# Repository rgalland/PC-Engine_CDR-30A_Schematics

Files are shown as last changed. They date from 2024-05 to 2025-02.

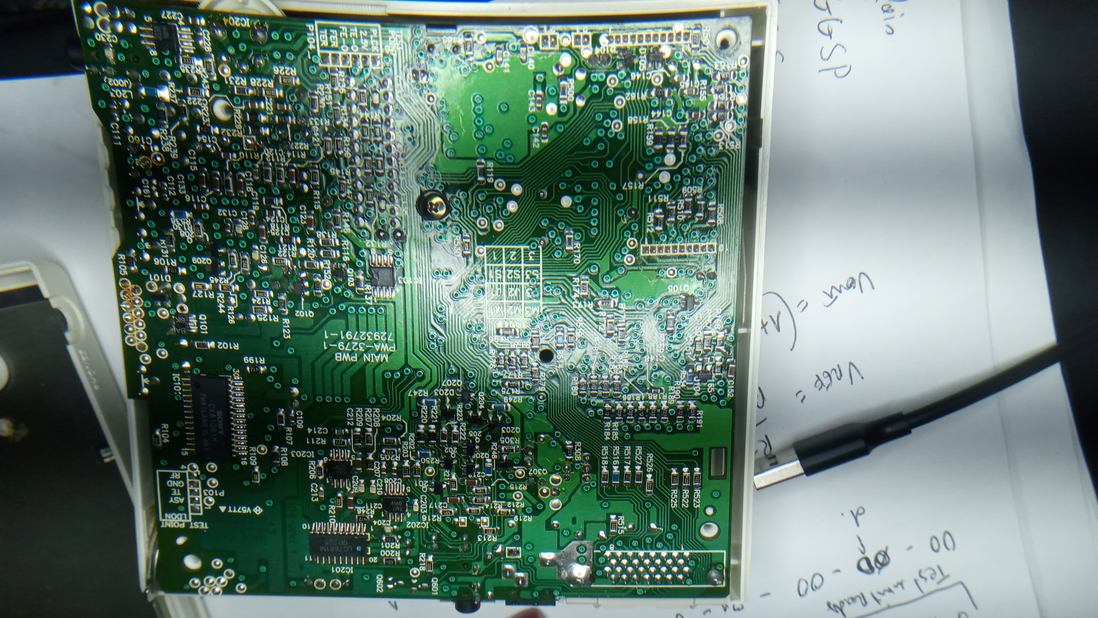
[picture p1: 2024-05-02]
Photos/IMG_20240307_151211.jpg

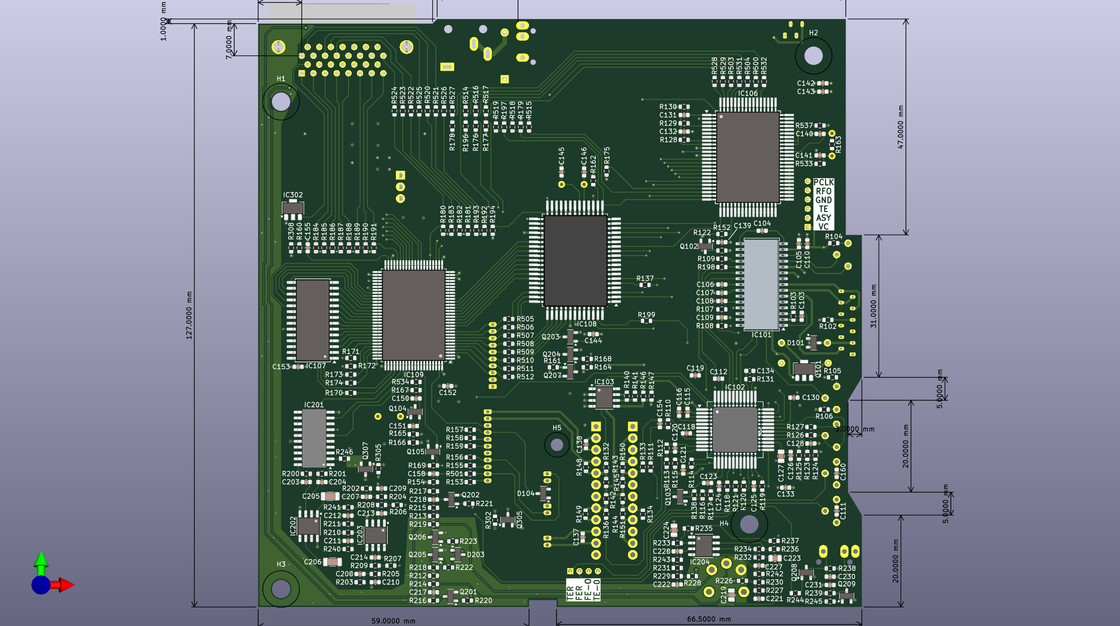
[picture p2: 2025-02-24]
Reproduction_PCBs/Main_PCB/Main_PCB_Bottom.png

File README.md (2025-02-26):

This repository contains reverse engineering information regarding the PC-Engine CD-ROM2.

It started with the schematics of the main and front PCBs but has now evolve to provide reproduction parts. In the schematics, I attempted to highlight the differences between the CDR-30 (older models) and the CDR-30A but I have even found PCB differences within the newer CDR-30A units. Main difference is the use of the Sony DSP CXD1135 + external RAM as opposed to CXD1167 without additional RAM.
Currently available reproduction parts are the 2 flexible PCBs on the KSS-220A laser module. These are not compatible with the KSS-162A found mainly on older units. The main PCB is at the prototype level at the moment.

You will need kicad to work with files but I also provide pdf files to view the schematics in a more convenent way.

Current versions:
Original PCBs:
	- MAIN_PWR schematics: Rev0.3
	- FRONT_PWB schematics: Rev0.1
	
Reproduction PCBs:
	- KSS-220A Focus Tracking Flex PCB schematics and layout: Rev0.1
	- KSS-220A Lens Flex PCB schematics and layout: Rev0.1
	- Main PCB schematics and layout: Rev0.1

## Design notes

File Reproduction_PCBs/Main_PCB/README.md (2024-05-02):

# PC-Engine_CDR-30A_Schematics
Schematics of the PC-Engine CD-ROM2 - Includes comments about differences between CDR-30A and the older CDR-30

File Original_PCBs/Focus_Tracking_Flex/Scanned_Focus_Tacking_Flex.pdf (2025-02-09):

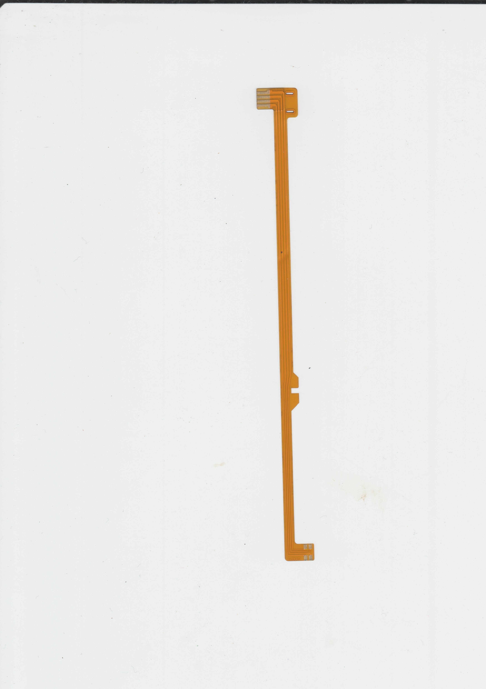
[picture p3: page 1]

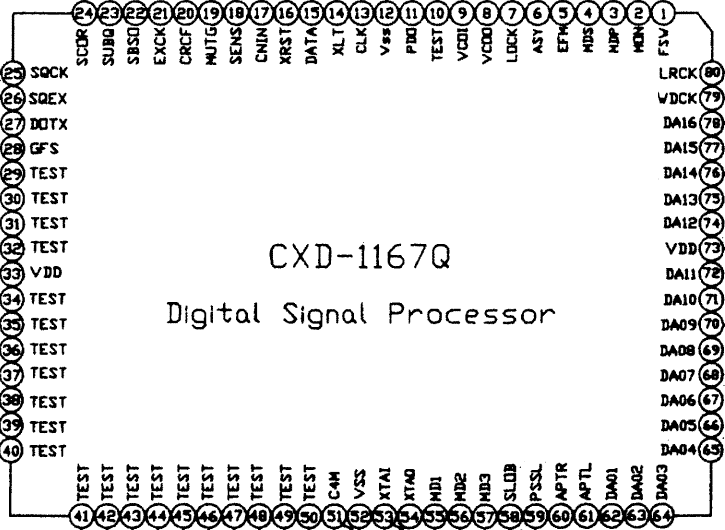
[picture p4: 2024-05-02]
Datasheets/CXD1167/CXD1167Q-pinout.png

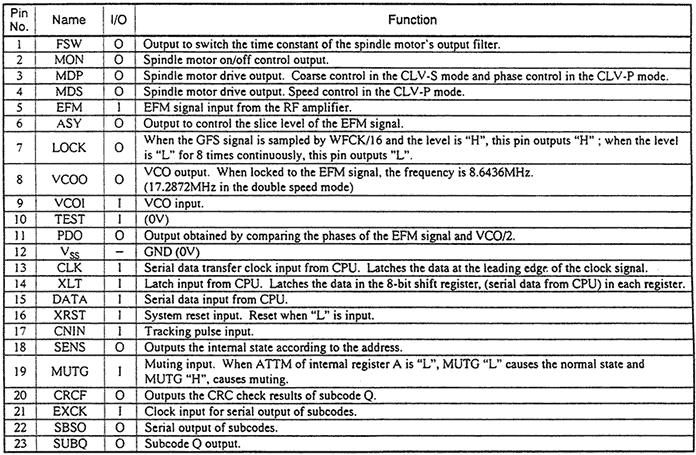
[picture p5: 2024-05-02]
Datasheets/CXD1167/CXD1167-Pin-Functions-1.png

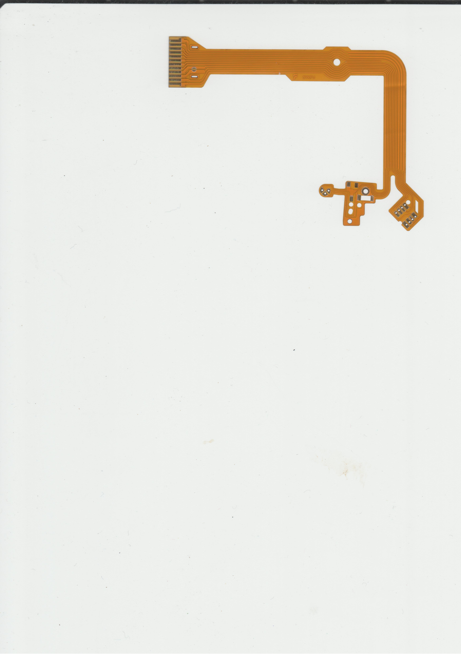
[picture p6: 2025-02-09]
Original_PCBs/Lens_Flex/Scanned_Lens_Flex.png

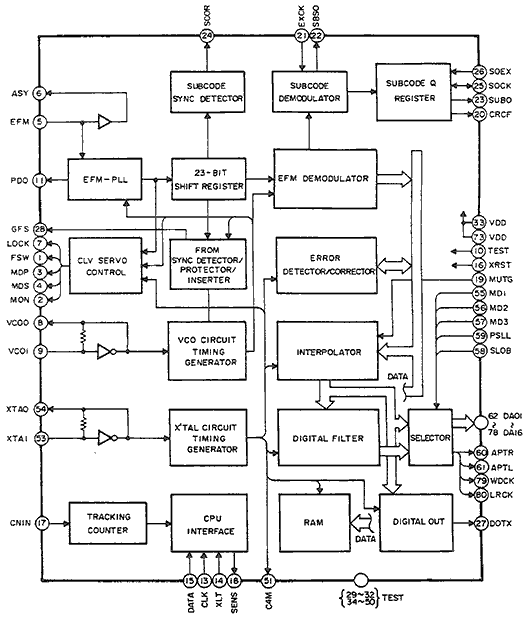
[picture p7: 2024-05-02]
Datasheets/CXD1167/CXD1167-Block-Diagram.png

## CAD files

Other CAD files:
Original_PCBs/Focus_Tracking_Flex/Focus_Tracking_Flex.FCStd
Original_PCBs/Lens_Flex/Lens_Flex.FCStd
Original_PCBs/Focus_Tracking_Flex/flex_focus_tracking_dxf.FCStd
Original_PCBs/Focus_Tracking_Flex/Focus_Tracking_Flex.dxf
Original_PCBs/Lens_Flex/Lens_Flex.dxf

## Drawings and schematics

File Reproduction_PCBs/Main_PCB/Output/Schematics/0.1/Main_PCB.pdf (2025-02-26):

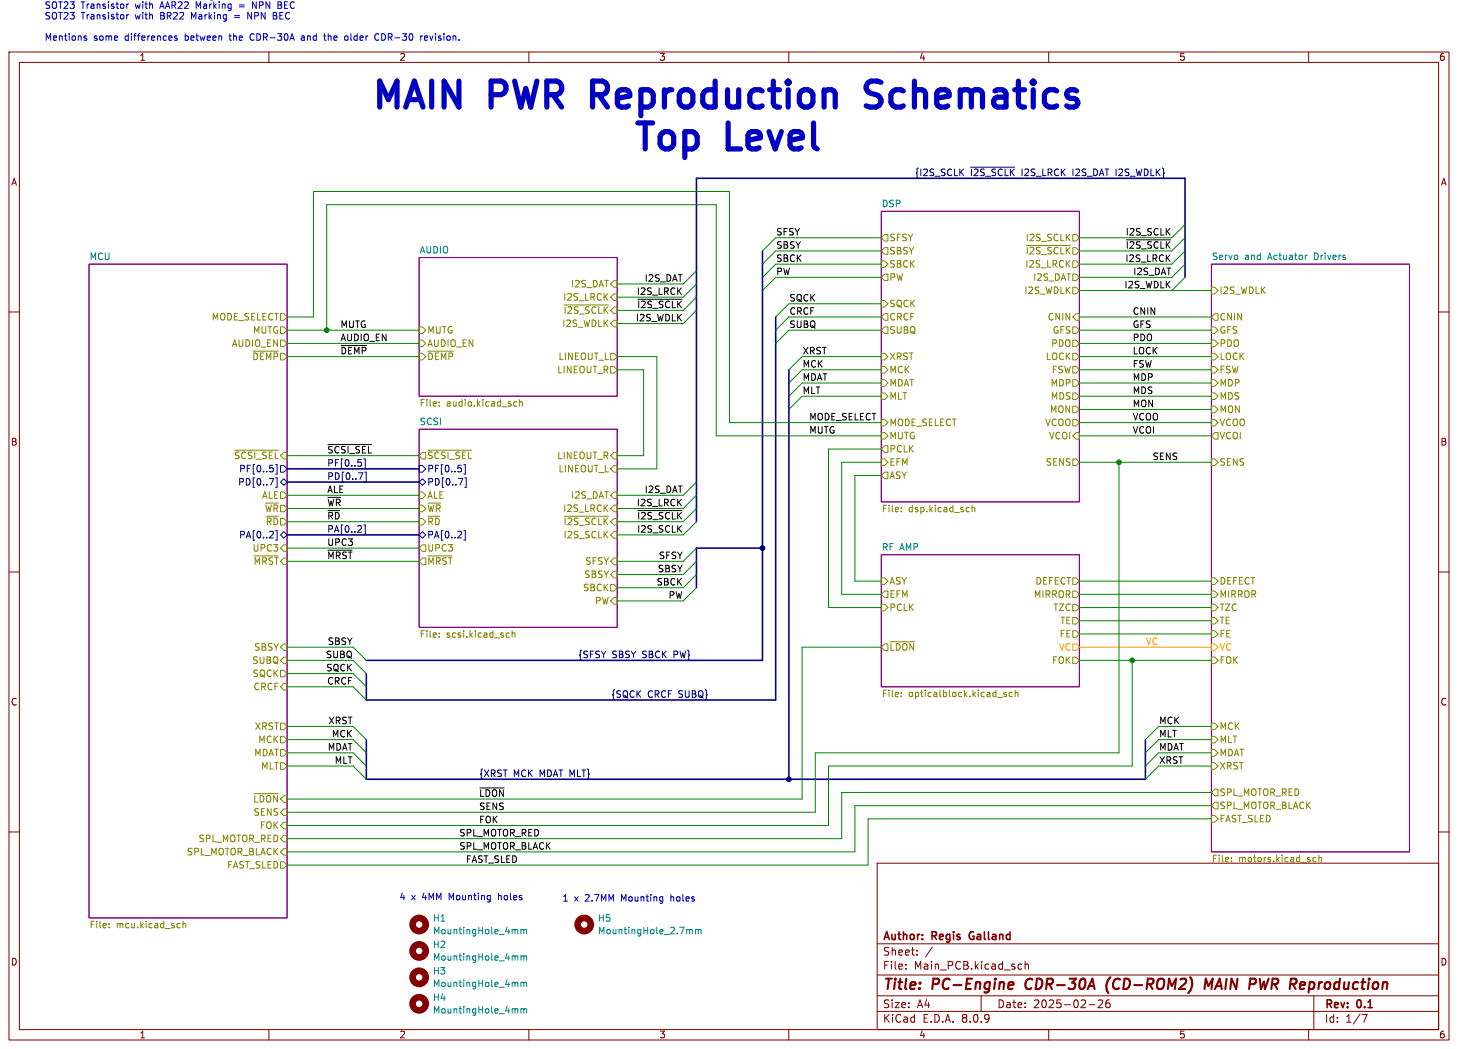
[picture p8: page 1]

1 x 2.7MM Mounting holes MAIN PWR Reproduction Schematics

Servo and Actuator Drivers

GFS CNIN
SENS MDP MON MDS

I2S_DAT AUDIO_EN
LOCK CRCF
SQCK UPC3 ~{SCSI_SEL} CRCF MLT
~{LDON} MDAT XRST PA[0..2] FOK

SBSY
SUBQ
{SQCK CRCF SUBQ} SQCK

{SFSY SBSY SBCK PW}

SPL_MOTOR_BLACK MDAT XRST MCK MLT
SENS MCK

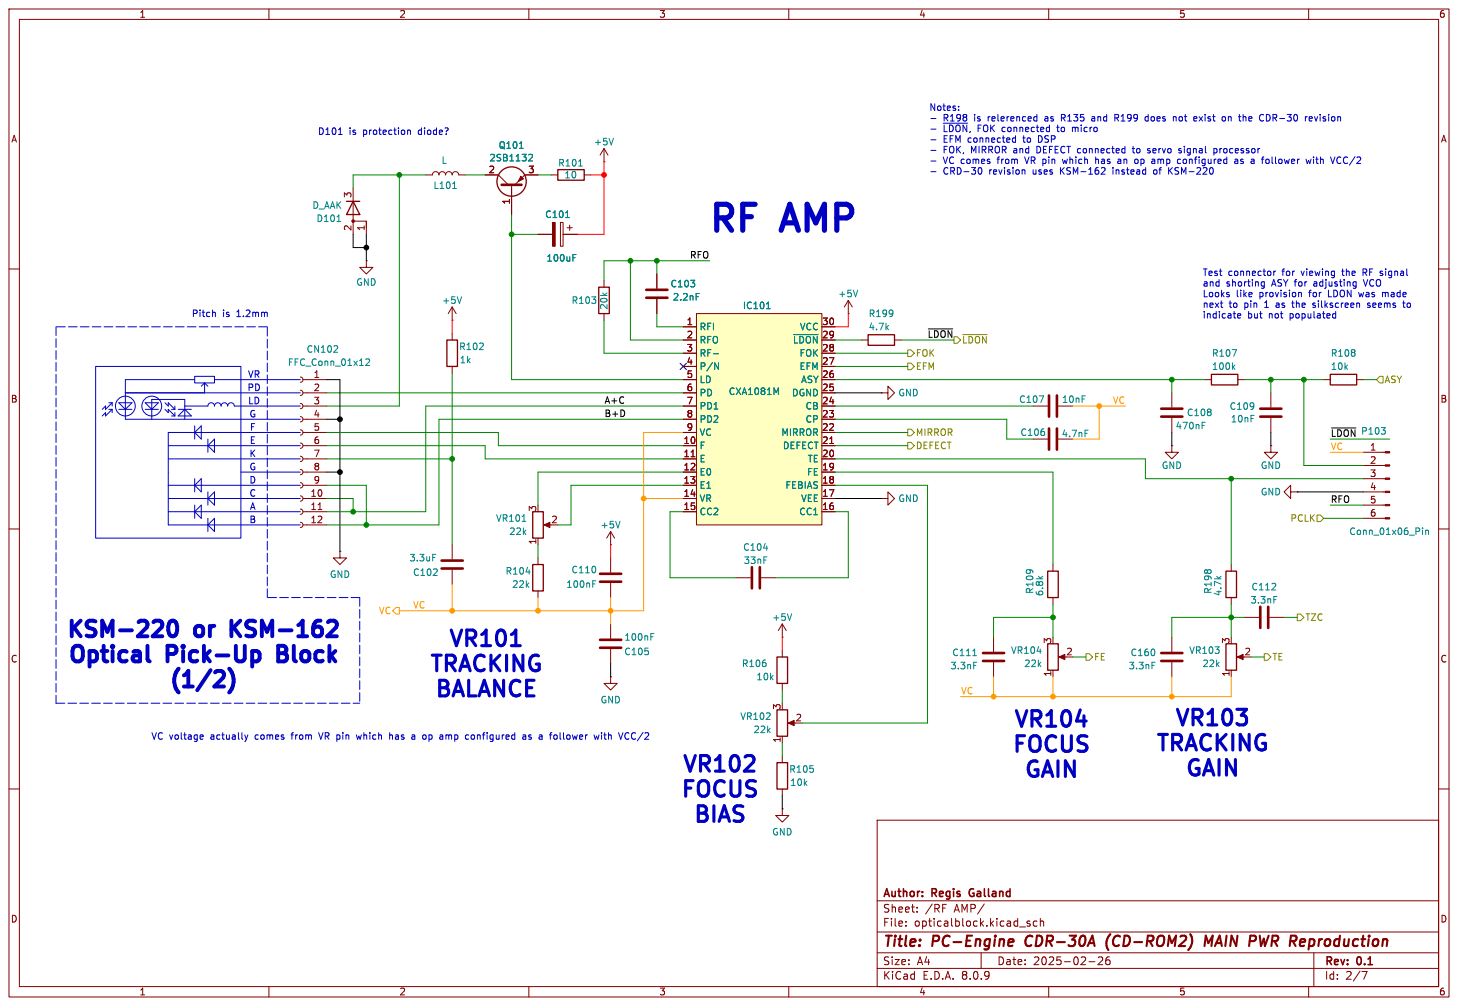
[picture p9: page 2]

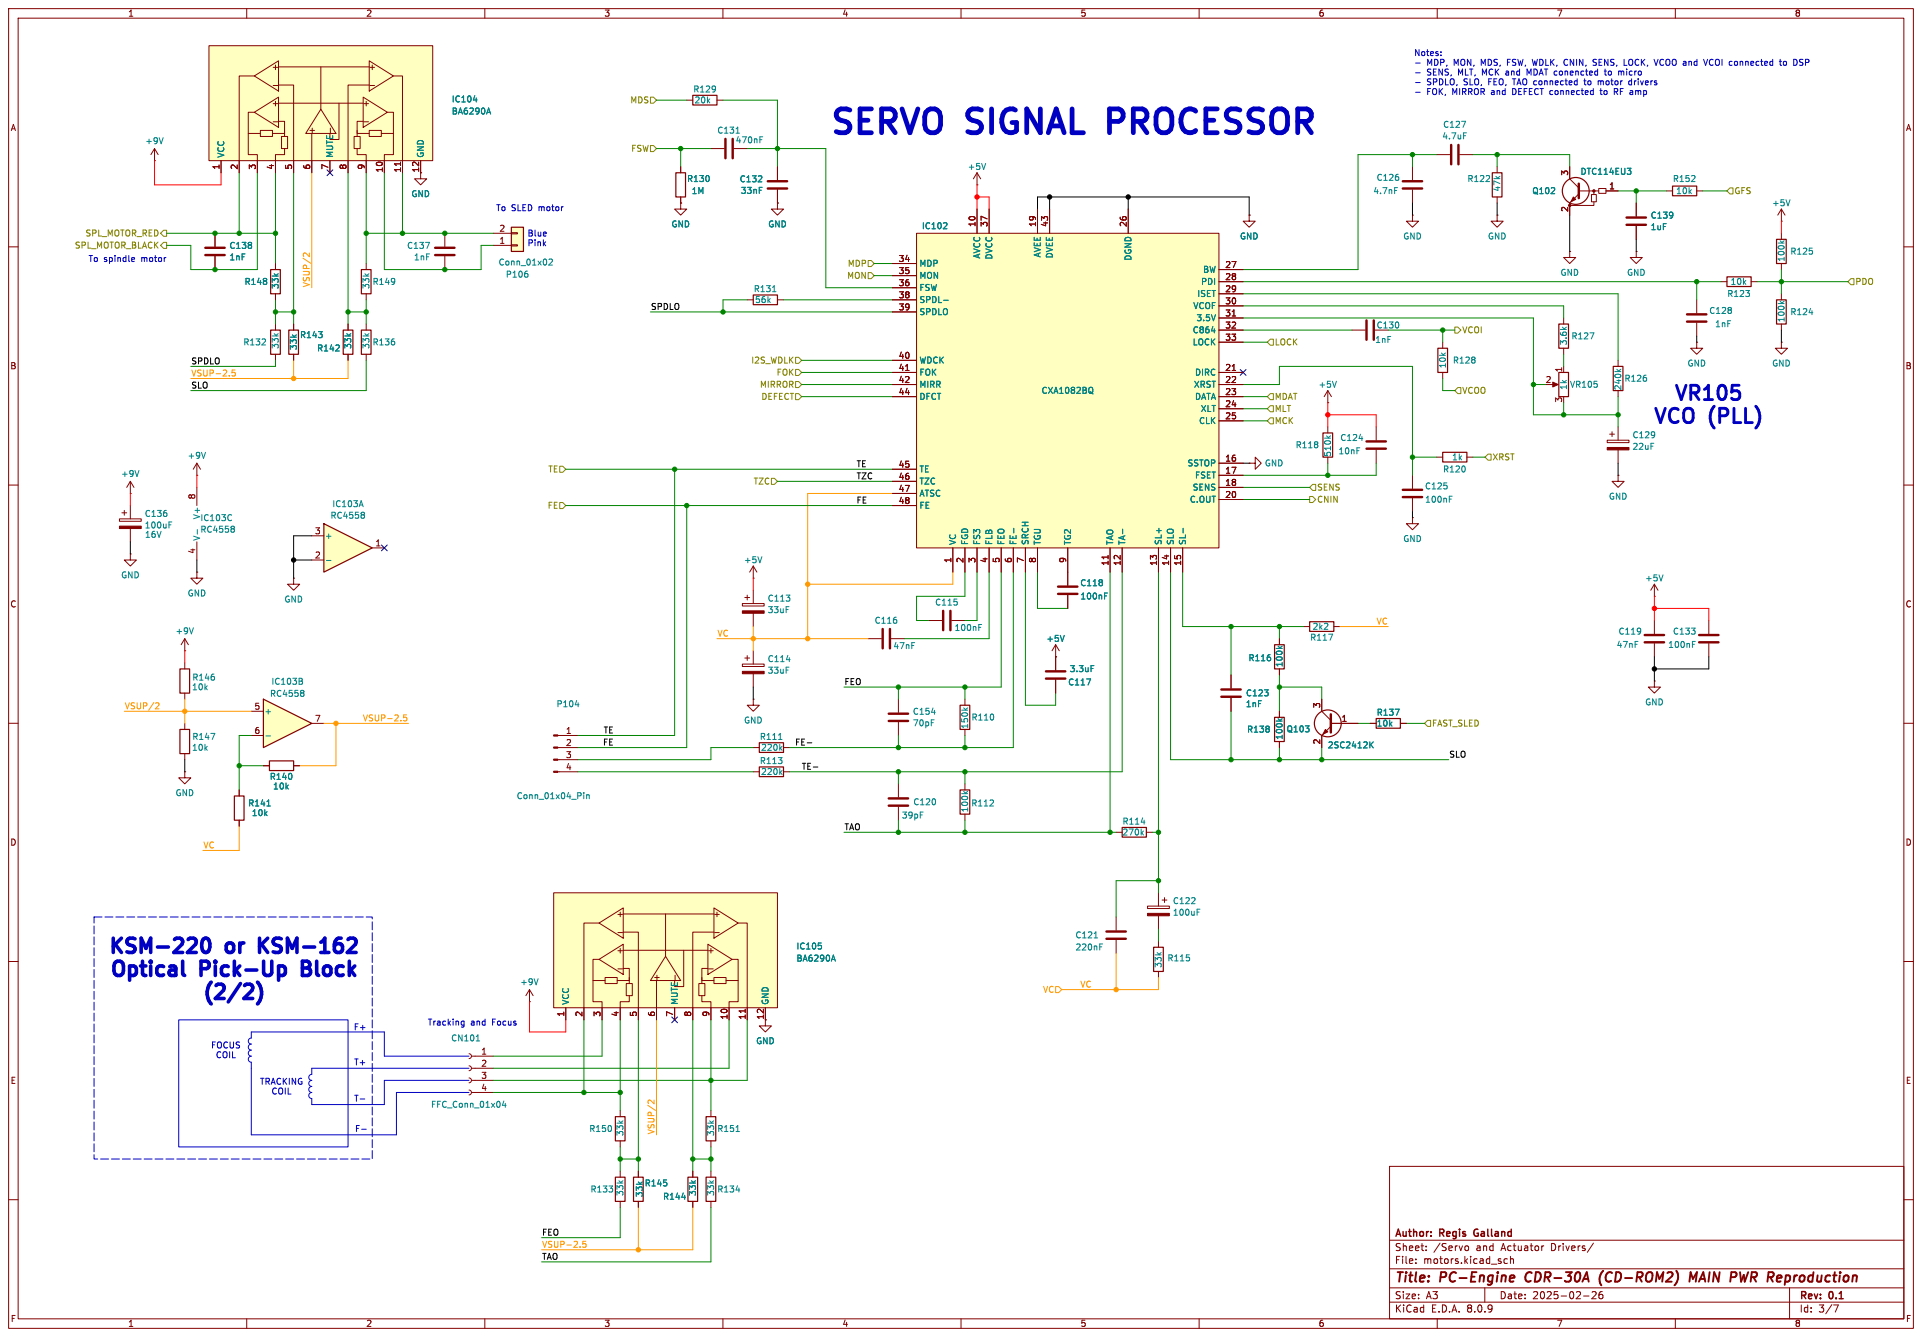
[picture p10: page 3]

Blue Pink To SLED motor

4 WDCK 40 FOK 41 MIRR 42 DVEE 43 DFCT 44 TE 45 TZC 46 ATSC 47 FE 48 FEO

1 AVCC 10 TAO 11 TA- 12 SL+ 13 SLO 14 SL- 15 SSTOP 16 FSET 17 SENS 18 AVEE 19 FGD

2 C.OUT 20 DIRC 21 XRST 22 DATA 23 XLT 24 CLK 25 DGND 26 BW 27 PDI 28

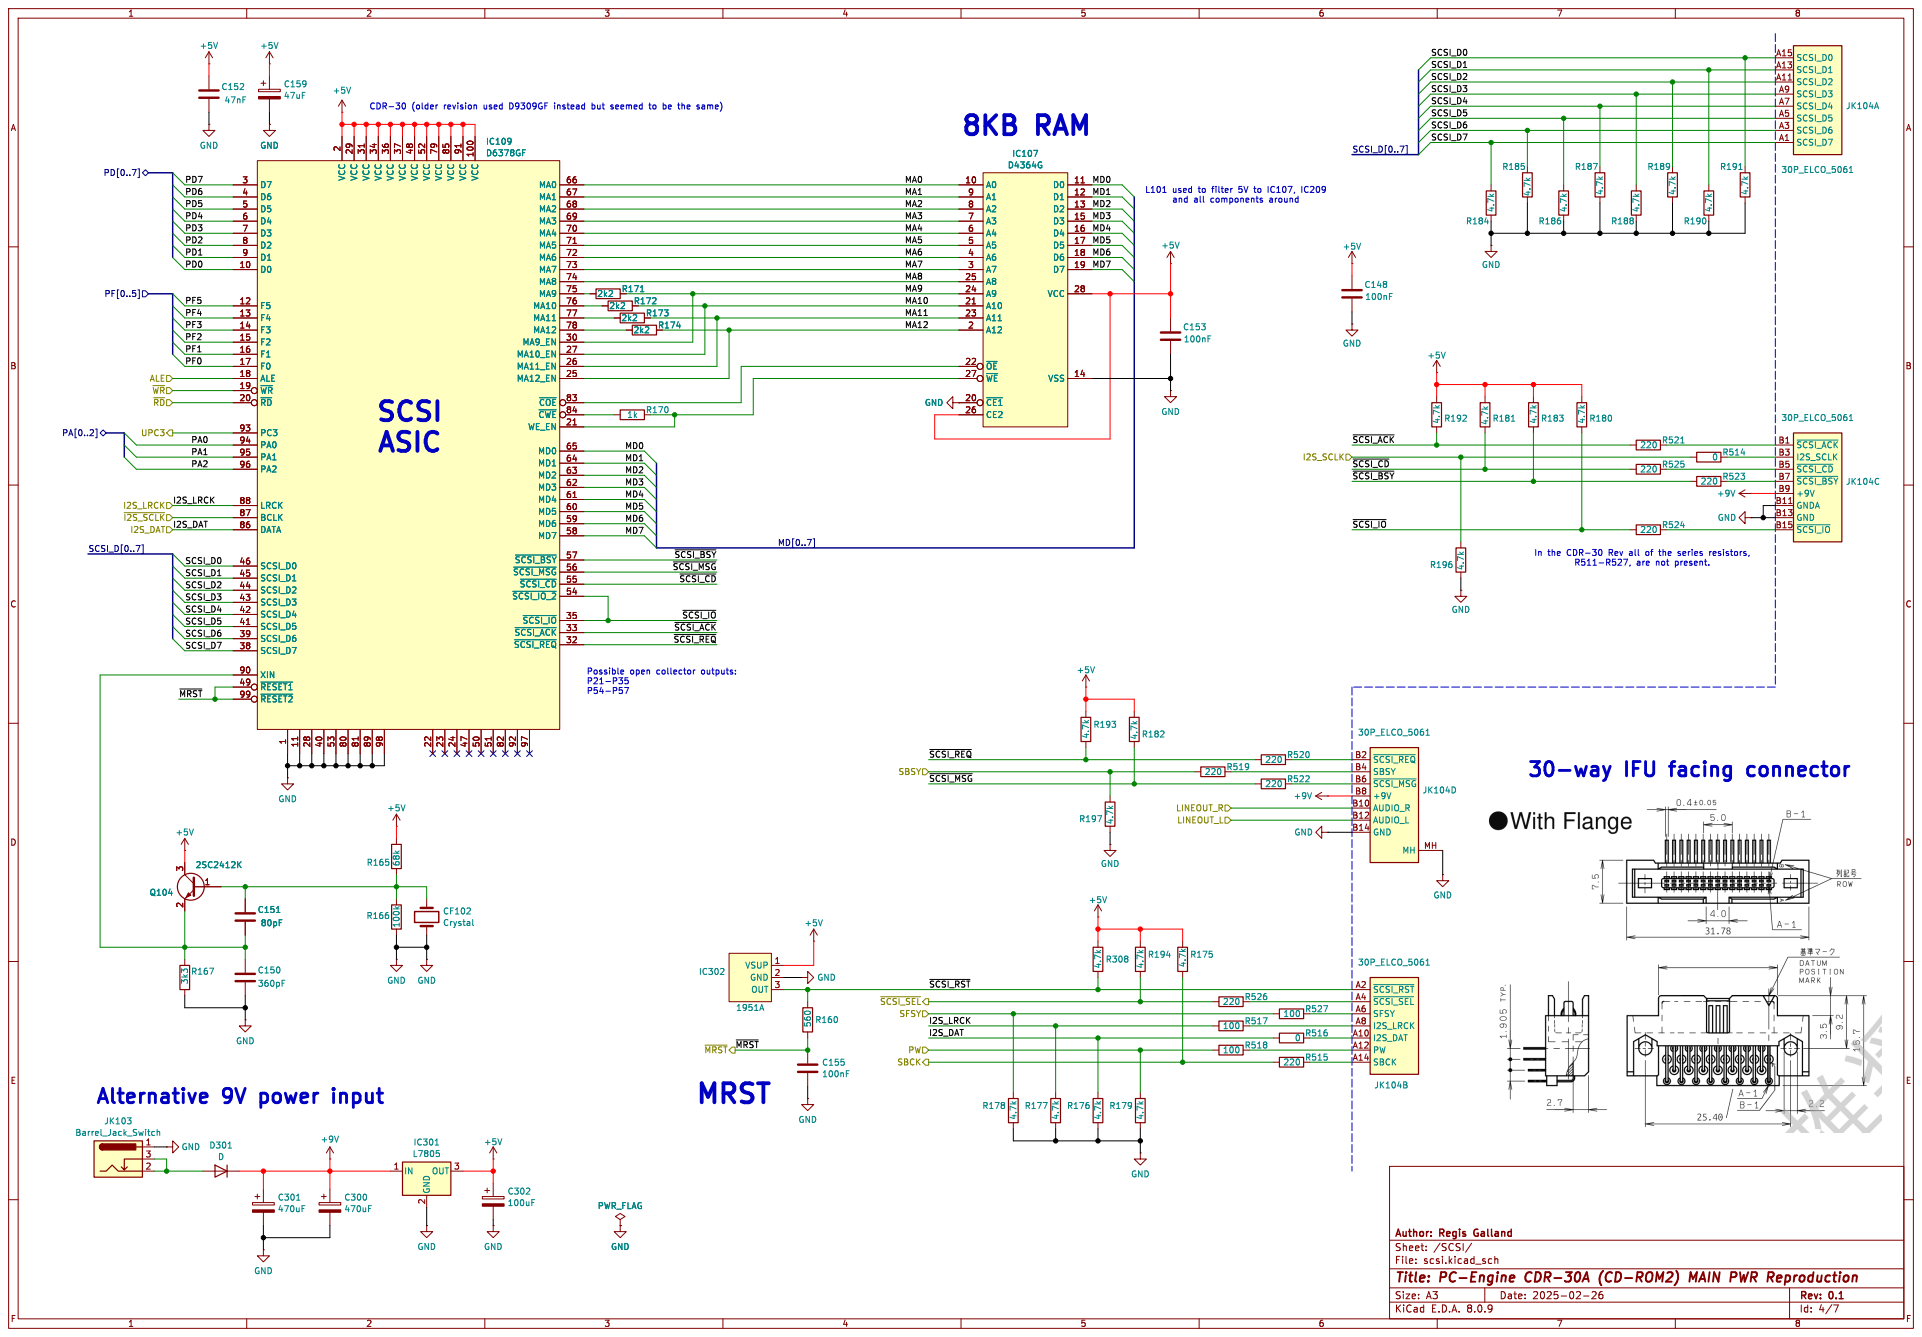
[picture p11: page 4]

1 D0 10 VCC 100 11 F5 12 F4 13 F3 14 F2 15 F1 16 F0 17 ALE 18 ~{WR} 19 VCC

~{COE}83 ~{CWE}84 VCC 85 DATA 86 BCLK 87

2 ~{RD} 20 WE_EN 21 222324 MA12_EN 25 MA11_EN 26 MA10_EN 27 28 VCC 29 D7 3 MA9_EN 30 VCC 31 ~{SCSI_REQ}32 ~{SCSI_ACK}33 VCC 34

L101 used to filter 5V to IC107, IC209

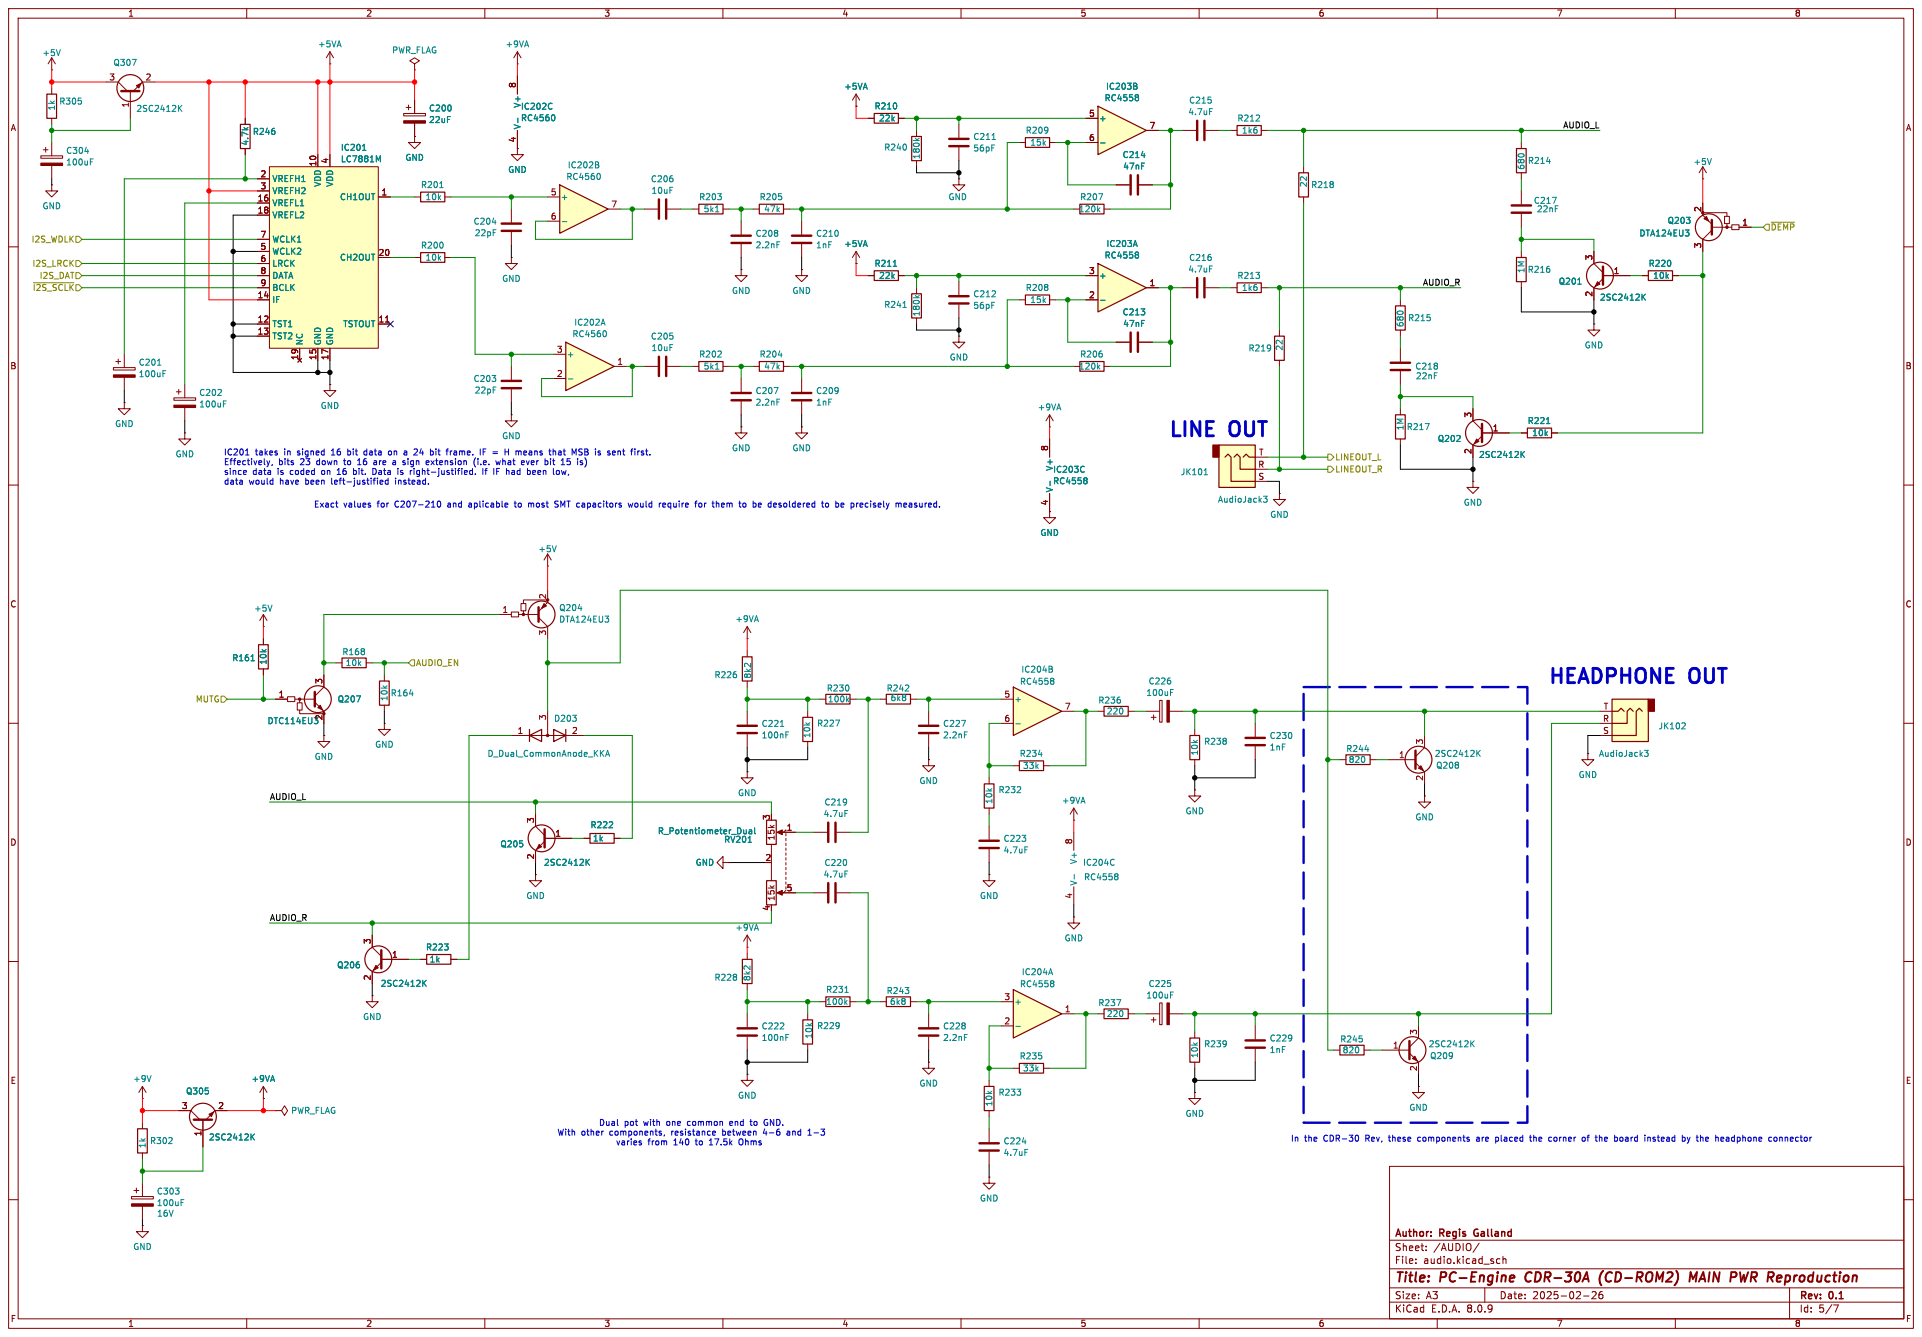
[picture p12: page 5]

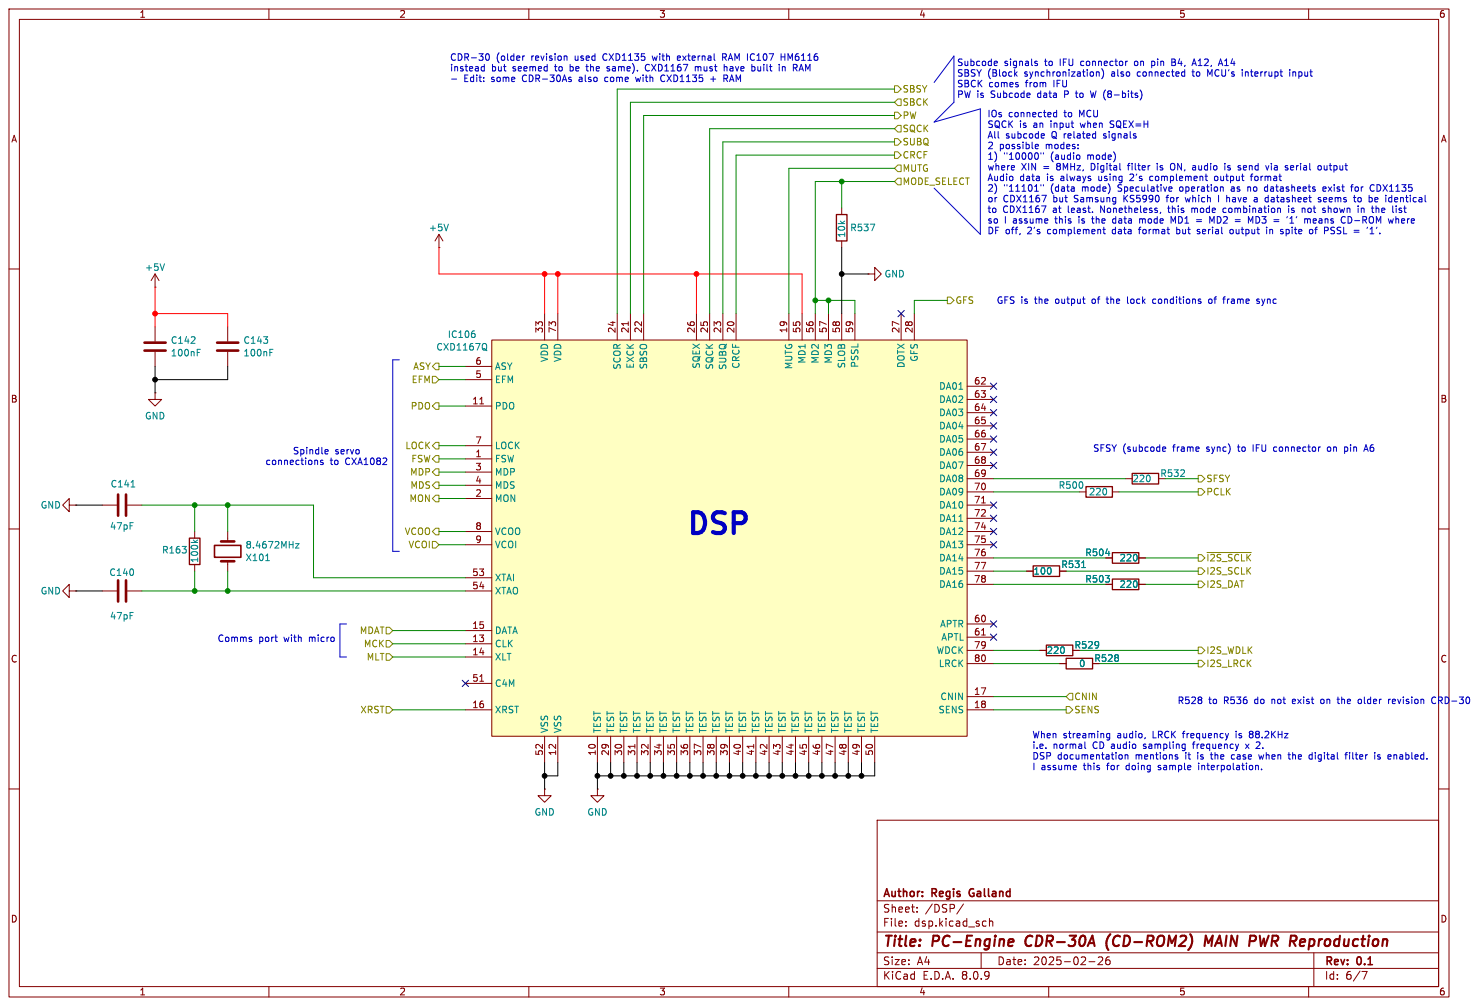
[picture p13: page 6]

instead but seemed to be the same). CXD1167 must have built in RAM
SFSY MODE_SELECT MUTG

SQCK is an input when SQEX=H

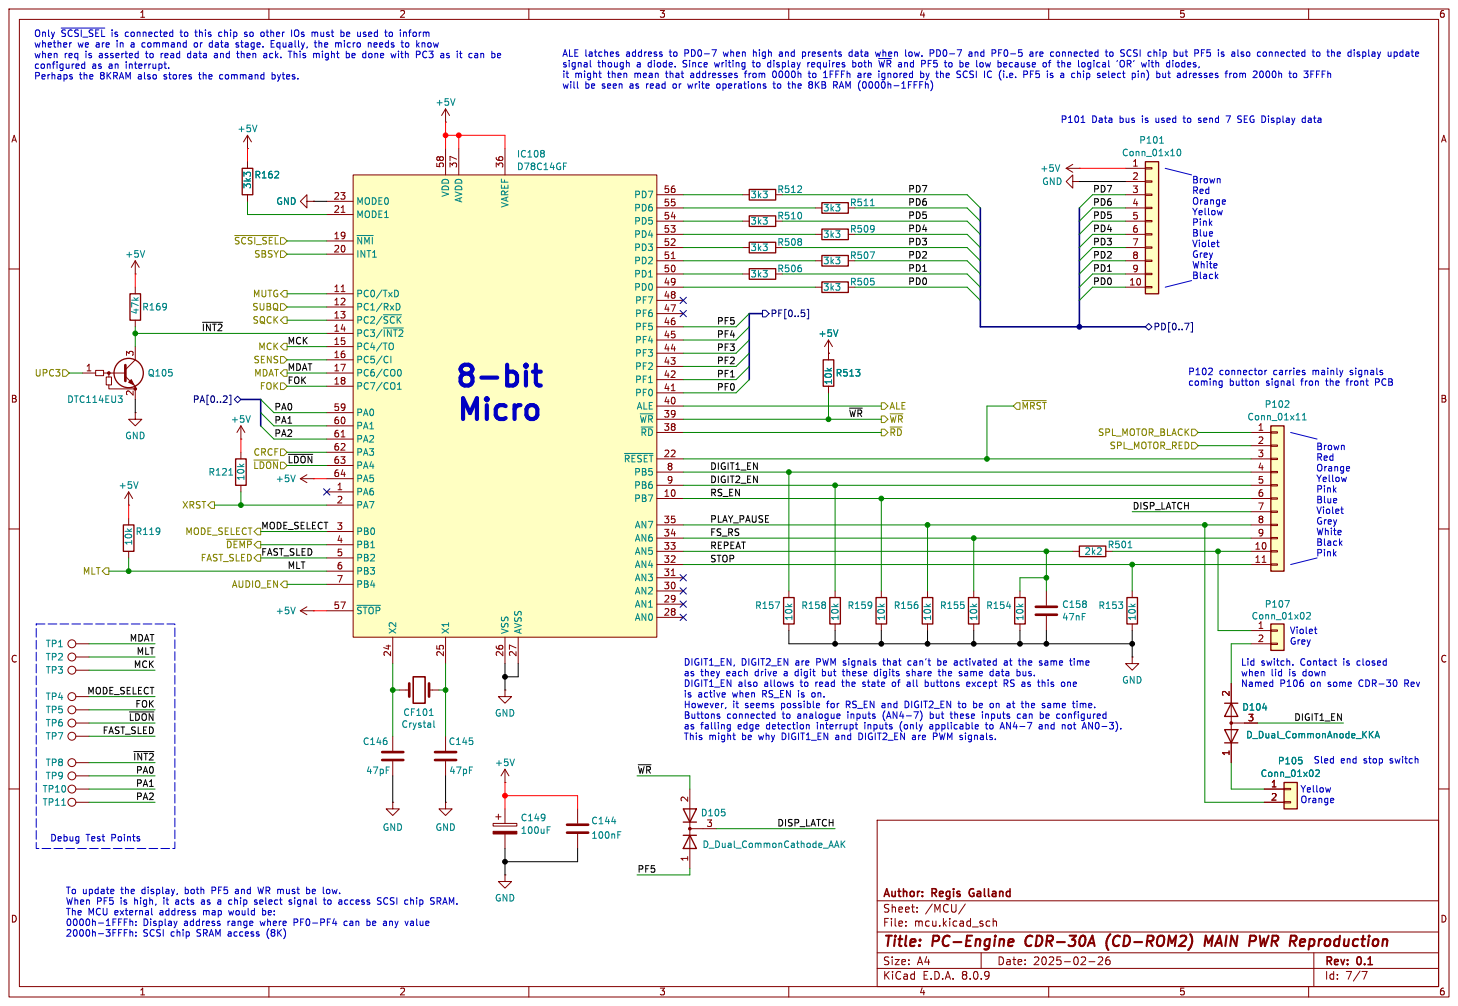
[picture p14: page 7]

whether we are in a command or data stage. Equally, the micro needs to know
when req is asserted to read data and then ack. This might be done with PC3 as it can be
~{SCSI_SEL} XRST
FOK MDAT SBSY

Brown Red Orange Yellow

Pink Blue Violet Grey White Black 8-bit

coming button signal fron the front PCB

Yellow Orange Sled end stop switch Violet Grey

as they each drive a digit but these digits share the same data bus. DIGIT1_EN also allows to read the state of all buttons except RS as this one

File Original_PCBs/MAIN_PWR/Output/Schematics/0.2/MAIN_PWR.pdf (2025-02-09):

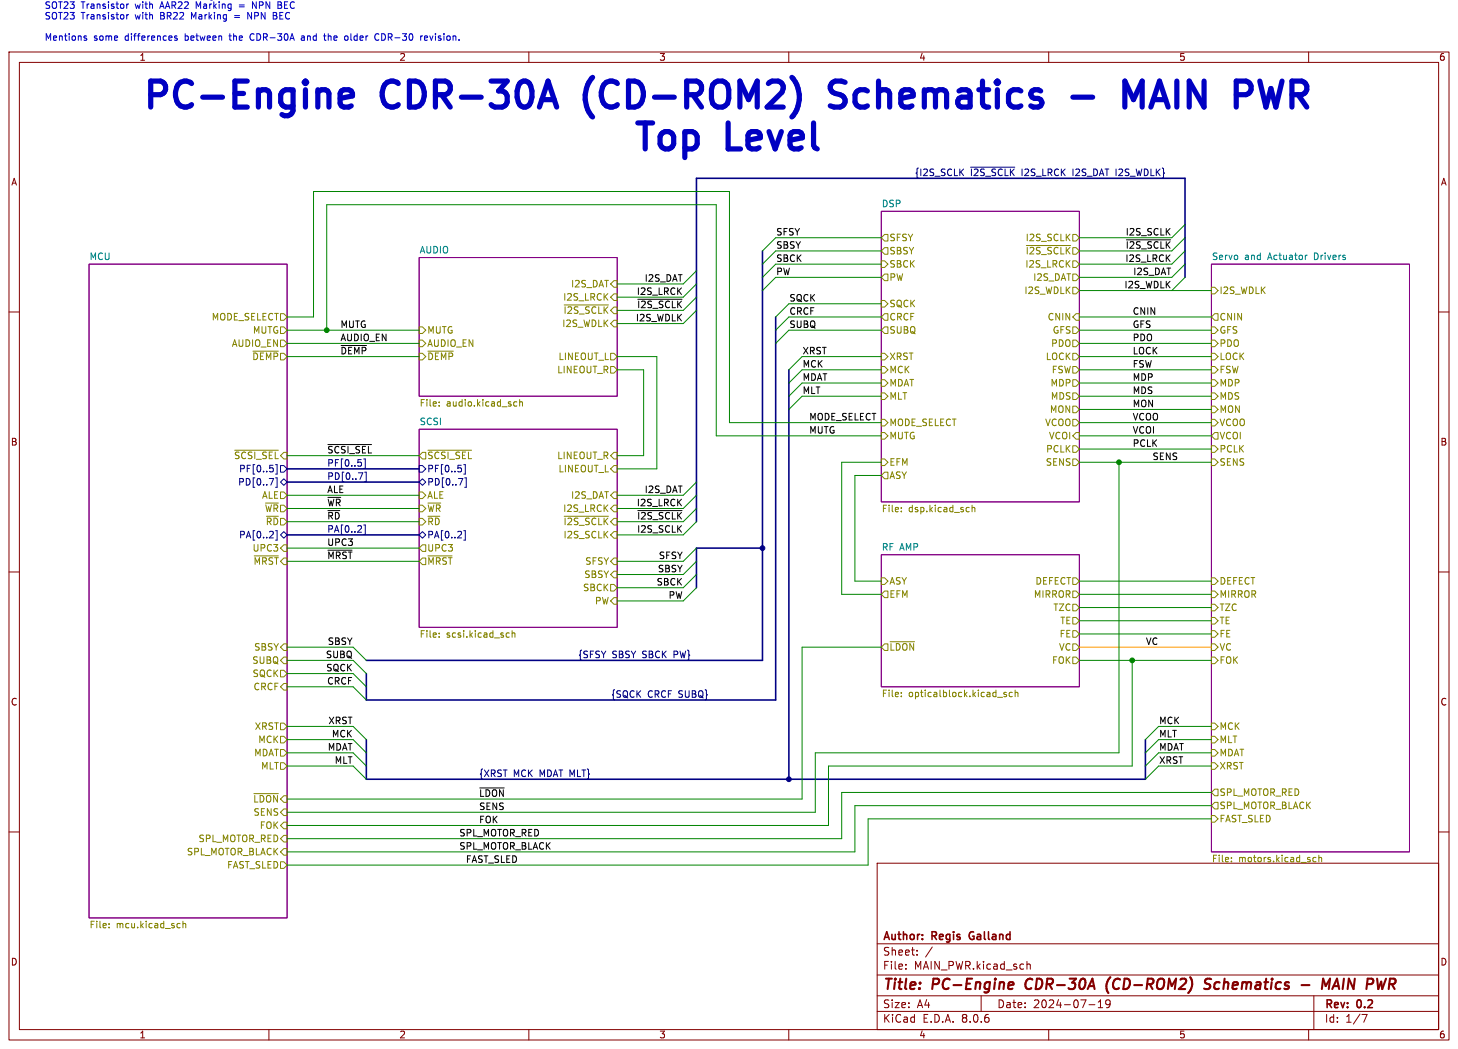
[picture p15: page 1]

Servo and Actuator Drivers

I2S_WDLK
VCOO MON MDS CNIN GFS

SQCK UPC3 ~{SCSI_SEL} CRCF MLT
~{LDON} MDAT XRST PA[0..2] FOK

{SFSY SBSY SBCK PW}

{XRST MCK MDAT MLT}

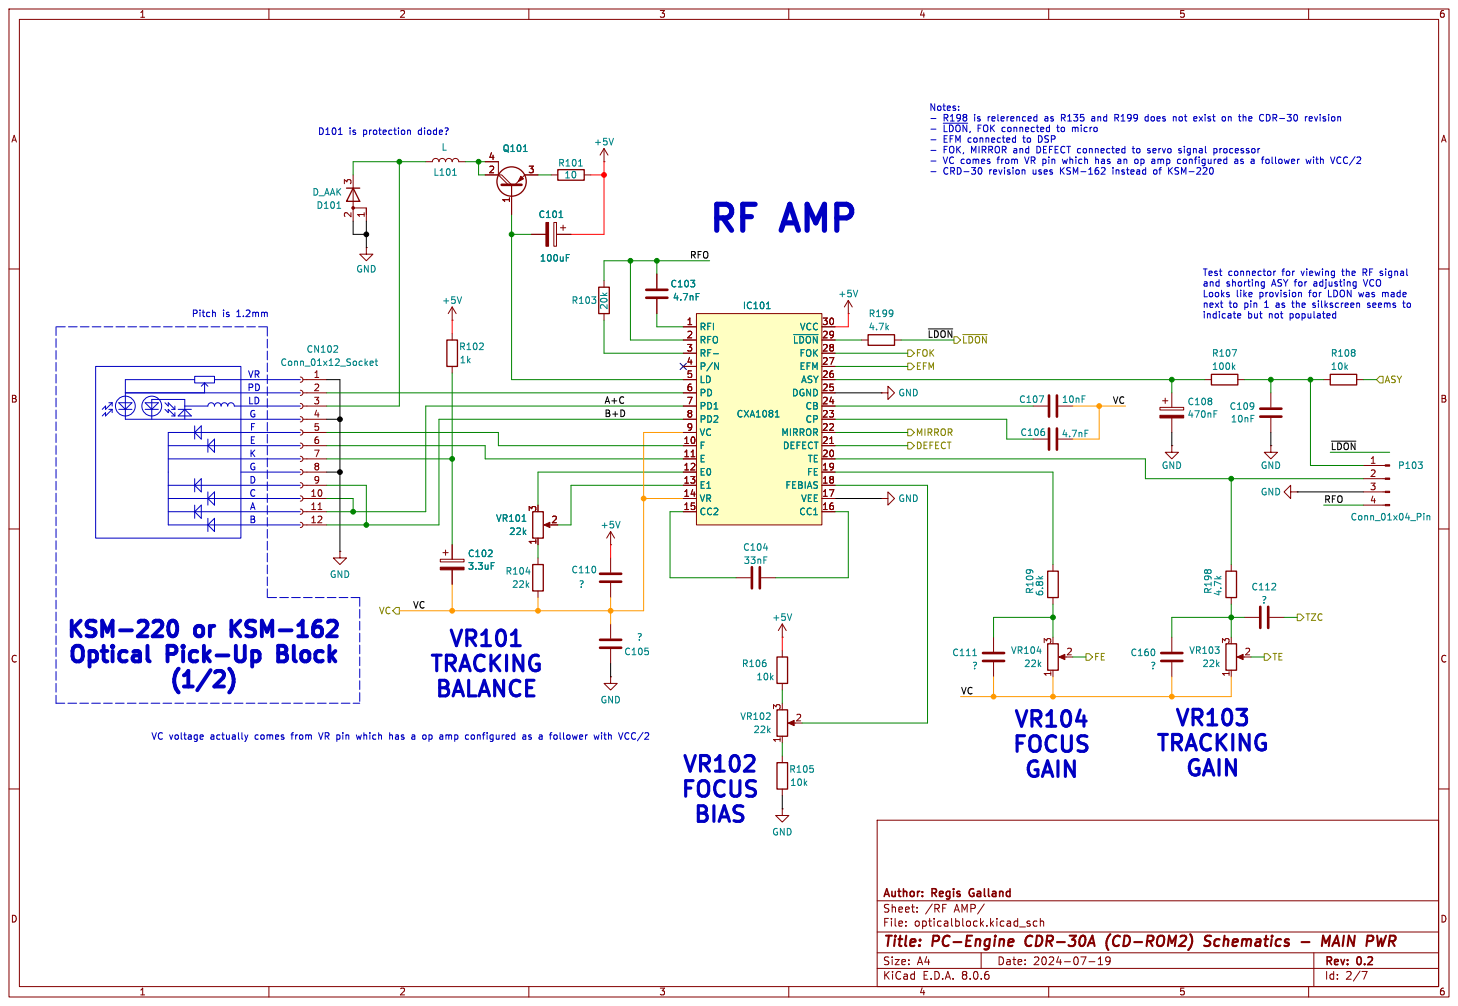
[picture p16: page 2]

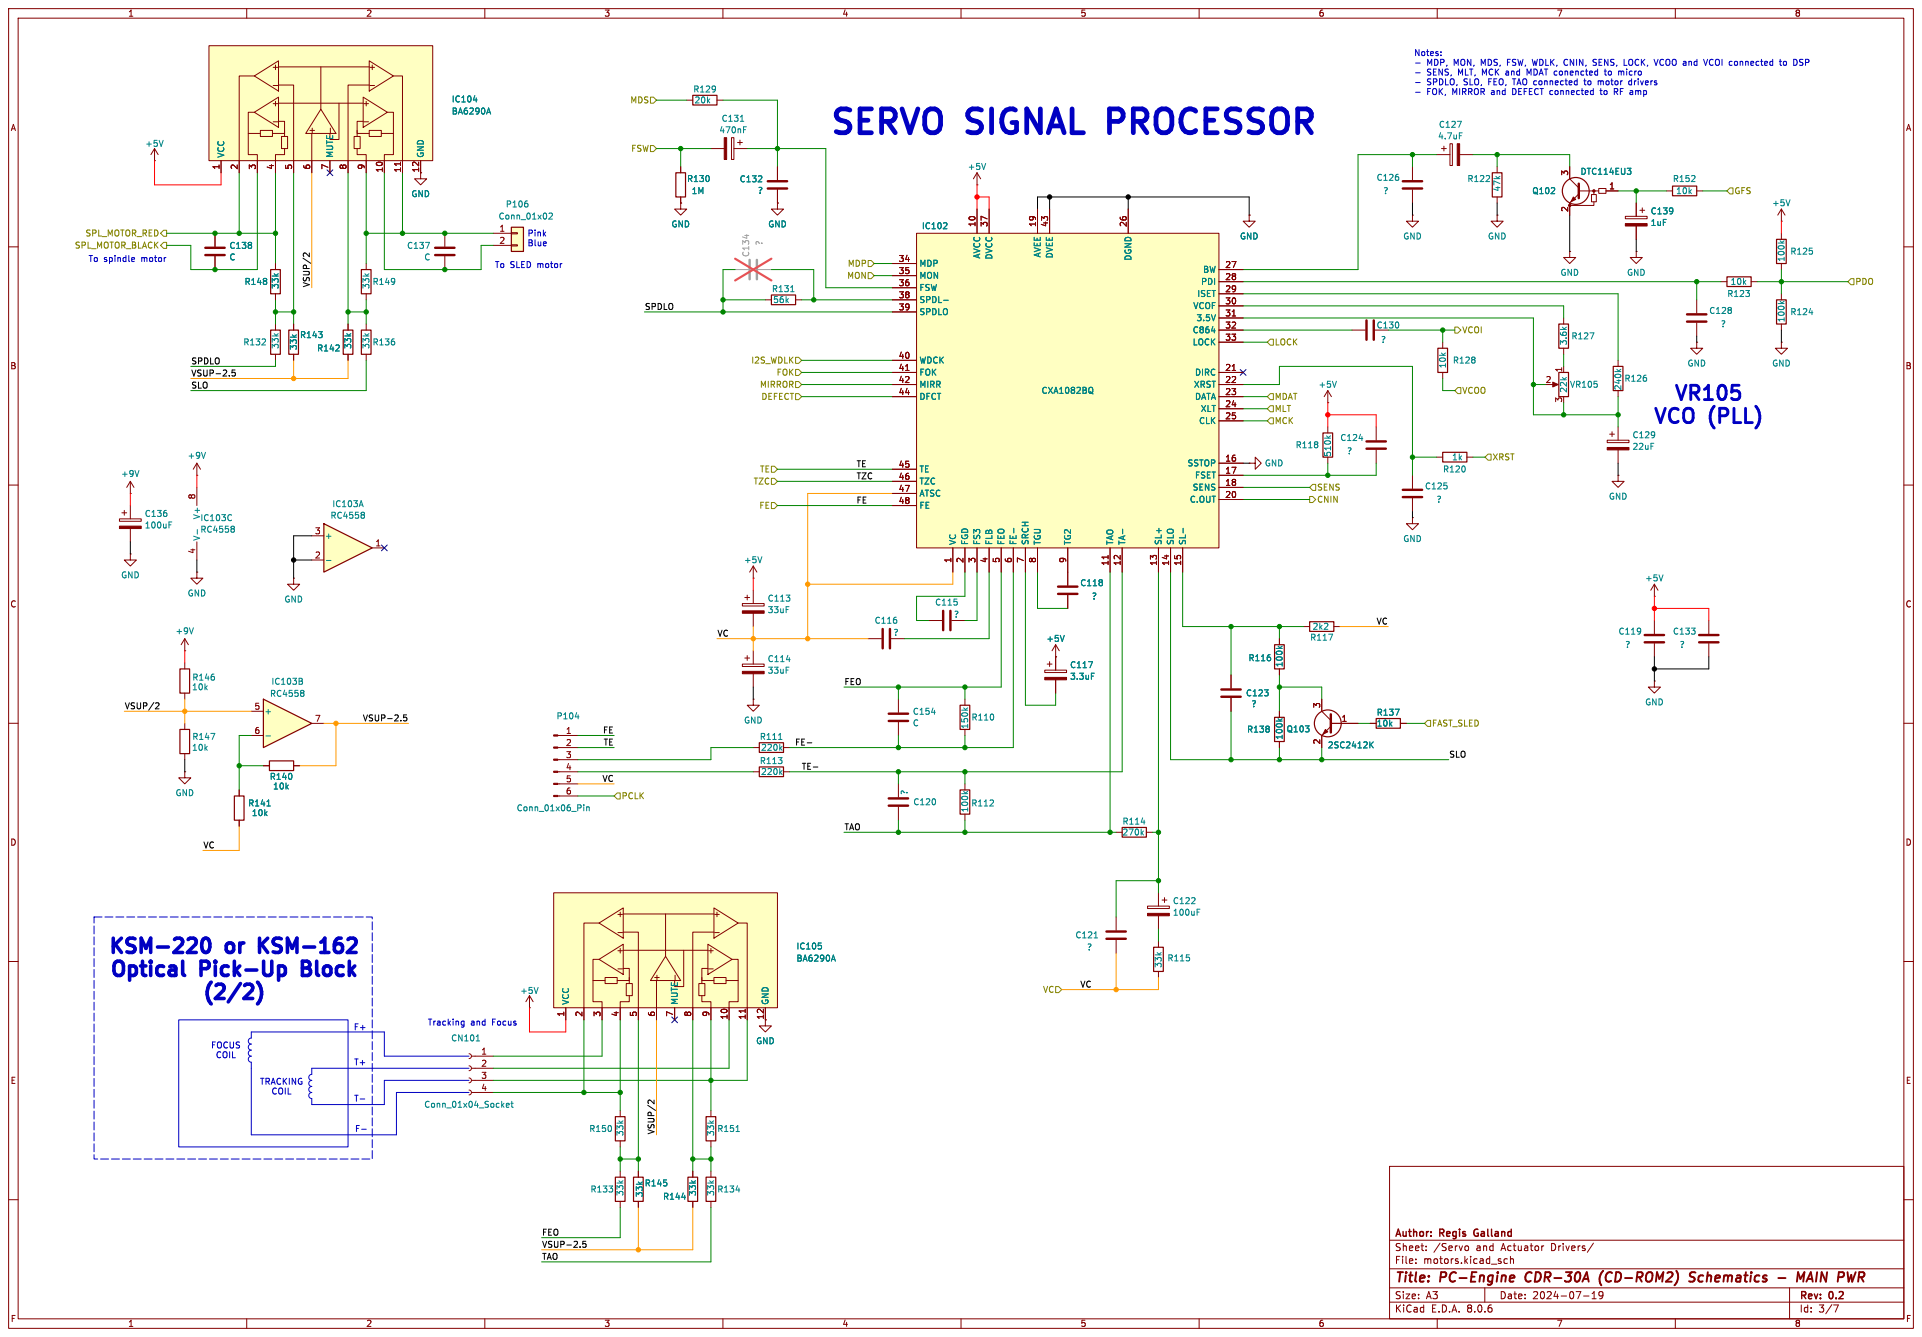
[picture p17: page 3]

4 WDCK 40 FOK 41 MIRR 42 DVEE 43 DFCT 44 TE 45 TZC 46 ATSC 47 FE 48 FEO

1 AVCC 10 TAO 11 TA- 12 SL+ 13 SLO 14 SL- 15 SSTOP 16 FSET 17 SENS 18 AVEE 19 FGD

2 C.OUT 20 DIRC 21 XRST 22 DATA 23 XLT 24 CLK 25 DGND 26 BW 27 PDI 28

Tracking and Focus T+ TRACKING

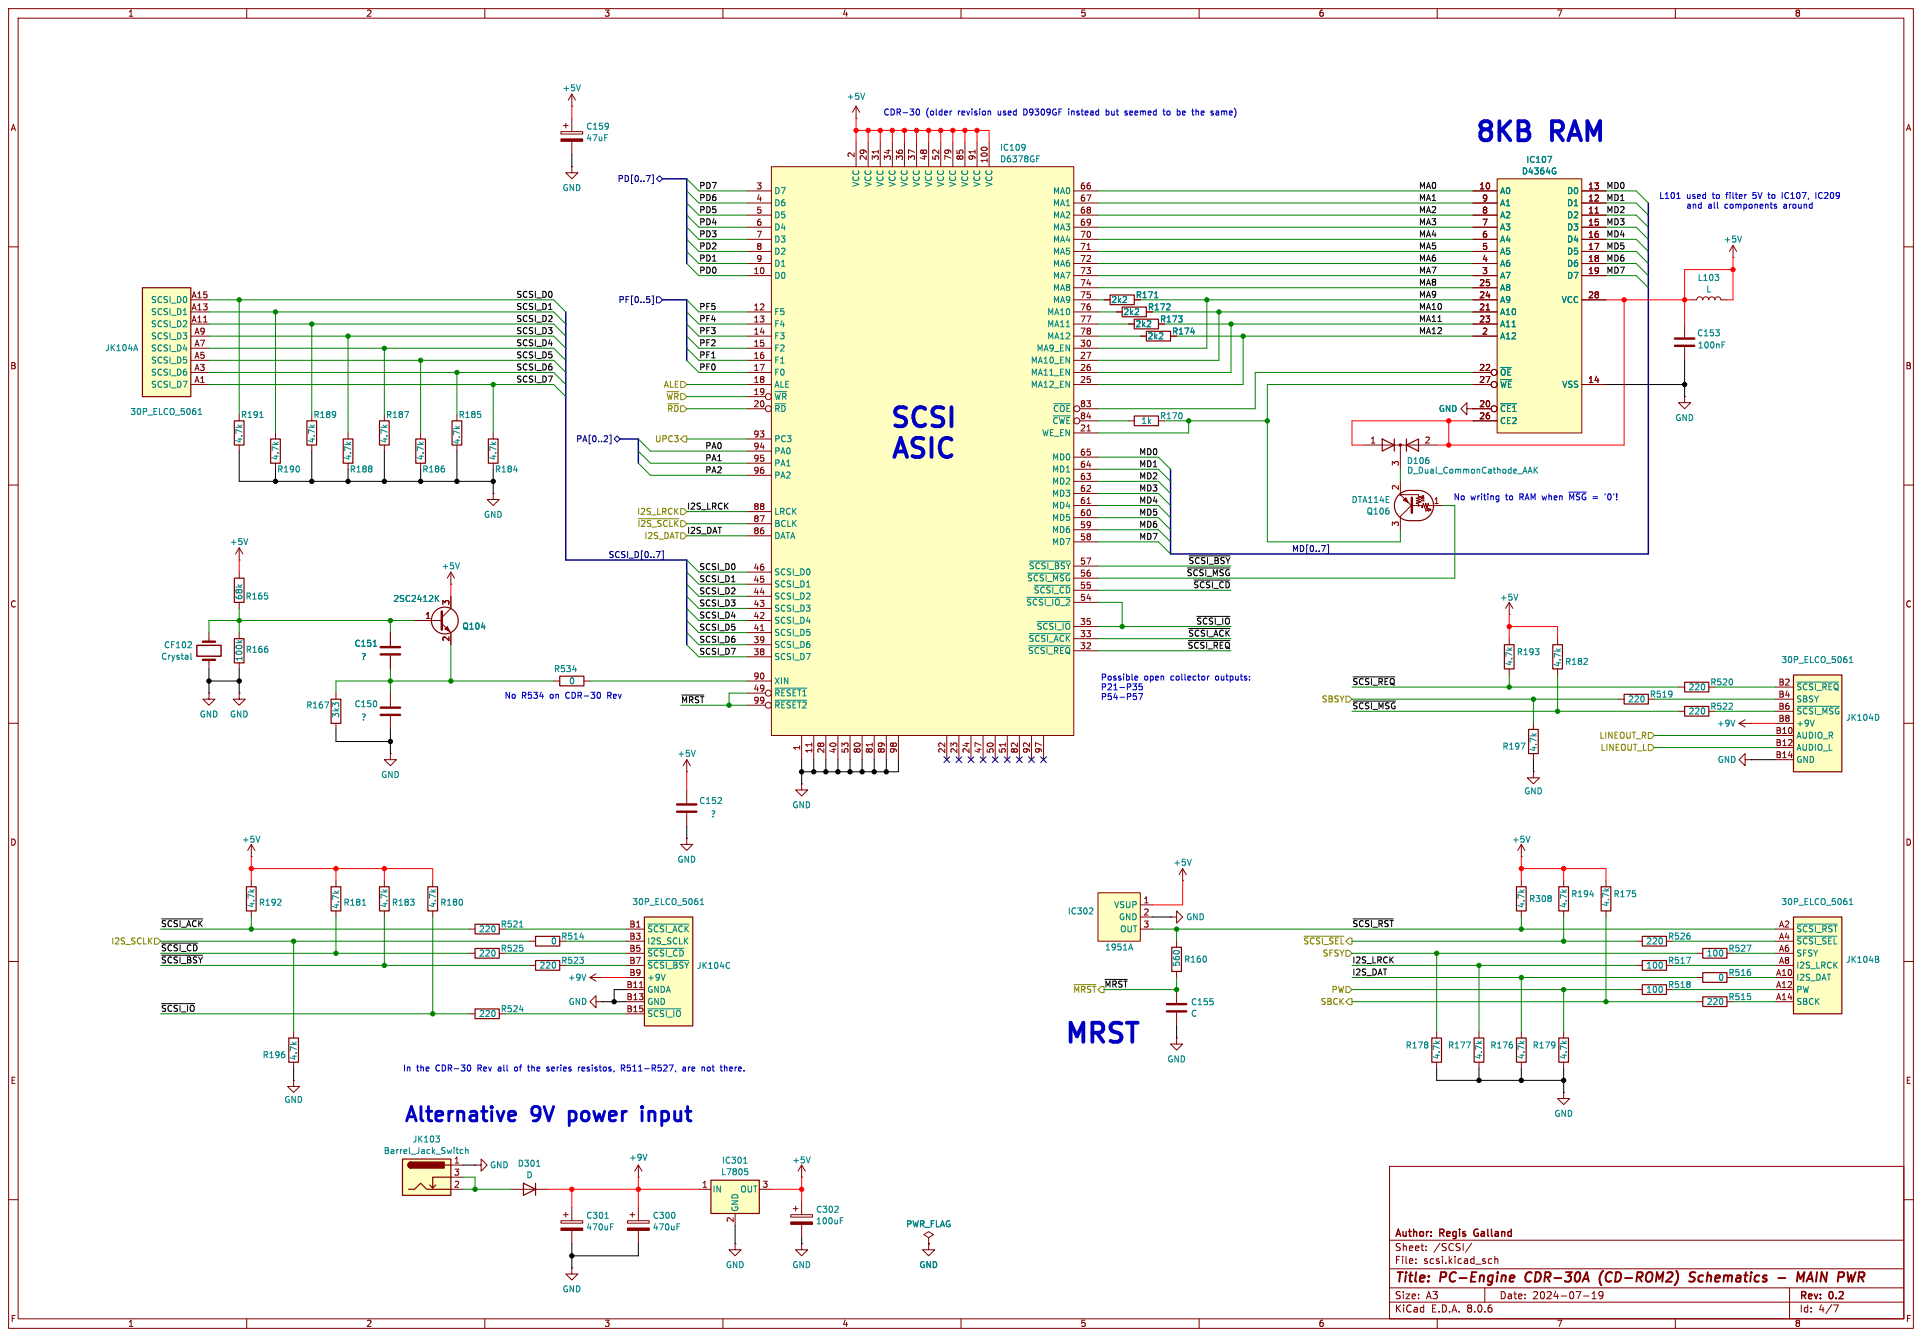
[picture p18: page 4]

1 D0 10 VCC 100 11 F5 12 F4 13 F3 14 F2 15 F1 16 F0 17 ALE 18 ~{WR} 19 VCC

2 ~{RD} 20 WE_EN 21 222324 MA12_EN 25 MA11_EN 26 MA10_EN 27 28 VCC 29 D7 3 MA9_EN 30 VCC 31 ~{SCSI_REQ}32 ~{SCSI_ACK}33 VCC 34

L101 used to filter 5V to IC107, IC209

No writing to RAM when ~{MSG}= '0'!

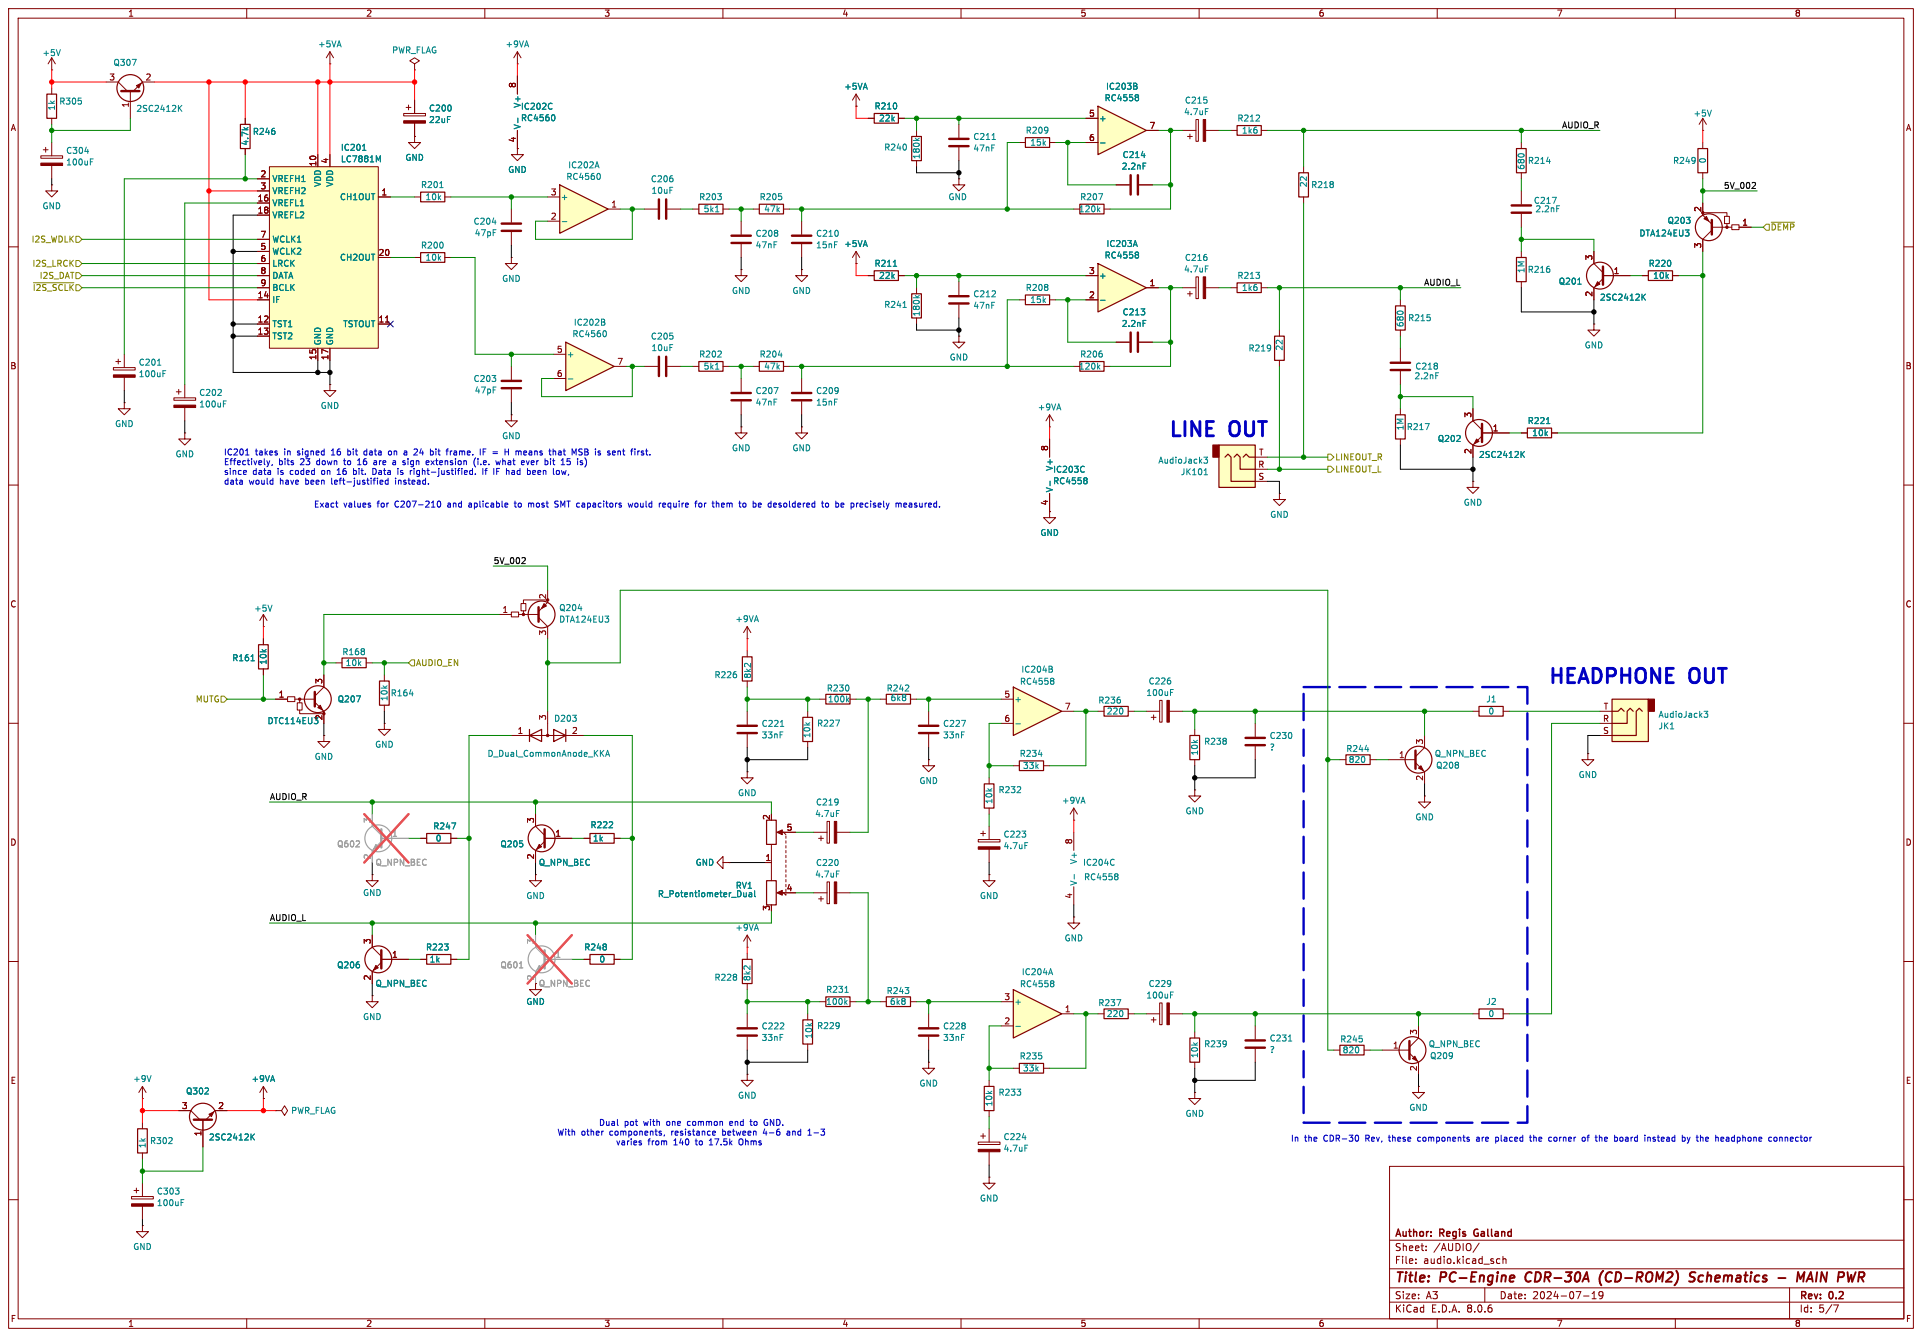
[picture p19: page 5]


instead but seemed to be the same). CXD1167 must have built in RAM

SQCK is an input when SQEX=H

I assume this for doing sample interpolation.


whether we are in a command or data stage. Equally, the micro needs to know
when req is asserted to read data and then ack. This might be done with PC3 as it can be

Brown Red Orange Yellow

coming button signal fron the front PCB

as they each drive a digit but these digits share the same data bus. DIGIT1_EN also allows to read the state of all buttons except RS as this one

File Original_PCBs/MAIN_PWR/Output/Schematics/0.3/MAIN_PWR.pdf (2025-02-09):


Servo and Actuator Drivers

I2S_WDLK
VCOO MON MDS CNIN GFS

SQCK UPC3 ~{SCSI_SEL} CRCF MLT
~{LDON} MDAT XRST PA[0..2] FOK

{SFSY SBSY SBCK PW}

{XRST MCK MDAT MLT}



4 WDCK 40 FOK 41 MIRR 42 DVEE 43 DFCT 44 TE 45 TZC 46 ATSC 47 FE 48 FEO

1 AVCC 10 TAO 11 TA- 12 SL+ 13 SLO 14 SL- 15 SSTOP 16 FSET 17 SENS 18 AVEE 19 FGD

2 C.OUT 20 DIRC 21 XRST 22 DATA 23 XLT 24 CLK 25 DGND 26 BW 27 PDI 28

TZC VSUP/2 VSUP/2 SLO

Tracking and Focus TRACKING


1 D0 10 VCC 100 11 F5 12 F4 13 F3 14 F2 15 F1 16 F0 17 ALE 18 ~{WR} 19 VCC

~{COE}83 ~{CWE}84 VCC 85 DATA 86 BCLK 87

2 ~{RD} 20 WE_EN 21 222324 MA12_EN 25 MA11_EN 26 MA10_EN 27 28 VCC 29 D7 3 MA9_EN 30 VCC 31 ~{SCSI_REQ}32 ~{SCSI_ACK}33 VCC 34

L101 used to filter 5V to IC107, IC209



instead but seemed to be the same). CXD1167 must have built in RAM

SQCK is an input when SQEX=H

I assume this for doing sample interpolation.


whether we are in a command or data stage. Equally, the micro needs to know
when req is asserted to read data and then ack. This might be done with PC3 as it can be
R512 3k3 GND

Brown Red Orange Yellow

as they each drive a digit but these digits share the same data bus. DIGIT1_EN also allows to read the state of all buttons except RS as this one

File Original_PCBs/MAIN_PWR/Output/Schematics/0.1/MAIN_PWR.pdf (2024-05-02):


Servo and Actuator Drivers

~{GROOVE}
SQCK UPC3 ~{SCSI_SEL} CRCF MLT
~{LDON} MDAT XRST PA[0..2] FOK

FOK DEFECT MIRROR
TEMCK MLT MDAT
MCK MDAT MLT VC

File: motors.kicad_sch ~{LDON} EFM

CRCF SBSY
SUBQ
XRST MCK MLT SQCK

{SFSY SBSY SBCK PW}


3 D101 D_AAK GND GND GND GND


4 WDCK 40 FOK 41 MIRR 42 DVEE 43 DFCT 44 TE 45 TZC 46 ATSC 47 FE 48 FEO

1 AVCC 10 TAO 11 TA- 12 SL+ 13 SLO 14 SL- 15 SSTOP 16 FSET 17 SENS 18 AVEE 19 FGD

2 C.OUT 20 DIRC 21 XRST 22 DATA 23 XLT 24 CLK 25 DGND 26 BW 27 PDI 28

Tracking and Focus TRACKING




instead but seemed to be the same). CXD1167 must have built in RAM

PW is Subcode data P to W (8-bits)


whether we are in a command or data stage. Equally, the micro needs to know
when req is asserted to read data and then ack. This might be done with PC3 as it can be

1 PB7 10 PC0/TxD 11 PC1/RxD 12 PC2/~{SCK} 13 PC3/INT2 14 PC4/TO 15 PC5/CI 16 PC6/CO0 17 PC7/CO1 18 ~{NMI} 19 PA7


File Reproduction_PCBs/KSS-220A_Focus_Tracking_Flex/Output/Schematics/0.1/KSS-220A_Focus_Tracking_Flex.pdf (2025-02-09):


Tracking and Focus TRACKING


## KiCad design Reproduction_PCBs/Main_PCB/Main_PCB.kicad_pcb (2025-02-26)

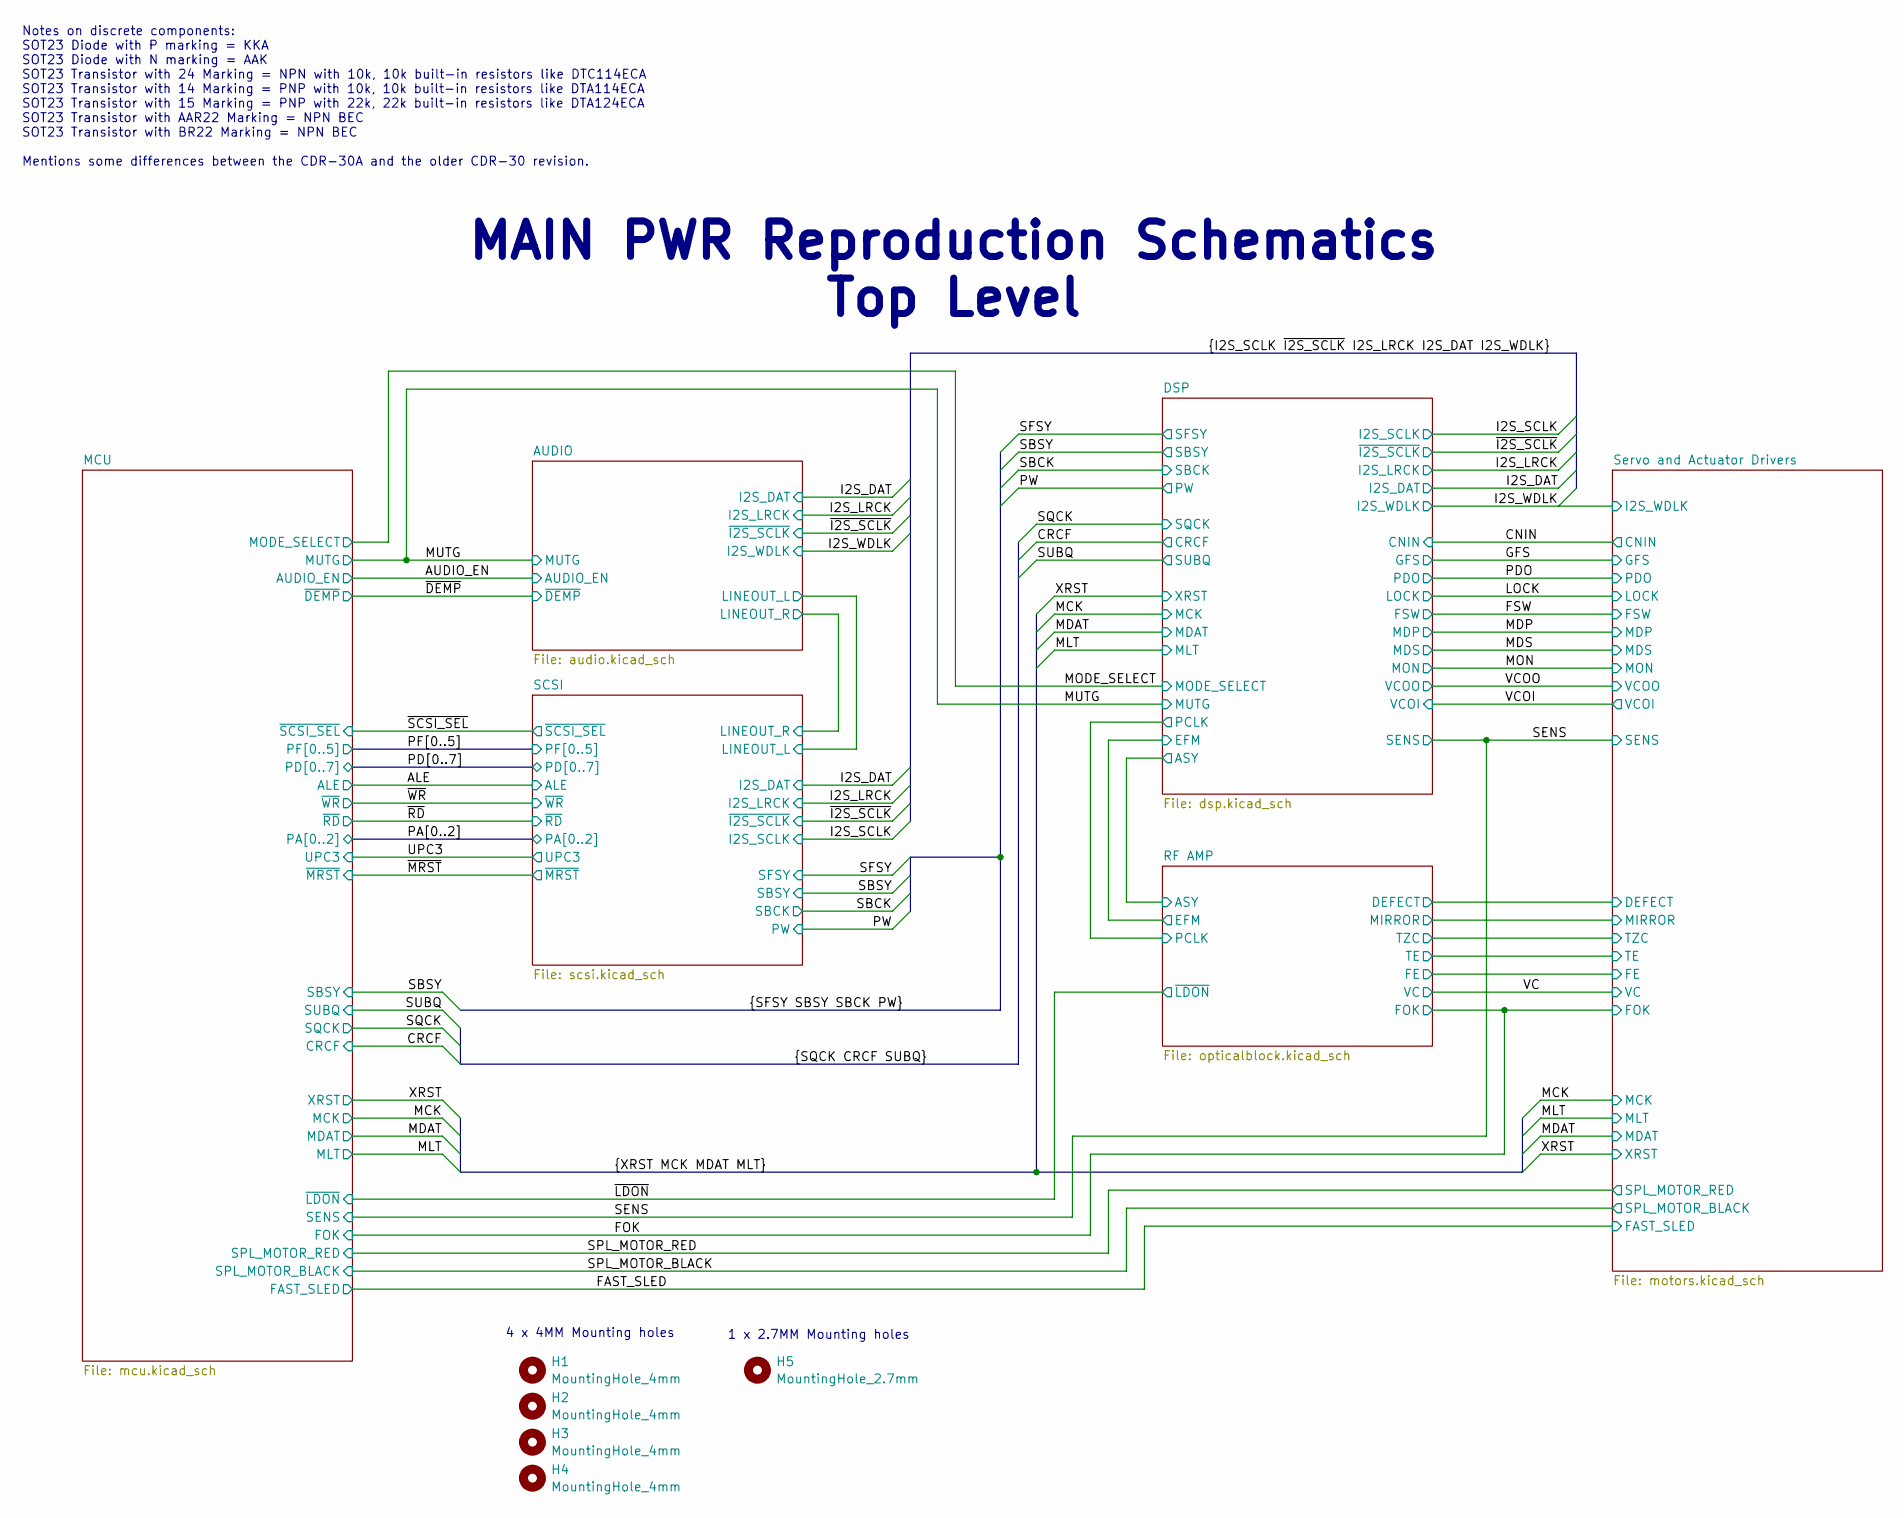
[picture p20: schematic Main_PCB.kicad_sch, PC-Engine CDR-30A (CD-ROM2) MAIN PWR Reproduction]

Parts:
H1, H2, H3, H4: MountingHole_4mm
H5: MountingHole_2.7mm

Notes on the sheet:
Notes on discrete components: SOT23 Diode with P marking = KKA SOT23 Diode with N marking = AAK SOT23 Transistor with 24 Marking = NPN with 10k, 10k built-in resistors like DTC114ECA SOT23 Transistor with 14 Marking = PNP with 10k, 10k built-in resistors like DTA114ECA SOT23 Transistor with 15 Mark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
4 x 4MM Mounting holes
1 x 2.7MM Mounting holes
MAIN PWR Reproduction Schematics Top Level

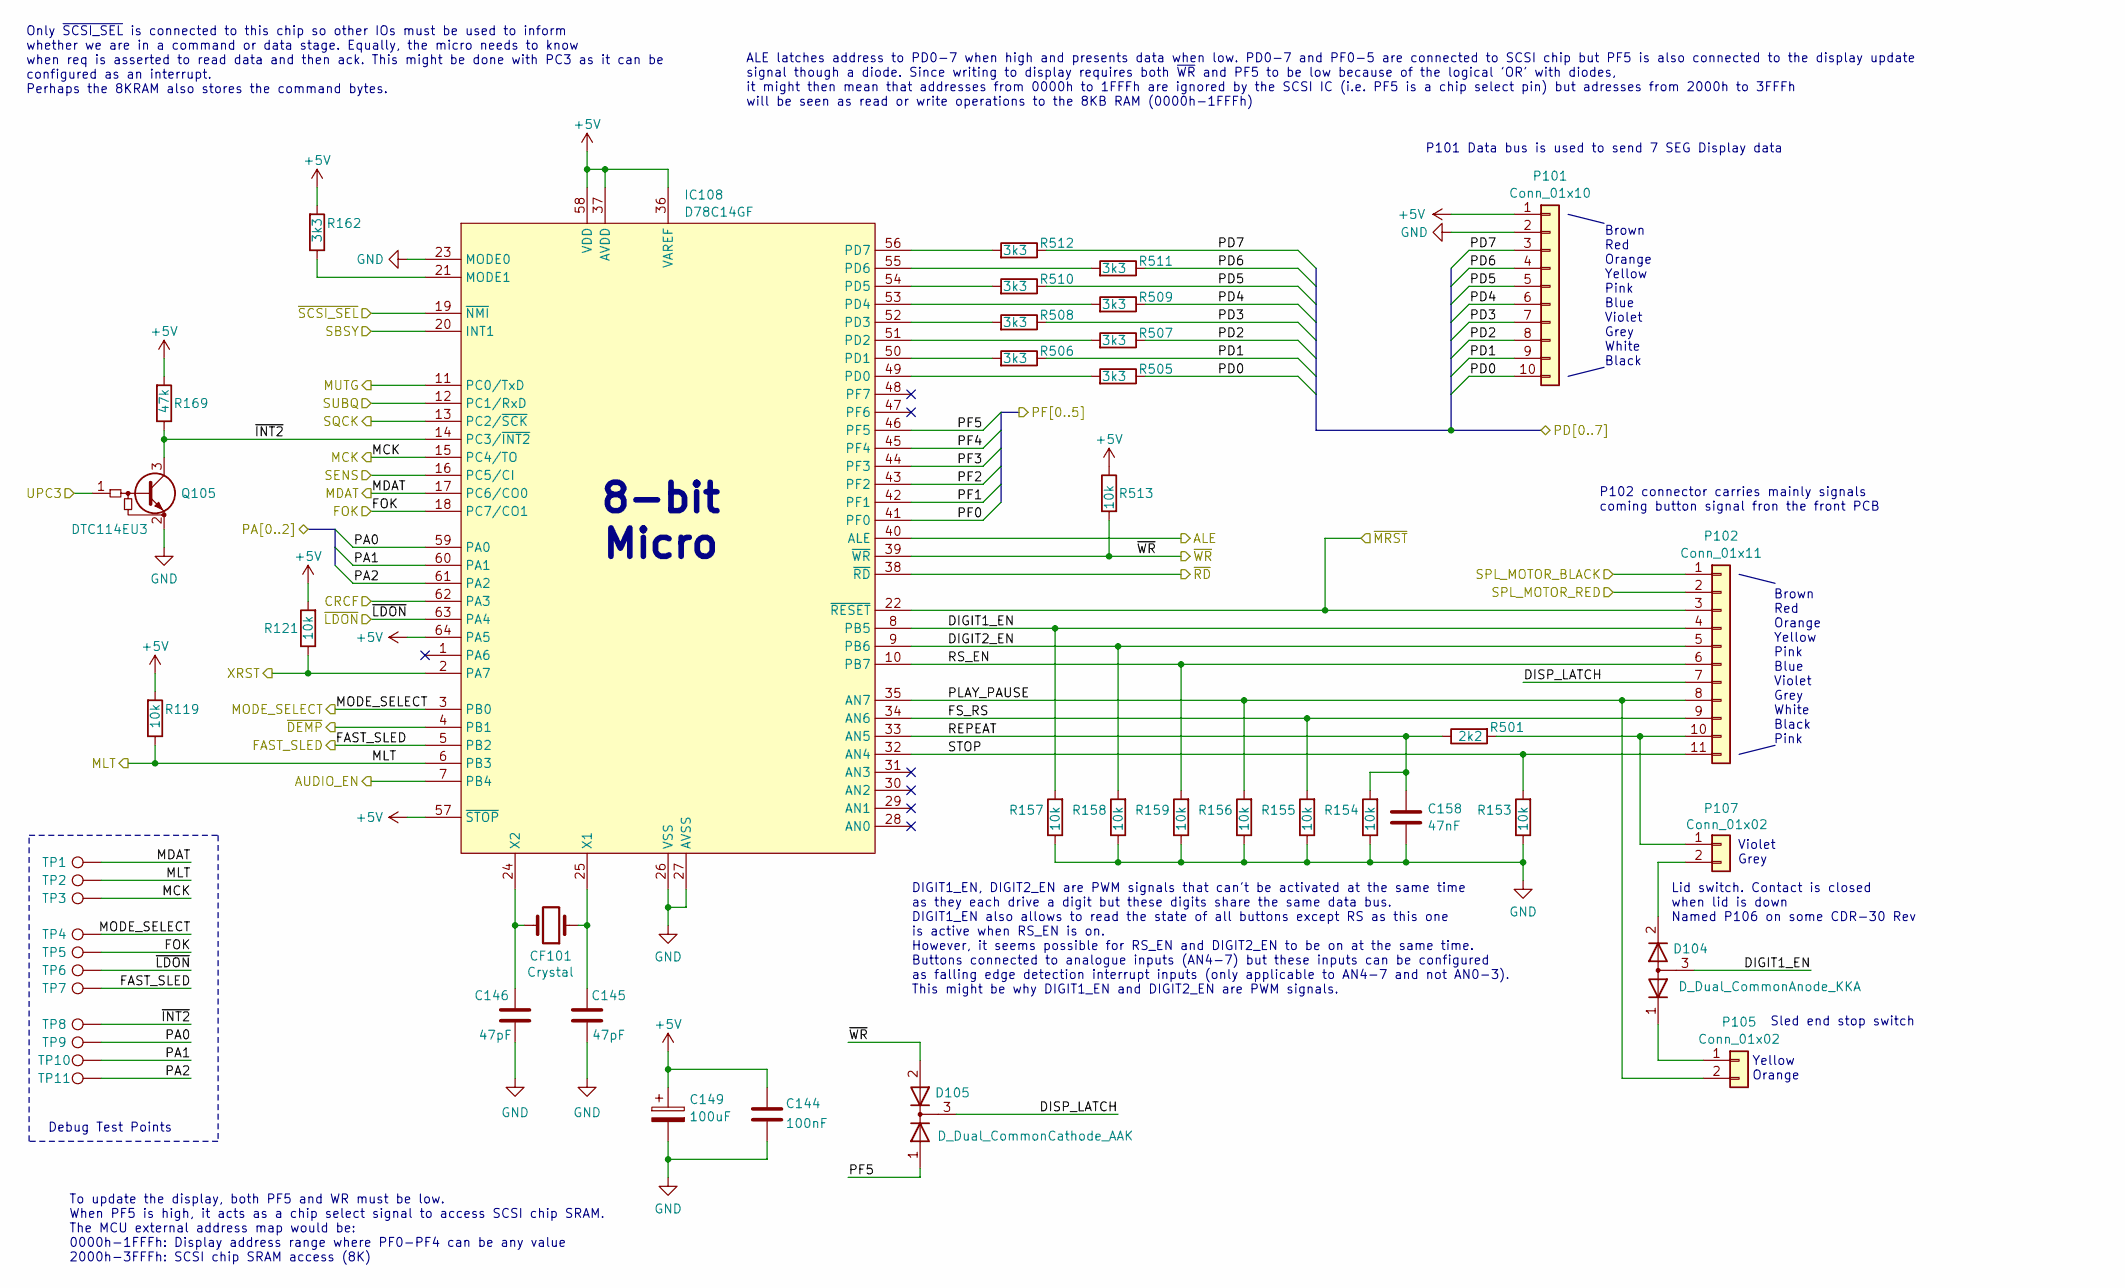
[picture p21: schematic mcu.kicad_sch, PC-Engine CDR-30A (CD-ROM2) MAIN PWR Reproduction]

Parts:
C144: 100nF; C_0603_1608Metric
C145, C146: 47pF; C_0603_1608Metric
C149: 100uF; CP_Elec_5x5.4
C158: 47nF; C_0603_1608Metric
CF101: Crystal; Crystal_HC18-U_Vertical
D104: D_Dual_CommonAnode_KKA; SOT-23
D105: D_Dual_CommonCathode_AAK; SOT-23
IC108: D78C14GF; PQFP-64_20x14mm_P1.0mm
P101: Conn_01x10; JST_ZH_B10B-ZR_1x10_P1.50mm_Vertical
P102: Conn_01x11; JST_ZH_B11B-ZR_1x11_P1.50mm_Vertical
P105, P107: Conn_01x02; JST_ZH_B2B-ZR_1x02_P1.50mm_Vertical
Q105: DTC114EU3; SOT-23
R119, R121, R153, R154, R155, R156, R157, R158, R159, R513: 10k; R_0603_1608Metric
R162, R505, R506, R507, R508, R509, R510, R511, R512: 3k3; R_0603_1608Metric
R169: 47k; R_0603_1608Metric
R501: 2k2; R_0603_1608Metric
TP1, TP2, TP3, TP4, TP5, TP6, TP7, TP8, TP9, TP10, TP11: TestPoint; TestPoint_Pad_D1.5mm

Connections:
+5V: C144.2, C149.1, IC108.36 (VAREF), IC108.37 (AVDD), IC108.57 (~STOP), IC108.58 (VDD), IC108.64 (PA5), P101.1, R119.2, R121.2, R162.2, R169.2, R513.1; also elsewhere on the board
/ALE: IC108.40 (ALE); also elsewhere on the board
/AUDIO_EN: IC108.7 (PB4); also elsewhere on the board
/CRCF: IC108.62 (PA3); also elsewhere on the board
/FAST_SLED: IC108.5 (PB2), TP7.1; also elsewhere on the board
/FOK: IC108.18 (PC7/CO1), TP5.1; also elsewhere on the board
/MCK: IC108.15 (PC4/TO), TP3.1; also elsewhere on the board
/MCU/DIGIT1_EN: D104.3 (A), IC108.8 (PB5), P102.4, R157.2
/MCU/DIGIT2_EN: IC108.9 (PB6), P102.5, R158.2
/MCU/DISP_LATCH: D105.3 (K), P102.7
/MCU/FS_RS: IC108.34 (AN6), P102.9, R155.2
/MCU/PLAY_PAUSE: IC108.35 (AN7), P102.8, P105.2, R156.2
/MCU/REPEAT: C158.1, IC108.33 (AN5), R154.2, R501.1
/MCU/RS_EN: IC108.10 (PB7), P102.6, R159.2
/MCU/STOP: IC108.32 (AN4), P102.11, R153.2
/MCU/~INT2: IC108.14 (PC3/~INT2), Q105.3 (C), R169.1, TP8.1
/MDAT: IC108.17 (PC6/CO0), TP1.1; also elsewhere on the board
/MLT: IC108.6 (PB3), R119.1, TP2.1; also elsewhere on the board
/MODE_SELECT: IC108.3 (PB0), TP4.1; also elsewhere on the board
/MUTG: IC108.11 (PC0/TxD); also elsewhere on the board
/PA0: IC108.59 (PA0), TP9.1; also elsewhere on the board
/PA1: IC108.60 (PA1), TP10.1; also elsewhere on the board
/PA2: IC108.61 (PA2), TP11.1; also elsewhere on the board
/PD0: P101.10, R505.1; also elsewhere on the board
/PD1: P101.9, R506.1; also elsewhere on the board
/PD2: P101.8, R507.1; also elsewhere on the board
/PD3: P101.7, R508.1; also elsewhere on the board
/PD4: P101.6, R509.1; also elsewhere on the board
/PD5: P101.5, R510.1; also elsewhere on the board
/PD6: P101.4, R511.1; also elsewhere on the board
/PD7: P101.3, R512.1; also elsewhere on the board
/PF0: IC108.41 (PF0); also elsewhere on the board
/PF1: IC108.42 (PF1); also elsewhere on the board
/PF2: IC108.43 (PF2); also elsewhere on the board
/PF3: IC108.44 (PF3); also elsewhere on the board
/PF4: IC108.45 (PF4); also elsewhere on the board
/PF5: D105.1 (A), IC108.46 (PF5); also elsewhere on the board
/SBSY: IC108.20 (INT1); also elsewhere on the board
/SENS: IC108.16 (PC5/CI); also elsewhere on the board
/SPL_MOTOR_BLACK: P102.1; also elsewhere on the board
/SPL_MOTOR_RED: P102.2; also elsewhere on the board
/SQCK: IC108.13 (PC2/~SCK); also elsewhere on the board
/SUBQ: IC108.12 (PC1/RxD); also elsewhere on the board
/UPC3: Q105.1 (B); also elsewhere on the board
/XRST: IC108.2 (PA7), R121.1; also elsewhere on the board
/~DEMP: IC108.4 (PB1); also elsewhere on the board
/~LDON: IC108.63 (PA4), TP6.1; also elsewhere on the board
/~MRST: IC108.22 (~RESET), P102.3; also elsewhere on the board
/~RD: IC108.38 (~RD); also elsewhere on the board
/~SCSI_SEL: IC108.19 (~NMI); also elsewhere on the board
/~WR: D105.2 (A), IC108.39 (~WR), R513.2; also elsewhere on the board
GND: C144.1, C145.2, C146.1, C149.2, C158.2, IC108.23 (MODE0), IC108.26 (VSS), IC108.27 (AVSS), P101.2, Q105.2 (E), R153.1, R154.1, R155.1, R156.1, R157.1, R158.1, R159.1; also elsewhere on the board
unnamed: IC108.21 (MODE1), R162.1
unnamed: IC108.49 (PD0), R505.2
unnamed: IC108.50 (PD1), R506.2
unnamed: IC108.51 (PD2), R507.2
unnamed: IC108.52 (PD3), R508.2
unnamed: IC108.53 (PD4), R509.2
unnamed: IC108.54 (PD5), R510.2
unnamed: IC108.55 (PD6), R511.2
unnamed: IC108.56 (PD7), R512.2
unnamed: C145.1, CF101.1, IC108.25 (X1)
unnamed: C146.2, CF101.2, IC108.24 (X2)
unnamed: P102.10, P107.1, R501.2
unnamed: D104.1 (K), P105.1
unnamed: D104.2 (K), P107.2

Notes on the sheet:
Lid switch. Contact is closed when lid is down Named P106 on some CDR-30 Rev
Brown Red Orange Yellow Pink Blue Violet Grey White Black
8-bit Micro
P102 connector carries mainly signals coming button signal fron the front PCB
ALE latches address to PD0-7 when high and presents data when low. PD0-7 and PF0-5 are connected to SCSI chip but PF5 is also connected to the display update signal though a diode. Since writing to display requires both ~{WR} and PF5 to be low because of the logical 'OR' with diodes, it might then 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
DIGIT1_EN, DIGIT2_EN are PWM signals that can't be activated at the same time as they each drive a digit but these digits share the same data bus. DIGIT1_EN also allows to read the state of all buttons except RS as this one is active when RS_EN is on. However, it seems possible for RS_EN and DIGIT2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
Brown Red Orange Yellow Pink Blue Violet Grey White Black Pink
To update the display, both PF5 and WR must be low. When PF5 is high, it acts as a chip select signal to access SCSI chip SRAM. The MCU external address map would be: 0000h-1FFFh: Display address range where PF0-PF4 can be any value 2000h-3FFFh: SCSI chip SRAM access (8K)
P101 Data bus is used to send 7 SEG Display data
Violet Grey
Debug Test Points
Sled end stop switch
Only ~{SCSI_SEL} is connected to this chip so other IOs must be used to inform whether we are in a command or data stage. Equally, the micro needs to know when req is asserted to read data and then ack. This might be done with PC3 as it can be configured as an interrupt. Perhaps the 8KRAM also stor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
Yellow Orange

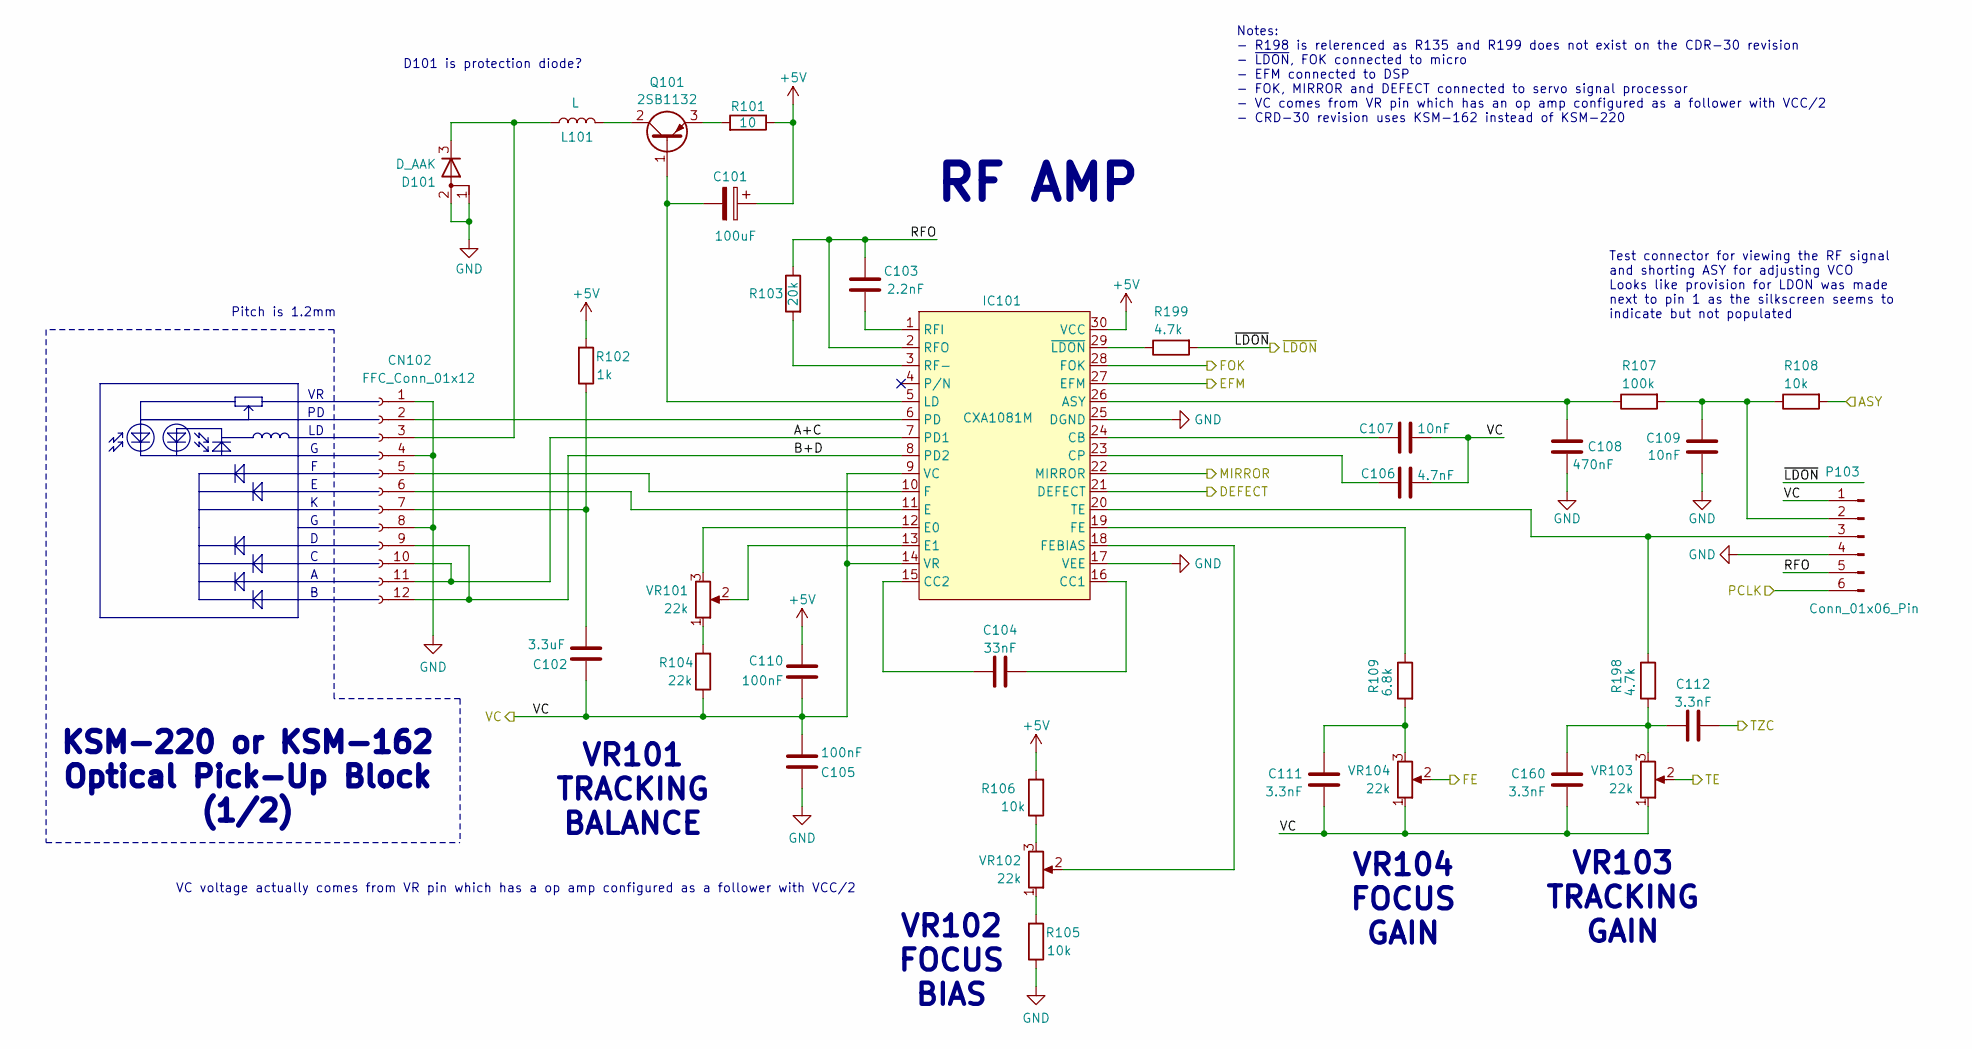
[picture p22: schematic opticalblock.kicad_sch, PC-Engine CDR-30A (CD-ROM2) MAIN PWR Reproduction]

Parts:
C101: 100uF; CP_Elec_5x5.4
C102: 3.3uF; C_0805_2012Metric
C103: 2.2nF; C_0603_1608Metric
C104: 33nF; C_0603_1608Metric
C105, C110: 100nF; C_0603_1608Metric
C106: 4.7nF; C_0603_1608Metric
C107, C109: 10nF; C_0603_1608Metric
C108: 470nF; C_0603_1608Metric
C111, C112, C160: 3.3nF; C_0603_1608Metric
CN102: FFC_Conn_01x12; FFC_01x12_P1.25mm_Vertical
D101: D_AAK; SOT-23
IC101: CXA1081M; SOIC-30W_7.5x20.0mm_P1.27mm
L101: L; L_Axial_L5.0mm_D3.6mm_P10.00mm_Horizontal_Murata_BL01RN1A2A2
P103: Conn_01x06_Pin; PinHeader_1x06_P2.00mm_Horizontal
Q101: 2SB1132; SOT-89-3
R101: 10; R_Axial_DIN0207_L6.3mm_D2.5mm_P10.16mm_Horizontal
R102: 1k; R_0603_1608Metric
R103: 20k; R_0603_1608Metric
R104: 22k; R_0603_1608Metric
R105, R106, R108: 10k; R_0603_1608Metric
R107: 100k; R_0603_1608Metric
R109: 6.8k; R_0603_1608Metric
R198, R199: 4.7k; R_0603_1608Metric
VR101, VR102, VR103, VR104: 22k; Potentiometer_ACP_CA6-H2,5_Horizontal

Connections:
+5V: C101.1, C110.2, IC101.30 (VCC), R101.1, R102.2, R106.2; also elsewhere on the board
/DSP/ASY: R108.2; also elsewhere on the board
/DSP/EFM: IC101.27 (EFM); also elsewhere on the board
/DSP/PCLK: P103.6; also elsewhere on the board
/FOK: IC101.28 (FOK); also elsewhere on the board
/RF AMP/A+C: CN102.10, CN102.11, IC101.7 (PD1)
/RF AMP/B+D: CN102.9, CN102.12, IC101.8 (PD2)
/RF AMP/DEFECT: IC101.21 (DEFECT); also elsewhere on the board
/RF AMP/MIRROR: IC101.22 (MIRROR); also elsewhere on the board
/RF AMP/RFO: C103.1, IC101.2 (RFO), P103.5, R103.1
/Servo and Actuator Drivers/FE: VR104.2; also elsewhere on the board
/Servo and Actuator Drivers/TE: VR103.2; also elsewhere on the board
/Servo and Actuator Drivers/TZC: C112.1; also elsewhere on the board
/VC: C102.2, C105.1, C106.1, C107.1, C110.1, C111.1, C160.1, IC101.9 (VC), IC101.14 (VR), P103.1, R104.1, VR103.1, VR104.1; also elsewhere on the board
/~LDON: R199.2; also elsewhere on the board
GND: C105.2, C108.2, C109.1, CN102.1, CN102.4, CN102.8, D101.1 (A), D101.2 (A), IC101.17 (VEE), IC101.25 (DGND), P103.4, R105.1; also elsewhere on the board
unnamed: C111.2, R109.2, VR104.3
unnamed: C112.2, C160.2, R198.2, VR103.3
unnamed: CN102.2, IC101.6 (PD)
unnamed: CN102.3, D101.3 (K), L101.1
unnamed: CN102.5, IC101.10 (F)
unnamed: CN102.6, IC101.11 (E)
unnamed: C102.1, CN102.7, R102.1
unnamed: C108.1, IC101.26 (ASY), R107.1
unnamed: C107.2, IC101.24 (CB)
unnamed: C104.2, IC101.16 (CC1)
unnamed: C104.1, IC101.15 (CC2)
unnamed: C106.2, IC101.23 (CP)
unnamed: IC101.12 (E0), VR101.3
unnamed: IC101.13 (E1), VR101.2
unnamed: IC101.19 (FE), R109.1
unnamed: IC101.18 (FEBIAS), VR102.2
unnamed: C101.2, IC101.5 (LD), Q101.1 (B)
unnamed: IC101.3 (RF-), R103.2
unnamed: C103.2, IC101.1 (RFI)
unnamed: IC101.20 (TE), P103.3, R198.1
unnamed: IC101.29 (~LDON), R199.1
unnamed: C109.2, P103.2, R107.2, R108.1
unnamed: L101.2, Q101.2 (C)
unnamed: Q101.3 (E), R101.2
unnamed: R104.2, VR101.1
unnamed: R105.2, VR102.1
unnamed: R106.1, VR102.3

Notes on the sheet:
RF AMP
Pitch is 1.2mm
Test connector for viewing the RF signal and shorting ASY for adjusting VCO Looks like provision for LDON was made next to pin 1 as the silkscreen seems to indicate but not populated
Notes: - R198 is relerenced as R135 and R199 does not exist on the CDR-30 revision - ~{LDON}, FOK connected to micro - EFM connected to DSP - FOK, MIRROR and DEFECT connected to servo signal processor - VC comes from VR pin which has an op amp configured as a follower with VCC/2 - CRD-30 revision u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
D101 is protection diode?
KSM-220 or KSM-162 Optical Pick-Up Block (1/2)
VR103 TRACKING GAIN
VC voltage actually comes from VR pin which has a op amp configured as a follower with VCC/2
VR104 FOCUS GAIN
VR101 TRACKING BALANCE
VR102 FOCUS BIAS

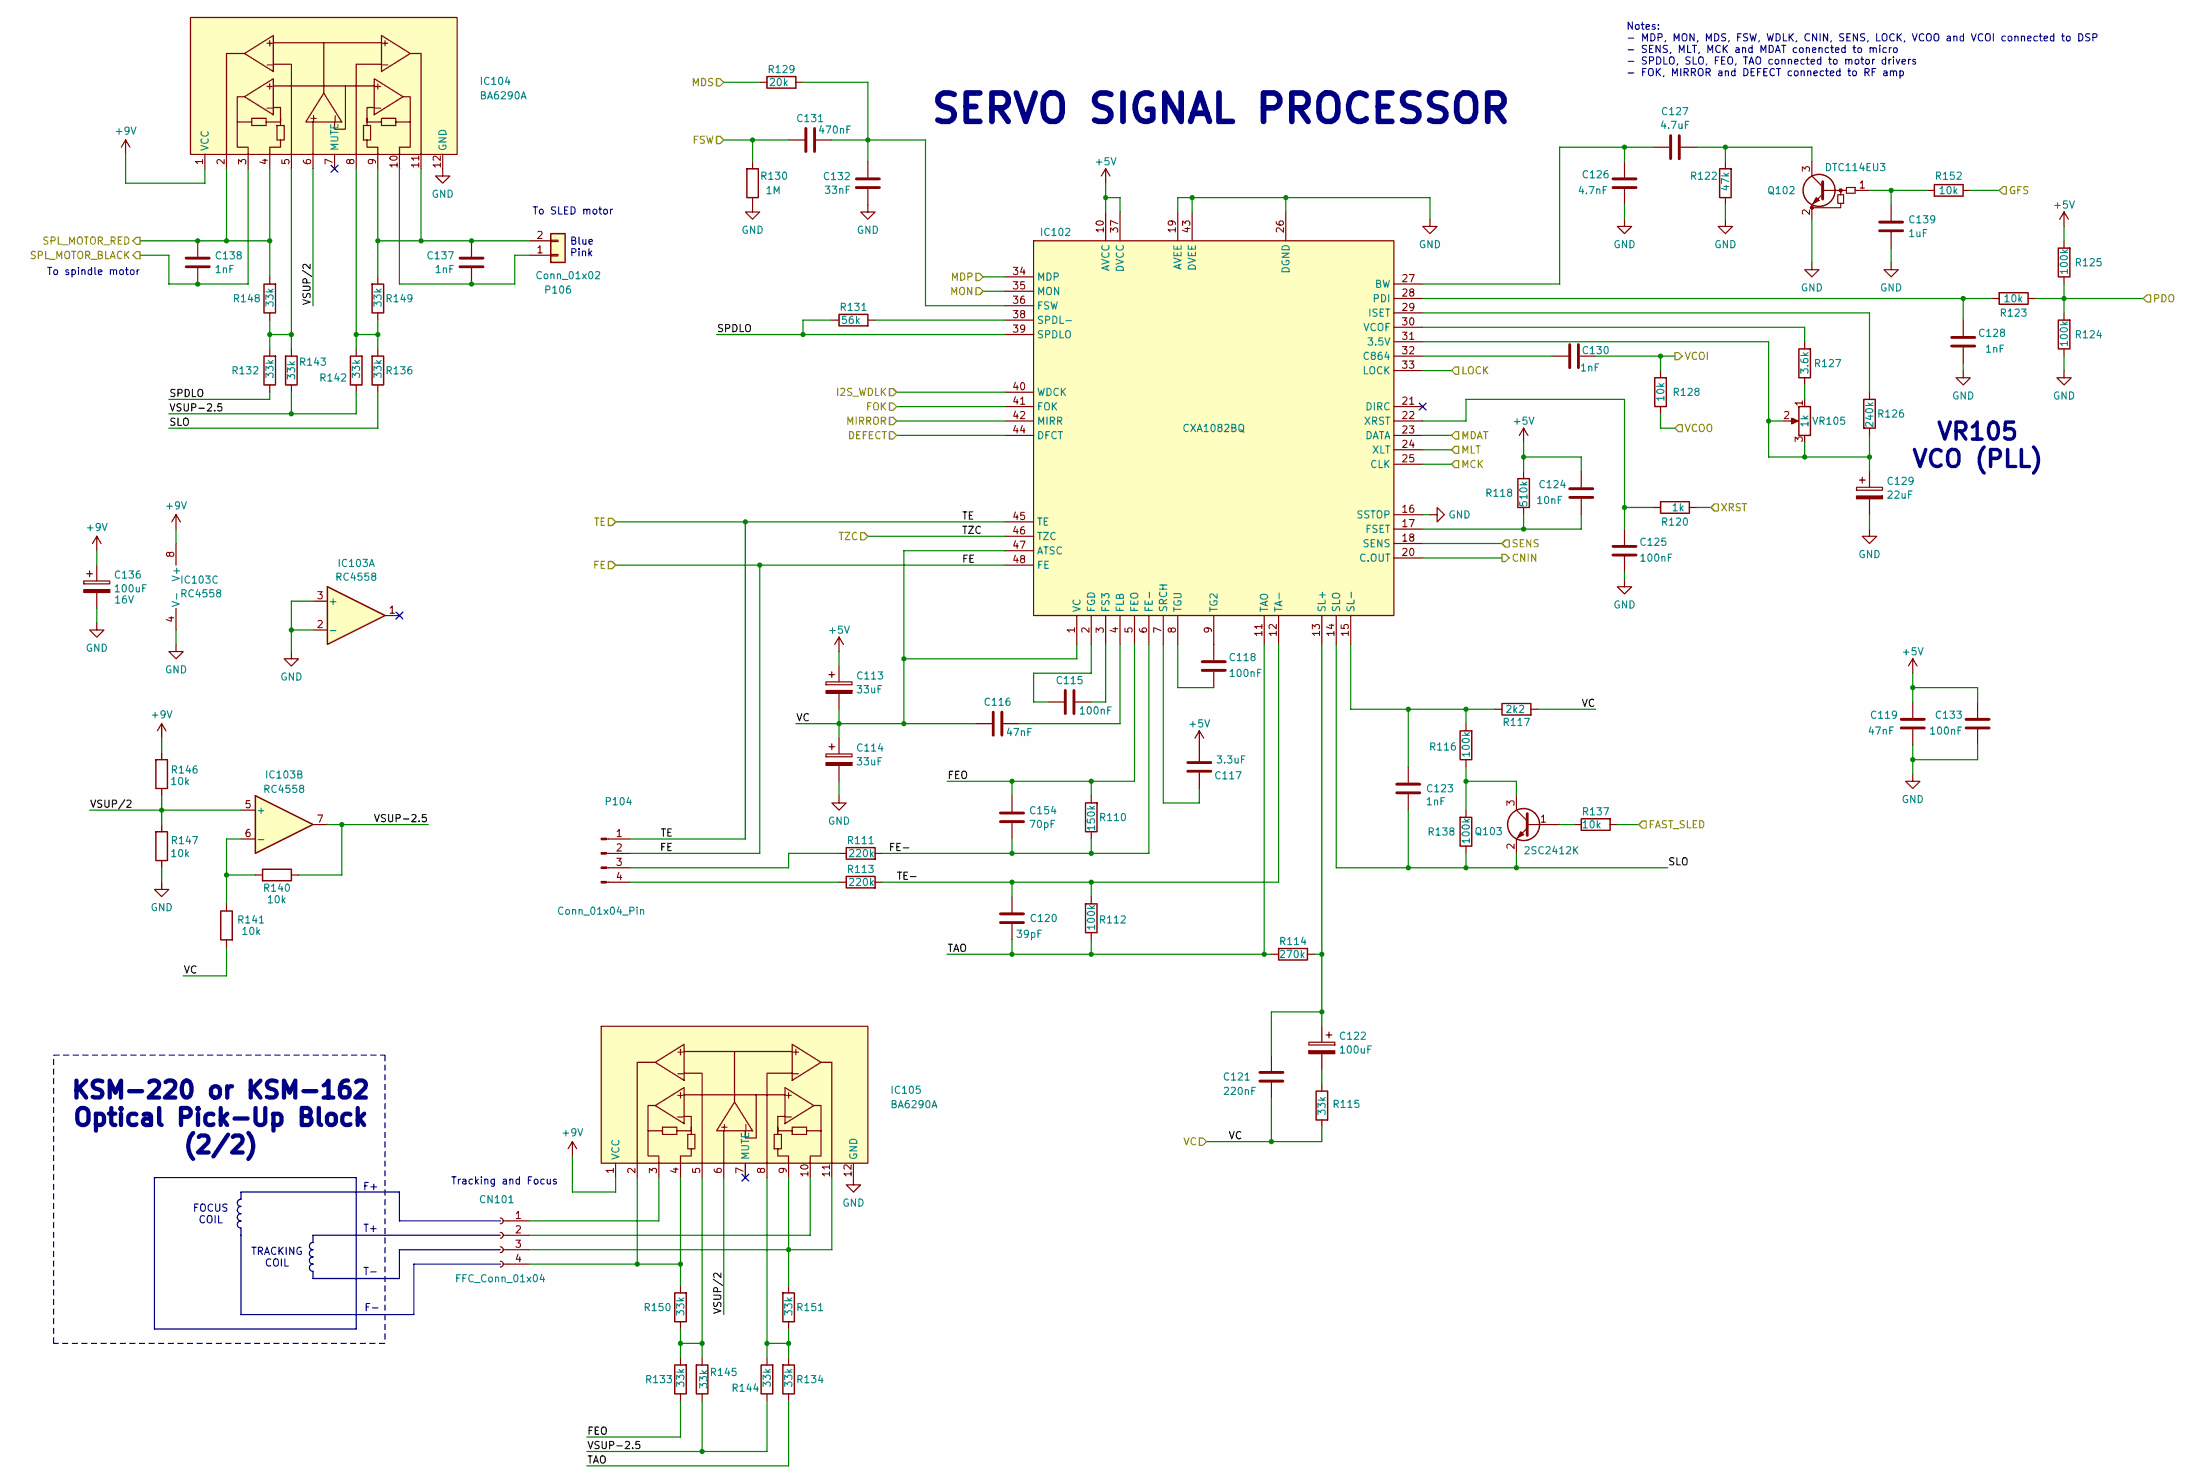
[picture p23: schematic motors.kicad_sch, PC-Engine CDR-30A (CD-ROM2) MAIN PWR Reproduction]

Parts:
C113, C114: 33uF; CP_Elec_5x5.4
C115, C118, C125, C133: 100nF; C_0603_1608Metric
C116, C119: 47nF; C_0603_1608Metric
C117: 3.3uF; C_0805_2012Metric
C120: 39pF; C_0603_1608Metric
C121: 220nF; C_0603_1608Metric
C122: 100uF; CP_Elec_5x5.4
C123, C128, C130, C137, C138: 1nF; C_0603_1608Metric
C124: 10nF; C_0603_1608Metric
C126: 4.7nF; C_0603_1608Metric
C127: 4.7uF; C_0805_2012Metric
C129: 22uF; CP_Elec_4x5.4
C131: 470nF; C_0603_1608Metric
C132: 33nF; C_0603_1608Metric
C136: 100uF; CP_Elec_6.3x5.4; Voltage 16V
C139: 1uF; C_0603_1608Metric
C154: 70pF; C_0603_1608Metric
CN101: FFC_Conn_01x04; FFC_01x04_P1.25mm_Vertical
IC102: CXA1082BQ; LQFP-48_12x12mm_P0.8mm
IC103: RC4558; SOIC-8_3.9x4.9mm_P1.27mm
IC104, IC105: BA6290A; TerminalBlock_TE_1-282834-2_1x12_P2.54mm_Horizontal
P104: Conn_01x04_Pin; PinHeader_1x04_P2.00mm_Horizontal
P106: Conn_01x02; JST_ZH_B2B-ZR_1x02_P1.50mm_Vertical
Q102: DTC114EU3; SOT-23
Q103: 2SC2412K; SOT-23
R110: 150k; R_0603_1608Metric
R111, R113: 220k; R_0603_1608Metric
R112, R116, R124, R125, R138: 100k; R_0603_1608Metric
R114: 270k; R_0603_1608Metric
R115, R132, R133, R134, R136, R142, R143, R144, R145, R148, R149, R150, R151: 33k; R_0603_1608Metric
R117: 2k2; R_0603_1608Metric
R118: 510k; R_0603_1608Metric
R120: 1k; R_0603_1608Metric
R122: 47k; R_0603_1608Metric
R123, R128, R137, R140, R141, R146, R147, R152: 10k; R_0603_1608Metric
R126: 240k; R_0603_1608Metric
R127: 3.6k; R_0603_1608Metric
R129: 20k; R_0603_1608Metric
R130: 1M; R_0603_1608Metric
R131: 56k; R_0603_1608Metric
VR105: 1k; Potentiometer_ACP_CA6-H2,5_Horizontal

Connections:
+5V: C113.1, C117.1, C119.2, C124.2, C133.2, IC102.10 (AVCC), IC102.37 (DVCC), R118.1, R125.2; also elsewhere on the board
+9V: C136.1, IC103.8 (V+), IC104.1 (VCC), IC105.1 (VCC), R146.2; also elsewhere on the board
/CNIN: IC102.20 (C.OUT); also elsewhere on the board
/FAST_SLED: R137.2; also elsewhere on the board
/FOK: IC102.41 (FOK); also elsewhere on the board
/FSW: C131.1, R130.2; also elsewhere on the board
/GFS: R152.1; also elsewhere on the board
/I2S_WDLK: IC102.40 (WDCK); also elsewhere on the board
/LOCK: IC102.33 (LOCK); also elsewhere on the board
/MCK: IC102.25 (CLK); also elsewhere on the board
/MDAT: IC102.23 (DATA); also elsewhere on the board
/MDP: IC102.34 (MDP); also elsewhere on the board
/MDS: R129.1; also elsewhere on the board
/MLT: IC102.24 (XLT); also elsewhere on the board
/MON: IC102.35 (MON); also elsewhere on the board
/PDO: R123.1, R124.2, R125.1; also elsewhere on the board
/RF AMP/DEFECT: IC102.44 (DFCT); also elsewhere on the board
/RF AMP/MIRROR: IC102.42 (MIRR); also elsewhere on the board
/SENS: IC102.18 (SENS); also elsewhere on the board
/SPL_MOTOR_BLACK: C138.2, IC104.3; also elsewhere on the board
/SPL_MOTOR_RED: C138.1, IC104.2, IC104.4, R148.2; also elsewhere on the board
/Servo and Actuator Drivers/FE: IC102.48 (FE), P104.2; also elsewhere on the board
/Servo and Actuator Drivers/FE-: C154.2, IC102.6 (FE-), R110.1, R111.2
/Servo and Actuator Drivers/FEO: C154.1, IC102.5 (FEO), R110.2, R133.1
/Servo and Actuator Drivers/SLO: C123.2, IC102.14 (SLO), Q103.2 (E), R136.1, R138.1
/Servo and Actuator Drivers/SPDLO: IC102.39 (SPDLO), R131.1, R132.1
/Servo and Actuator Drivers/TAO: C120.2, IC102.11 (TAO), R112.1, R114.2, R134.1
/Servo and Actuator Drivers/TE: IC102.45 (TE), P104.1; also elsewhere on the board
/Servo and Actuator Drivers/TE-: C120.1, IC102.12 (TA-), R112.2, R113.2
/Servo and Actuator Drivers/TZC: IC102.46 (TZC); also elsewhere on the board
/Servo and Actuator Drivers/VSUP-2.5: IC103.7, R140.1, R142.1, R143.1, R144.1, R145.1
/Servo and Actuator Drivers/VSUP/2: IC103.5 (+), IC104.6, IC105.6, R146.1, R147.2
/VC: C113.2, C114.1, C116.2, C121.2, IC102.1 (VC), IC102.47 (ATSC), R115.2, R117.2, R141.2; also elsewhere on the board
/VCOI: C130.1, R128.2; also elsewhere on the board
/VCOO: R128.1; also elsewhere on the board
/XRST: R120.1; also elsewhere on the board
GND: C114.2, C119.1, C125.1, C126.1, C128.1, C129.2, C132.1, C133.1, C136.2, C139.2, IC102.16 (SSTOP), IC102.19 (AVEE), IC102.26 (DGND), IC102.43 (DVEE), IC103.2 (-), IC103.3 (+), IC103.4 (V-), IC104.12 (GND), IC105.12 (GND), Q102.2 (E), R122.1, R124.1, R130.1, R147.1; also elsewhere on the board
unnamed: C122.2, R115.1
unnamed: CN101.1, IC105.3
unnamed: CN101.2, IC105.10
unnamed: CN101.3, IC105.9, IC105.11, R151.2
unnamed: CN101.4, IC105.2, IC105.4, R150.2
unnamed: C129.1, IC102.31 (3.5V), R126.2, VR105.2, VR105.3
unnamed: C126.2, C127.1, IC102.27 (BW)
unnamed: C130.2, IC102.32 (C864)
unnamed: C115.2, IC102.2 (FGD)
unnamed: C116.1, IC102.4 (FLB)
unnamed: C115.1, IC102.3 (FS3)
unnamed: C124.1, IC102.17 (FSET), R118.2
unnamed: C131.2, C132.2, IC102.36 (FSW), R129.2
unnamed: IC102.29 (ISET), R126.1
unnamed: C128.2, IC102.28 (PDI), R123.2
unnamed: C121.1, C122.1, IC102.13 (SL+), R114.1
unnamed: C123.1, IC102.15 (SL-), R116.2, R117.1
unnamed: IC102.38 (SPDL-), R131.2
unnamed: C117.2, IC102.7 (SRCH)
unnamed: C118.2, IC102.9 (TG2)
unnamed: C118.1, IC102.8 (TGU)
unnamed: IC102.30 (VCOF), R127.2
unnamed: C125.2, IC102.22 (XRST), R120.2
unnamed: IC103.6 (-), R140.2, R141.1
unnamed: IC104.5, R132.2, R143.2, R148.1
unnamed: IC104.8, R136.2, R142.2, R149.1
unnamed: IC105.5, R133.2, R145.2, R150.1
unnamed: IC105.8, R134.2, R144.2, R151.1
unnamed: P104.3, R111.1
unnamed: P104.4, R113.1
unnamed: C137.2, IC104.10, P106.1
unnamed: C137.1, IC104.9, IC104.11, P106.2, R149.2
unnamed: C139.1, Q102.1 (B), R152.2
unnamed: C127.2, Q102.3 (C), R122.2
unnamed: Q103.1 (B), R137.1
unnamed: Q103.3 (C), R116.1, R138.2
unnamed: R127.1, VR105.1

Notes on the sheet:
To SLED motor
Notes: - MDP, MON, MDS, FSW, WDLK, CNIN, SENS, LOCK, VCOO and VCOI connected to DSP - SENS, MLT, MCK and MDAT conencted to micro - SPDLO, SLO, FEO, TAO connected to motor drivers - FOK, MIRROR and DEFECT connected to RF amp
SERVO SIGNAL PROCESSOR
Blue Pink
KSM-220 or KSM-162 Optical Pick-Up Block (2/2)
TRACKING COIL
FOCUS COIL
To spindle motor
Tracking and Focus
VR105 VCO (PLL)

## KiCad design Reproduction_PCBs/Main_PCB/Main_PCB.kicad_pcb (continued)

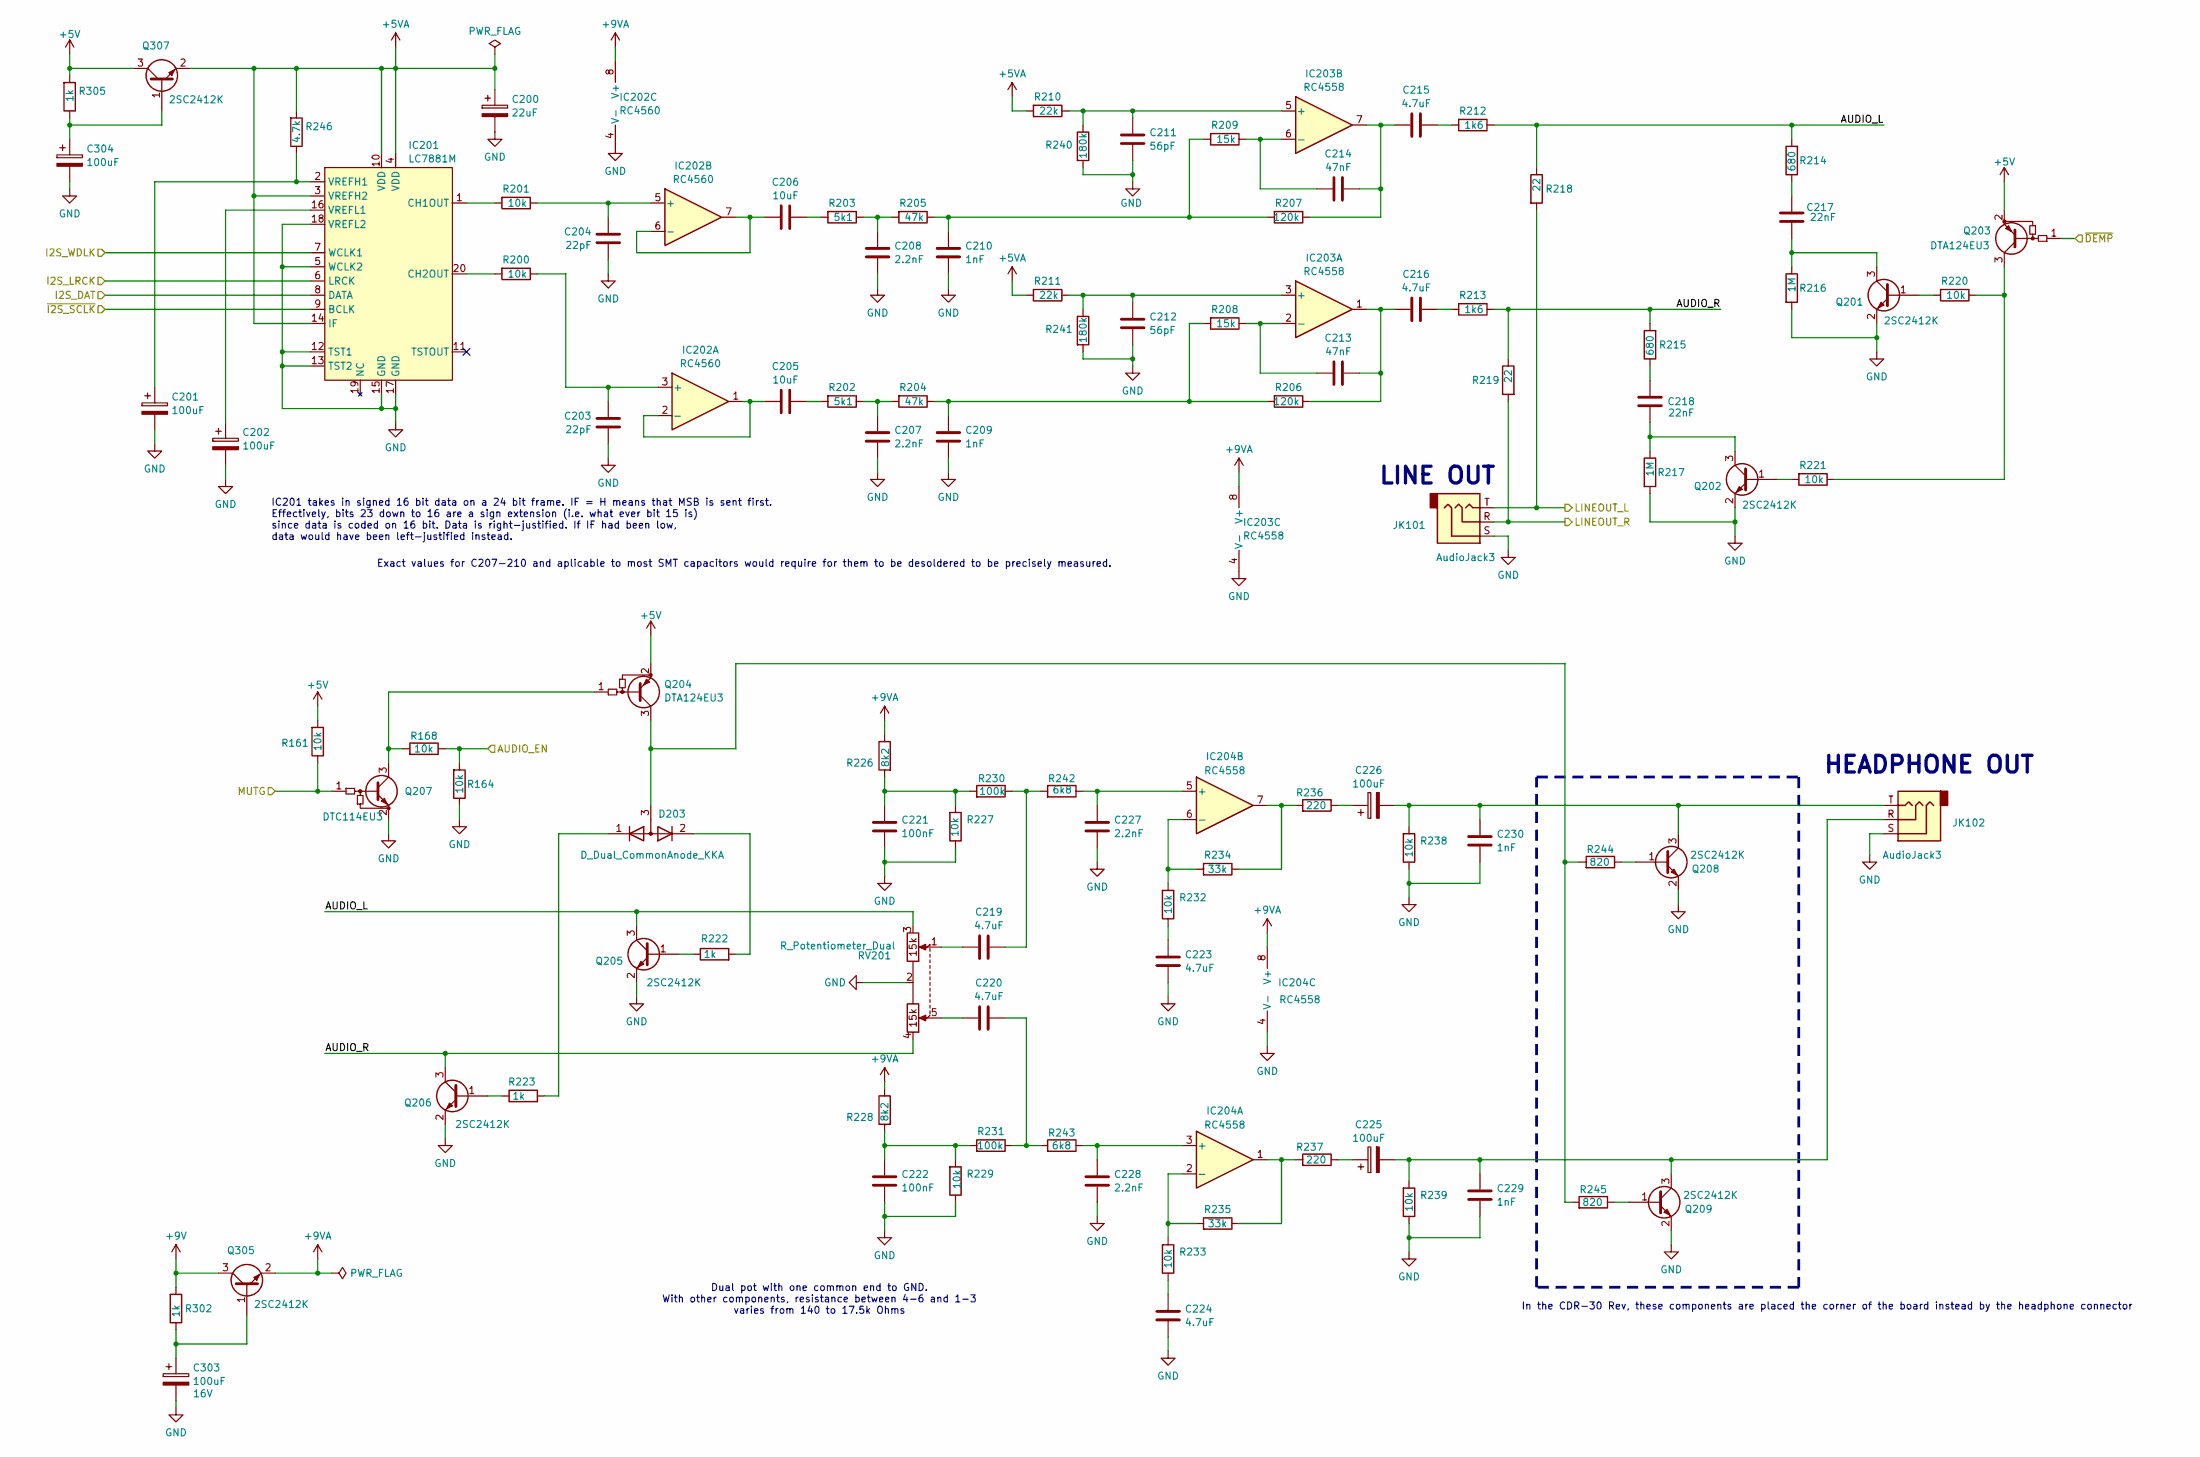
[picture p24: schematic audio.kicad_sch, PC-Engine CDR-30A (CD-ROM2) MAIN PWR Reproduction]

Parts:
C200: 22uF; CP_Elec_4x5.4
C201, C202, C225, C226, C304: 100uF; CP_Elec_5x5.4
C203, C204: 22pF; C_0603_1608Metric
C205, C206: 10uF; C_1206_3216Metric
C207, C208, C227, C228: 2.2nF; C_0603_1608Metric
C209, C210, C229, C230: 1nF; C_0603_1608Metric
C211, C212: 56pF; C_0603_1608Metric
C213, C214: 47nF; C_0603_1608Metric
C215, C216, C219, C220, C223, C224: 4.7uF; C_0805_2012Metric
C217, C218: 22nF; C_0603_1608Metric
C221, C222: 100nF; C_0603_1608Metric
C303: 100uF; CP_Elec_6.3x5.4; Voltage 16V
D203: D_Dual_CommonAnode_KKA; SOT-23
IC201: LC7881M; SO-20_5.3x12.6mm_P1.27mm
IC202: RC4560; SOIC-8_3.9x4.9mm_P1.27mm
IC203, IC204: RC4558; SOIC-8_3.9x4.9mm_P1.27mm
JK101, JK102: AudioJack3; Jack_3.5mm_Horizontal
Q201, Q202, Q205, Q206, Q208, Q209, Q305, Q307: 2SC2412K; SOT-23
Q203, Q204: DTA124EU3; SOT-23
Q207: DTC114EU3; SOT-23
R161, R164, R168, R200, R201, R220, R221, R227, R229, R232, R233, R238, R239: 10k; R_0603_1608Metric
R202, R203: 5k1; R_0603_1608Metric
R204, R205: 47k; R_0603_1608Metric
R206, R207: 120k; R_0603_1608Metric
R208, R209: 15k; R_0603_1608Metric
R210, R211: 22k; R_0603_1608Metric
R212, R213: 1k6; R_0603_1608Metric
R214, R215: 680; R_0603_1608Metric
R216, R217: 1M; R_0603_1608Metric
R218, R219: 22; R_0603_1608Metric
R222, R223, R302, R305: 1k; R_0603_1608Metric
R226, R228: 8k2; R_0603_1608Metric
R230, R231: 100k; R_0603_1608Metric
R234, R235: 33k; R_0603_1608Metric
R236, R237: 220; R_0603_1608Metric
R240, R241: 180k; R_0603_1608Metric
R242, R243: 6k8; R_0603_1608Metric
R244, R245: 820; R_0603_1608Metric
R246: 4.7k; R_0603_1608Metric
RV201: R_Potentiometer_Dual; Potentiometer_Double_Horizontal_Common

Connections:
+5V: Q203.2 (E), Q204.2 (E), Q307.3 (C), R161.2, R305.2; also elsewhere on the board
+5VA: C200.1, IC201.3 (VREFH2), IC201.4 (VDD), IC201.10 (VDD), IC201.14 (IF), Q307.2 (E), R210.2, R211.2, R246.2
+9V: Q305.3 (C), R302.2; also elsewhere on the board
+9VA: IC202.8 (V+), IC203.8 (V+), IC204.8 (V+), Q305.2 (E), R226.1, R228.1
/AUDIO/AUDIO_L: Q205.3 (C), R212.1, R214.2, R218.1, RV201.3
/AUDIO/AUDIO_R: Q206.3 (C), R213.1, R215.2, R219.1, RV201.4
/AUDIO/LINEOUT_L: JK101.T, R218.2; also elsewhere on the board
/AUDIO/LINEOUT_R: JK101.R, R219.2; also elsewhere on the board
/AUDIO_EN: R164.2, R168.1; also elsewhere on the board
/I2S_DAT: IC201.8 (DATA); also elsewhere on the board
/I2S_LRCK: IC201.6 (LRCK); also elsewhere on the board
/I2S_WDLK: IC201.7 (WCLK1); also elsewhere on the board
/MUTG: Q207.1 (B), R161.1; also elsewhere on the board
/~DEMP: Q203.1 (B); also elsewhere on the board
/~I2S_SCLK: IC201.9 (BCLK); also elsewhere on the board
GND: C200.2, C201.2, C202.2, C203.1, C204.1, C207.1, C208.1, C209.1, C210.1, C211.1, C212.1, C221.2, C222.2, C223.2, C224.2, C227.2, C228.2, C229.2, C230.2, C303.2, C304.2, IC201.5 (WCLK2), IC201.12 (TST1), IC201.13 (TST2), IC201.15 (GND), IC201.17 (GND), IC201.18 (VREFL2), IC202.4 (V-), IC203.4 (V-), IC204.4 (V-), JK101.S, JK102.S, Q201.2 (E), Q202.2 (E), Q205.2 (E), Q206.2 (E), Q207.2 (E), Q208.2 (E), Q209.2 (E), R164.1, R216.2, R217.2, R227.1, R229.1, R238.1, R239.1, R240.2, R241.2, RV201.2; also elsewhere on the board
unnamed: C205.1, R202.2
unnamed: C206.1, R203.2
unnamed: C207.2, R202.1, R204.2
unnamed: C208.2, R203.1, R205.2
unnamed: C209.2, R204.1, R206.2, R208.2
unnamed: C210.2, R205.1, R207.2, R209.2
unnamed: C213.1, C216.1, IC203.1, R206.1
unnamed: C214.1, C215.1, IC203.7, R207.1
unnamed: C215.2, R212.2
unnamed: C216.2, R213.2
unnamed: C217.2, R214.1
unnamed: C218.2, R215.1
unnamed: C219.1, R230.1, R242.2
unnamed: C219.2, RV201.1
unnamed: C220.1, R231.1, R243.2
unnamed: C220.2, RV201.5
unnamed: C221.1, R226.2, R227.2, R230.2
unnamed: C222.1, R228.2, R229.2, R231.2
unnamed: C223.1, R232.1
unnamed: C224.1, R233.1
unnamed: C225.1, R237.1
unnamed: C226.1, R236.1
unnamed: D203.3 (A), Q204.3 (C), R244.2, R245.2
unnamed: D203.1 (K), R223.2
unnamed: D203.2 (K), R222.2
unnamed: IC201.1 (CH1OUT), R201.2
unnamed: IC201.20 (CH2OUT), R200.2
unnamed: C201.1, IC201.2 (VREFH1), R246.1
unnamed: C202.1, IC201.16 (VREFL1)
unnamed: C203.2, IC202.3 (+), R200.1
unnamed: C205.2, IC202.1, IC202.2 (-)
unnamed: C204.2, IC202.5 (+), R201.1
unnamed: C206.2, IC202.6 (-), IC202.7
unnamed: C212.2, IC203.3 (+), R211.1, R241.1
unnamed: C213.2, IC203.2 (-), R208.1
unnamed: C211.2, IC203.5 (+), R210.1, R240.1
unnamed: C214.2, IC203.6 (-), R209.1
unnamed: IC204.1, R235.1, R237.2
unnamed: IC204.7, R234.1, R236.2
unnamed: C228.1, IC204.3 (+), R243.1
unnamed: IC204.2 (-), R233.2, R235.2
unnamed: C227.1, IC204.5 (+), R242.1
unnamed: IC204.6 (-), R232.2, R234.2
unnamed: Q201.1 (B), R220.2
unnamed: C217.1, Q201.3 (C), R216.1
unnamed: Q202.1 (B), R221.2
unnamed: C218.1, Q202.3 (C), R217.1
unnamed: Q203.3 (C), R220.1, R221.1
unnamed: Q204.1 (B), Q207.3 (C), R168.2
unnamed: Q205.1 (B), R222.1
unnamed: Q206.1 (B), R223.1
unnamed: Q208.1 (B), R244.1
unnamed: C226.2, C230.1, JK102.T, Q208.3 (C), R238.2
unnamed: Q209.1 (B), R245.1
unnamed: C225.2, C229.1, JK102.R, Q209.3 (C), R239.2
unnamed: C303.1, Q305.1 (B), R302.1
unnamed: C304.1, Q307.1 (B), R305.1

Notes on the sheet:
In the CDR-30 Rev, these components are placed the corner of the board instead by the headphone connector
IC201 takes in signed 16 bit data on a 24 bit frame. IF = H means that MSB is sent first. Effectively, bits 23 down to 16 are a sign extension (i.e. what ever bit 15 is) since data is coded on 16 bit. Data is right-justified. If IF had been low, data would have been left-justified instead.
LINE OUT
HEADPHONE OUT
Exact values for C207-210 and aplicable to most SMT capacitors would require for them to be desoldered to be precisely measured.
Dual pot with one common end to GND. With other components, resistance between 4-6 and 1-3 varies from 140 to 17.5k Ohms

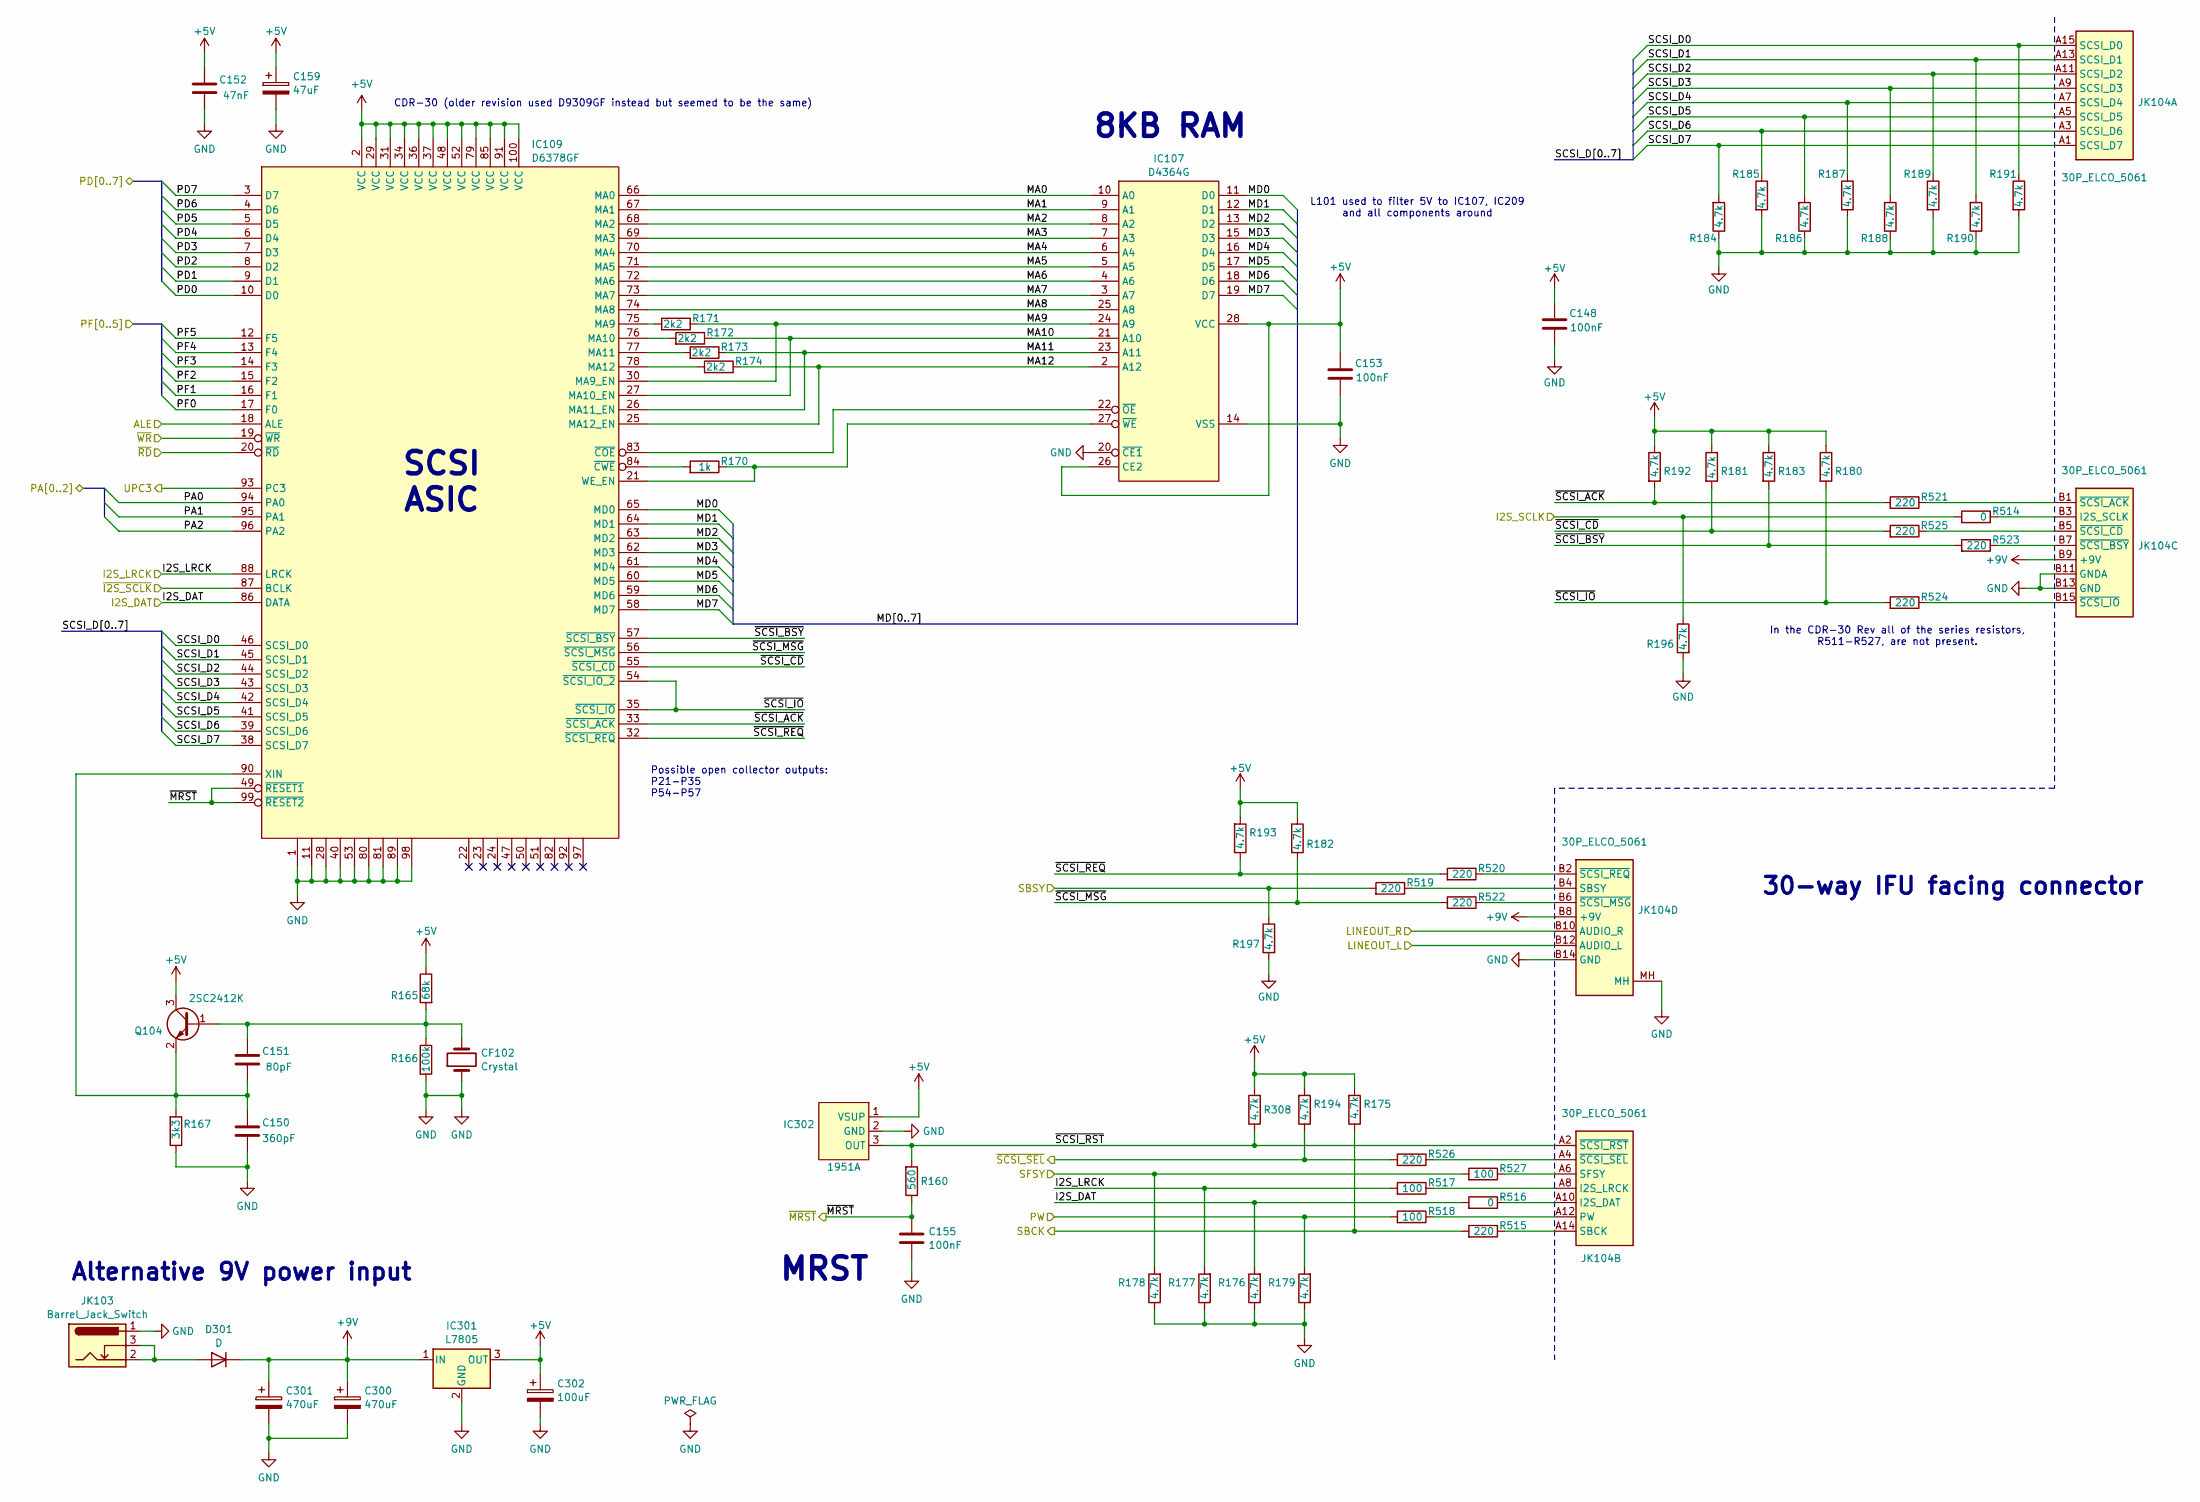
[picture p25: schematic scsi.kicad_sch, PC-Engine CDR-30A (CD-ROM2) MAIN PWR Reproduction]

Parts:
C148, C153, C155: 100nF; C_0603_1608Metric
C150: 360pF; C_0603_1608Metric
C151: 80pF; C_0603_1608Metric
C152: 47nF; C_0603_1608Metric
C159: 47uF; CP_Elec_5x5.4
C300, C301: 470uF; CP_Elec_8x10.5
C302: 100uF; CP_Elec_5x5.4
CF102: Crystal; Crystal_HC18-U_Vertical
D301: D; D_A-405_P10.16mm_Horizontal
IC107: D4364G; SOP-28_8.4x18.16mm_P1.27mm
IC109: D6378GF; PQFP-100_14x20mm_P0.65mm
IC301: L7805; TO-220-3_Horizontal_TabDown_HeatSink
IC302: 1951A; SOT-89-3
JK103: Barrel_Jack_Switch; BarrelJack_Horizontal
JK104: 30P_ELCO_5061; TX25-30P-LT-H1E; Manufacturer Part Number 105061030103856+
Q104: 2SC2412K; SOT-23
R160: 560; R_0603_1608Metric
R165: 68k; R_0603_1608Metric
R166: 100k; R_0603_1608Metric
R167: 3k3; R_0603_1608Metric
R170: 1k; R_0603_1608Metric
R171, R172, R173, R174: 2k2; R_0603_1608Metric
R175, R176, R177, R178, R179, R180, R181, R182, R183, R184, R185, R186, R187, R188, R189, R190, R191, R192, R193, R194, R196, R197, R308: 4.7k; R_0603_1608Metric
R514, R516: 0; R_0603_1608Metric
R515, R519, R520, R521, R522, R523, R524, R525, R526: 220; R_0603_1608Metric
R517, R518, R527: 100; R_0603_1608Metric

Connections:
+5V: C148.1, C152.2, C153.1, C159.1, C302.1, IC107.26 (CE2), IC107.28 (VCC), IC109.2 (VCC), IC109.29 (VCC), IC109.31 (VCC), IC109.34 (VCC), IC109.36 (VCC), IC109.37 (VCC), IC109.48 (VCC), IC109.52 (VCC), IC109.79 (VCC), IC109.85 (VCC), IC109.91 (VCC), IC109.100 (VCC), IC301.3 (OUT), IC302.1 (VSUP), Q104.3 (C), R165.1, R175.2, R180.1, R181.1, R182.1, R183.1, R192.1, R193.2, R194.2, R308.2; also elsewhere on the board
+9V: C300.1, C301.1, D301.1 (K), IC301.1 (IN), JK104.B8 (+9V), JK104.B9 (+9V); also elsewhere on the board
/ALE: IC109.18 (ALE); also elsewhere on the board
/AUDIO/LINEOUT_L: JK104.B12 (AUDIO_L); also elsewhere on the board
/AUDIO/LINEOUT_R: JK104.B10 (AUDIO_R); also elsewhere on the board
/I2S_DAT: IC109.86 (DATA), R176.2, R516.2; also elsewhere on the board
/I2S_LRCK: IC109.88 (LRCK), R177.2, R517.2; also elsewhere on the board
/I2S_SCLK: R196.1, R514.2; also elsewhere on the board
/PA0: IC109.94 (PA0); also elsewhere on the board
/PA1: IC109.95 (PA1); also elsewhere on the board
/PA2: IC109.96 (PA2); also elsewhere on the board
/PD0: IC109.10 (D0); also elsewhere on the board
/PD1: IC109.9 (D1); also elsewhere on the board
/PD2: IC109.8 (D2); also elsewhere on the board
/PD3: IC109.7 (D3); also elsewhere on the board
/PD4: IC109.6 (D4); also elsewhere on the board
/PD5: IC109.5 (D5); also elsewhere on the board
/PD6: IC109.4 (D6); also elsewhere on the board
/PD7: IC109.3 (D7); also elsewhere on the board
/PF0: IC109.17 (F0); also elsewhere on the board
/PF1: IC109.16 (F1); also elsewhere on the board
/PF2: IC109.15 (F2); also elsewhere on the board
/PF3: IC109.14 (F3); also elsewhere on the board
/PF4: IC109.13 (F4); also elsewhere on the board
/PF5: IC109.12 (F5); also elsewhere on the board
/PW: R179.2, R518.2; also elsewhere on the board
/SBCK: R175.1, R515.2; also elsewhere on the board
/SBSY: R197.1, R519.2; also elsewhere on the board
/SCSI/MA0: IC107.10 (A0), IC109.66 (MA0)
/SCSI/MA1: IC107.9 (A1), IC109.67 (MA1)
/SCSI/MA2: IC107.8 (A2), IC109.68 (MA2)
/SCSI/MA3: IC107.7 (A3), IC109.69 (MA3)
/SCSI/MA4: IC107.6 (A4), IC109.70 (MA4)
/SCSI/MA5: IC107.5 (A5), IC109.71 (MA5)
/SCSI/MA6: IC107.4 (A6), IC109.72 (MA6)
/SCSI/MA7: IC107.3 (A7), IC109.73 (MA7)
/SCSI/MA8: IC107.25 (A8), IC109.74 (MA8)
/SCSI/MA9: IC107.24 (A9), IC109.30 (MA9_EN), R171.1
/SCSI/MA10: IC107.21 (A10), IC109.27 (MA10_EN), R172.1
/SCSI/MA11: IC107.23 (A11), IC109.26 (MA11_EN), R173.1
/SCSI/MA12: IC107.2 (A12), IC109.25 (MA12_EN), R174.1
/SCSI/MD0: IC107.11 (D0), IC109.65 (MD0)
/SCSI/MD1: IC107.12 (D1), IC109.64 (MD1)
/SCSI/MD2: IC107.13 (D2), IC109.63 (MD2)
/SCSI/MD3: IC107.15 (D3), IC109.62 (MD3)
/SCSI/MD4: IC107.16 (D4), IC109.61 (MD4)
/SCSI/MD5: IC107.17 (D5), IC109.60 (MD5)
/SCSI/MD6: IC107.18 (D6), IC109.59 (MD6)
/SCSI/MD7: IC107.19 (D7), IC109.58 (MD7)
/SCSI/SCSI_D0: IC109.46 (SCSI_D0), JK104.A15 (SCSI_D0), R191.1
/SCSI/SCSI_D1: IC109.45 (SCSI_D1), JK104.A13 (SCSI_D1), R190.2
/SCSI/SCSI_D2: IC109.44 (SCSI_D2), JK104.A11 (SCSI_D2), R189.1
/SCSI/SCSI_D3: IC109.43 (SCSI_D3), JK104.A9 (SCSI_D3), R188.2
/SCSI/SCSI_D4: IC109.42 (SCSI_D4), JK104.A7 (SCSI_D4), R187.1
/SCSI/SCSI_D5: IC109.41 (SCSI_D5), JK104.A5 (SCSI_D5), R186.2
/SCSI/SCSI_D6: IC109.39 (SCSI_D6), JK104.A3 (SCSI_D6), R185.1
/SCSI/SCSI_D7: IC109.38 (SCSI_D7), JK104.A1 (SCSI_D7), R184.2
/SCSI/~SCSI_ACK: IC109.33 (~SCSI_ACK), R192.2, R521.2
/SCSI/~SCSI_BSY: IC109.57 (~SCSI_BSY), R183.2, R523.2
/SCSI/~SCSI_CD: IC109.55 (~SCSI_CD), R181.2, R525.2
/SCSI/~SCSI_IO: IC109.35 (~SCSI_IO), IC109.54 (~SCSI_IO_2), R180.2, R524.2
/SCSI/~SCSI_MSG: IC109.56 (~SCSI_MSG), R182.2, R522.2
/SCSI/~SCSI_REQ: IC109.32 (~SCSI_REQ), R193.1, R520.2
/SCSI/~SCSI_RST: IC302.3 (OUT), JK104.A2 (~SCSI_RST), R160.2, R308.1
/SFSY: R178.2, R527.2; also elsewhere on the board
/UPC3: IC109.93 (PC3); also elsewhere on the board
/~I2S_SCLK: IC109.87 (BCLK); also elsewhere on the board
/~MRST: C155.1, IC109.49 (~RESET1), IC109.99 (~RESET2), R160.1; also elsewhere on the board
/~RD: IC109.20 (~RD); also elsewhere on the board
/~SCSI_SEL: R194.1, R526.2; also elsewhere on the board
/~WR: IC109.19 (~WR); also elsewhere on the board
GND: C148.2, C150.1, C152.1, C153.2, C155.2, C159.2, C300.2, C301.2, C302.2, CF102.1, IC107.14 (VSS), IC107.20 (~CE1), IC109.1, IC109.11, IC109.28, IC109.40, IC109.53, IC109.80, IC109.81, IC109.89, IC109.98, IC301.2 (GND), IC302.2 (GND), JK103.1, JK104.B11 (GNDA), JK104.B13 (GND), JK104.B14 (GND), JK104.MH, R166.2, R167.1, R176.1, R177.1, R178.1, R179.1, R184.1, R185.2, R186.1, R187.2, R188.1, R189.2, R190.1, R191.2, R196.2, R197.2; also elsewhere on the board
unnamed: D301.2 (A), JK103.2, JK103.3
unnamed: IC107.22 (~OE), IC109.83 (~COE)
unnamed: IC107.27 (~WE), IC109.21 (WE_EN), R170.1
unnamed: IC109.75 (MA9), R171.2
unnamed: IC109.76 (MA10), R172.2
unnamed: IC109.77 (MA11), R173.2
unnamed: IC109.78 (MA12), R174.2
unnamed: C150.2, C151.1, IC109.90 (XIN), Q104.2 (E), R167.2
unnamed: IC109.84 (~CWE), R170.2
unnamed: JK104.A10 (I2S_DAT), R516.1
unnamed: JK104.A8 (I2S_LRCK), R517.1
unnamed: JK104.A12 (PW), R518.1
unnamed: JK104.A14 (SBCK), R515.1
unnamed: JK104.A6 (SFSY), R527.1
unnamed: JK104.A4 (~SCSI_SEL), R526.1
unnamed: JK104.B3 (I2S_SCLK), R514.1
unnamed: JK104.B1 (~SCSI_ACK), R521.1
unnamed: JK104.B7 (~SCSI_BSY), R523.1
unnamed: JK104.B5 (~SCSI_CD), R525.1
unnamed: JK104.B15 (~SCSI_IO), R524.1
unnamed: JK104.B4 (SBSY), R519.1
unnamed: JK104.B6 (~SCSI_MSG), R522.1
unnamed: JK104.B2 (~SCSI_REQ), R520.1
unnamed: C151.2, CF102.2, Q104.1 (B), R165.2, R166.1

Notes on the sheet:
MRST
30-way IFU facing connector
L101 used to filter 5V to IC107, IC209 and all components around
8KB RAM
Possible open collector outputs: P21-P35 P54-P57
SCSI ASIC
In the CDR-30 Rev all of the series resistors, R511-R527, are not present.
Alternative 9V power input
CDR-30 (older revision used D9309GF instead but seemed to be the same)

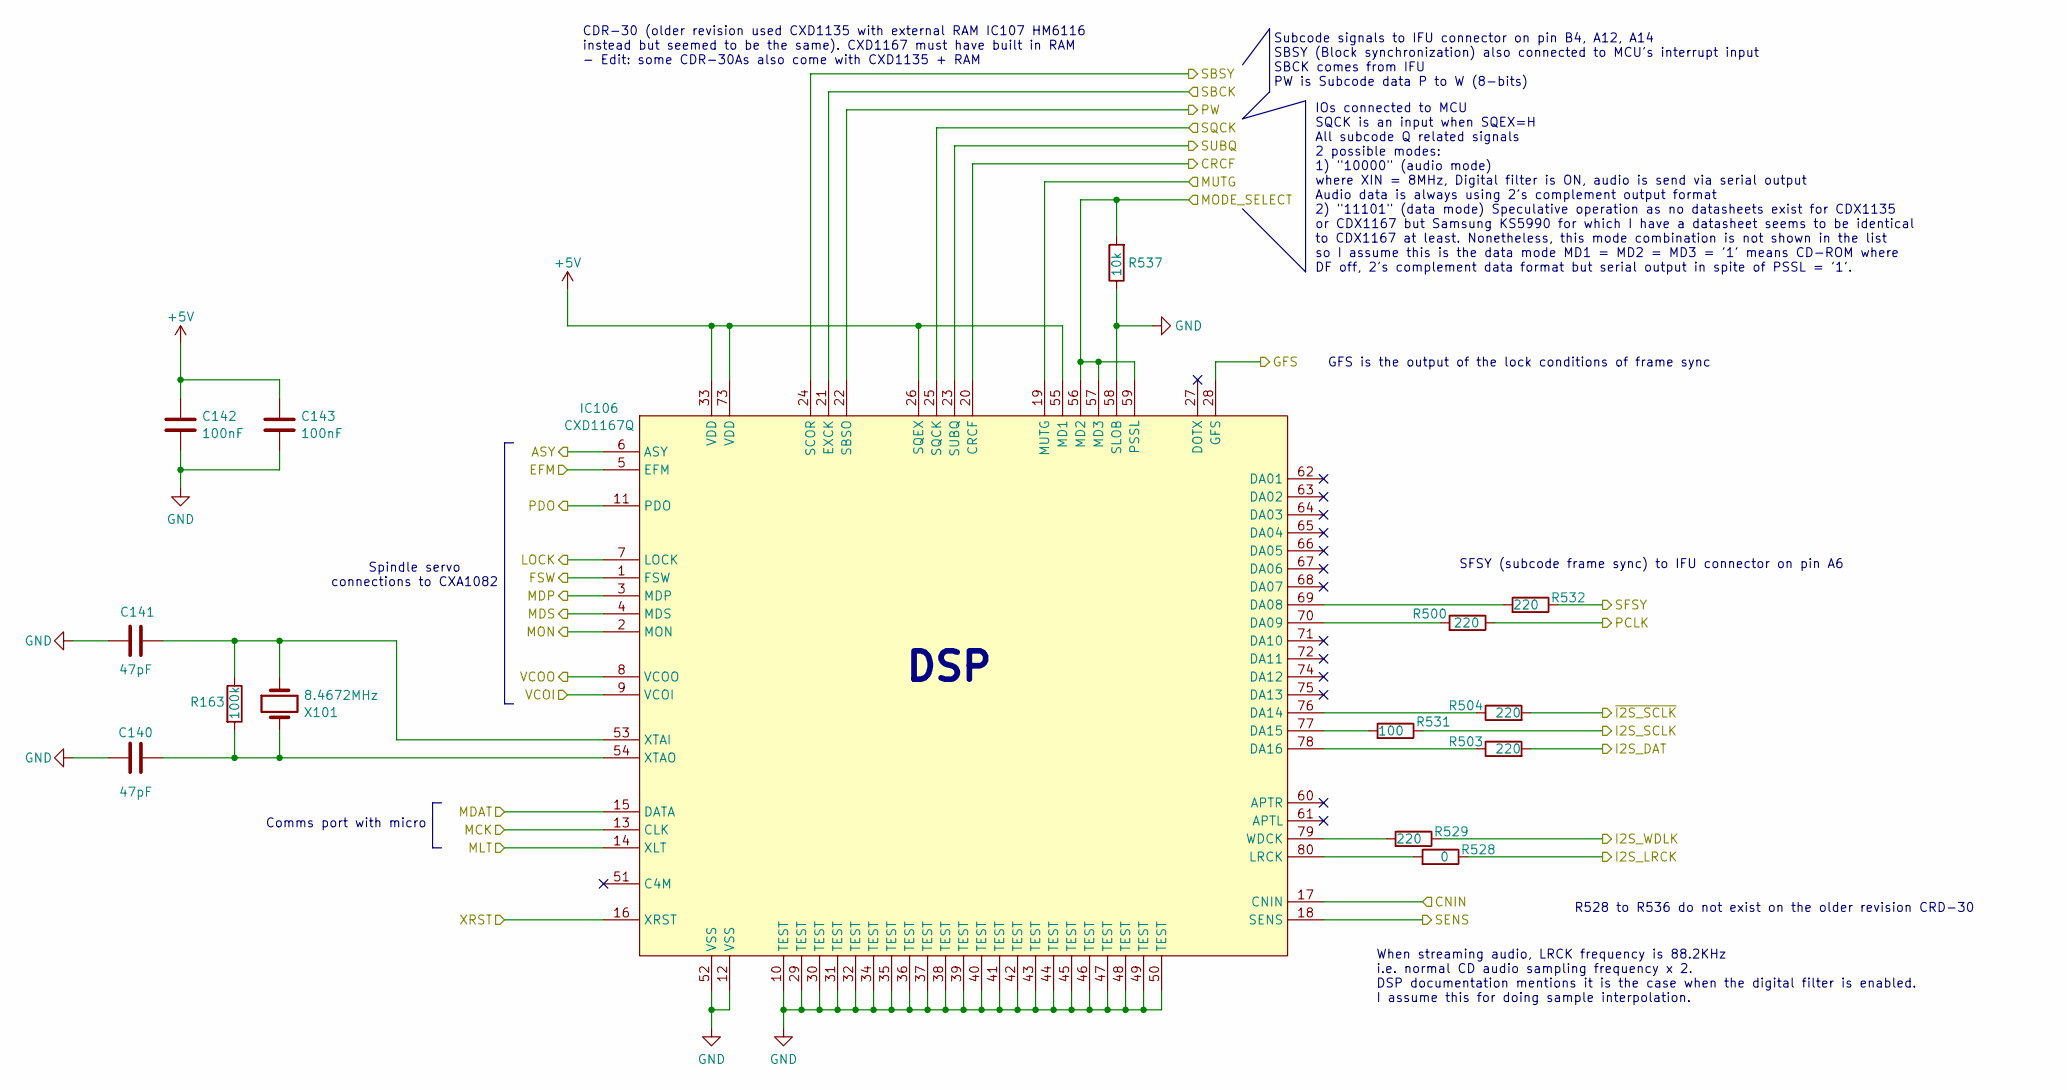
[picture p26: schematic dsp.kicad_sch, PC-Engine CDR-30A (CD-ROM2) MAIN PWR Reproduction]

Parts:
C140, C141: 47pF; C_0603_1608Metric
C142, C143: 100nF; C_0603_1608Metric
IC106: CXD1167Q; PQFP-80_14x20mm_P0.8mm
R163: 100k; R_0603_1608Metric
R500, R503, R504, R529, R532: 220; R_0603_1608Metric
R528: 0; R_0603_1608Metric
R531: 100; R_0603_1608Metric
R537: 10k; R_0603_1608Metric
X101: 8.4672MHz; Crystal_HC18-U_Horizontal

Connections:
+5V: C142.1, C143.1, IC106.26 (SQEX), IC106.33 (VDD), IC106.55 (MD1), IC106.73 (VDD); also elsewhere on the board
/CNIN: IC106.17 (CNIN); also elsewhere on the board
/CRCF: IC106.20 (CRCF); also elsewhere on the board
/DSP/ASY: IC106.6 (ASY); also elsewhere on the board
/DSP/EFM: IC106.5 (EFM); also elsewhere on the board
/DSP/PCLK: R500.1; also elsewhere on the board
/FSW: IC106.1 (FSW); also elsewhere on the board
/GFS: IC106.28 (GFS); also elsewhere on the board
/I2S_DAT: R503.2; also elsewhere on the board
/I2S_LRCK: R528.1; also elsewhere on the board
/I2S_SCLK: R531.1; also elsewhere on the board
/I2S_WDLK: R529.1; also elsewhere on the board
/LOCK: IC106.7 (LOCK); also elsewhere on the board
/MCK: IC106.13 (CLK); also elsewhere on the board
/MDAT: IC106.15 (DATA); also elsewhere on the board
/MDP: IC106.3 (MDP); also elsewhere on the board
/MDS: IC106.4 (MDS); also elsewhere on the board
/MLT: IC106.14 (XLT); also elsewhere on the board
/MODE_SELECT: IC106.56 (MD2), IC106.57 (MD3), IC106.59 (PSSL), R537.2; also elsewhere on the board
/MON: IC106.2 (MON); also elsewhere on the board
/MUTG: IC106.19 (MUTG); also elsewhere on the board
/PDO: IC106.11 (PDO); also elsewhere on the board
/PW: IC106.22 (SBSO); also elsewhere on the board
/SBCK: IC106.21 (EXCK); also elsewhere on the board
/SBSY: IC106.24 (SCOR); also elsewhere on the board
/SENS: IC106.18 (SENS); also elsewhere on the board
/SFSY: R532.1; also elsewhere on the board
/SQCK: IC106.25 (SQCK); also elsewhere on the board
/SUBQ: IC106.23 (SUBQ); also elsewhere on the board
/VCOI: IC106.9 (VCOI); also elsewhere on the board
/VCOO: IC106.8 (VCOO); also elsewhere on the board
/XRST: IC106.16 (XRST); also elsewhere on the board
/~I2S_SCLK: R504.2; also elsewhere on the board
GND: C140.1, C141.2, C142.2, C143.2, IC106.10 (TEST), IC106.12 (VSS), IC106.29 (TEST), IC106.30 (TEST), IC106.31 (TEST), IC106.32 (TEST), IC106.34 (TEST), IC106.35 (TEST), IC106.36 (TEST), IC106.37 (TEST), IC106.38 (TEST), IC106.39 (TEST), IC106.40 (TEST), IC106.41 (TEST), IC106.42 (TEST), IC106.43 (TEST), IC106.44 (TEST), IC106.45 (TEST), IC106.46 (TEST), IC106.47 (TEST), IC106.48 (TEST), IC106.49 (TEST), IC106.50 (TEST), IC106.52 (VSS), IC106.58 (SLOB), R537.1; also elsewhere on the board
unnamed: IC106.69 (DA08), R532.2
unnamed: IC106.70 (DA09), R500.2
unnamed: IC106.76 (DA14), R504.1
unnamed: IC106.77 (DA15), R531.2
unnamed: IC106.78 (DA16), R503.1
unnamed: IC106.80 (LRCK), R528.2
unnamed: IC106.79 (WDCK), R529.2
unnamed: C141.1, IC106.53 (XTAI), R163.1, X101.1
unnamed: C140.2, IC106.54 (XTAO), R163.2, X101.2

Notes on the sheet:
DSP
Comms port with micro
When streaming audio, LRCK frequency is 88.2KHz i.e. normal CD audio sampling frequency x 2. DSP documentation mentions it is the case when the digital filter is enabled. I assume this for doing sample interpolation.
GFS is the output of the lock conditions of frame sync
Subcode signals to IFU connector on pin B4, A12, A14 SBSY (Block synchronization) also connected to MCU's interrupt input SBCK comes from IFU PW is Subcode data P to W (8-bits)
R528 to R536 do not exist on the older revision CRD-30
IOs connected to MCU SQCK is an input when SQEX=H All subcode Q related signals 2 possible modes: 1) "10000" (audio mode) where XIN = 8MHz, Digital filter is ON, audio is send via serial output Audio data is always using 2's complement output format 2) "11101" (data mode) Speculative operation as n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
CDR-30 (older revision used CXD1135 with external RAM IC107 HM6116 instead but seemed to be the same). CXD1167 must have built in RAM - Edit: some CDR-30As also come with CXD1135 + RAM
Spindle servo connections to CXA1082
SFSY (subcode frame sync) to IFU connector on pin A6

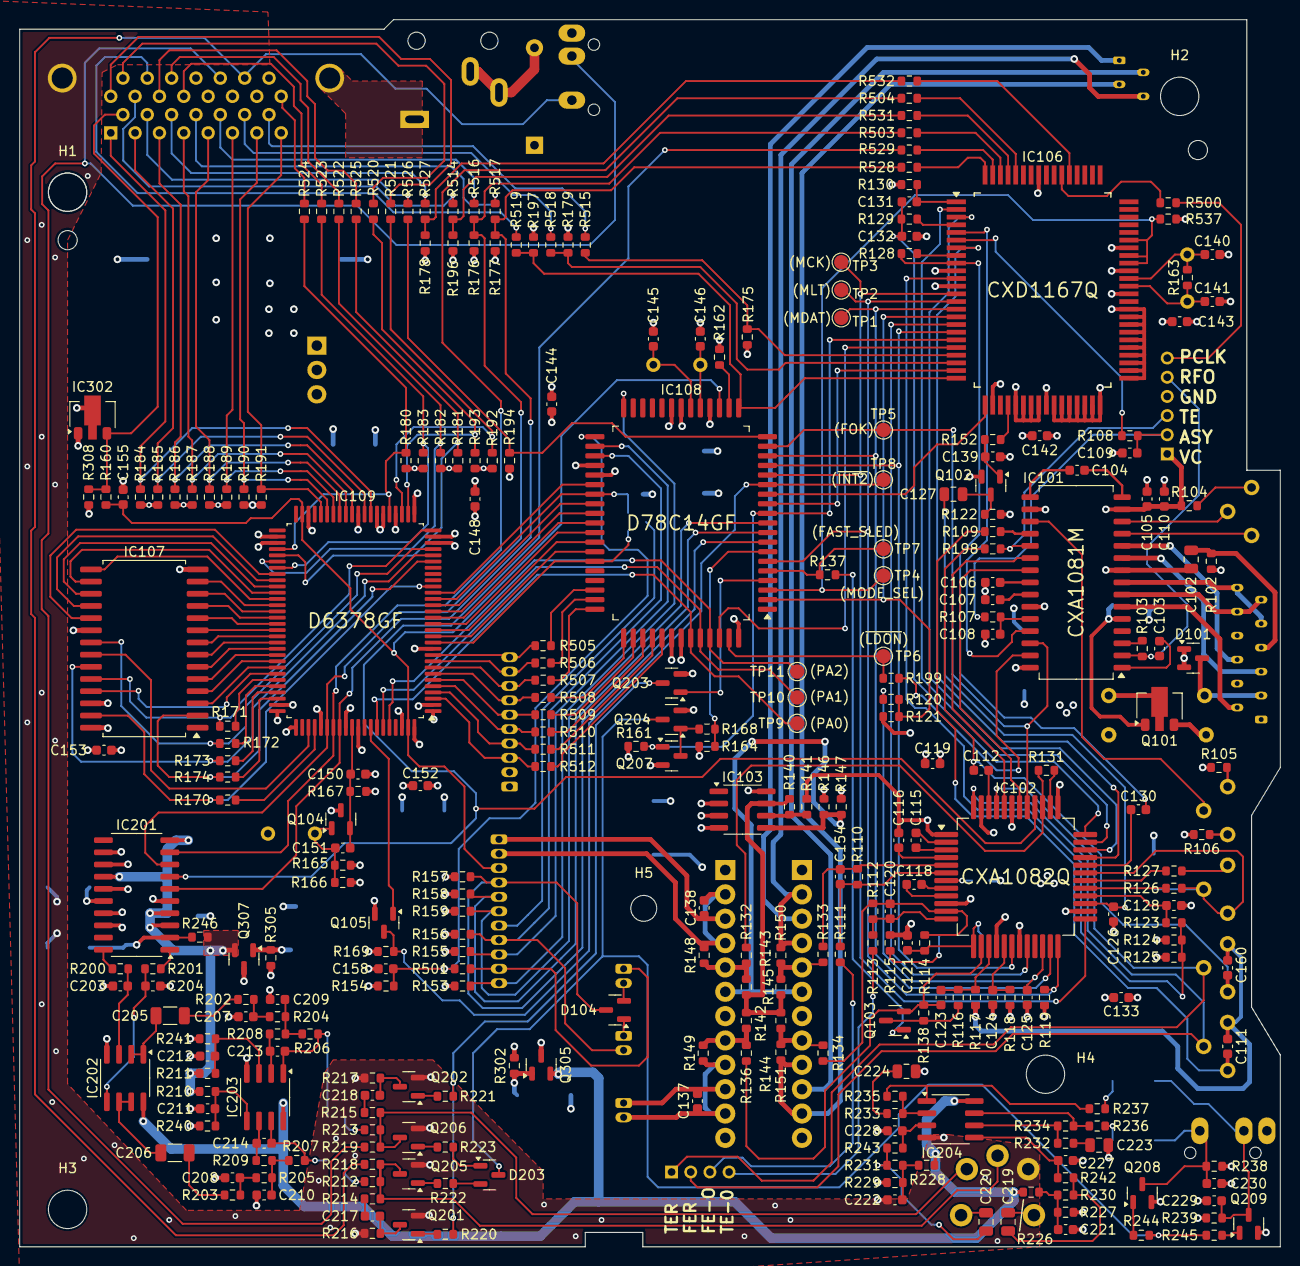
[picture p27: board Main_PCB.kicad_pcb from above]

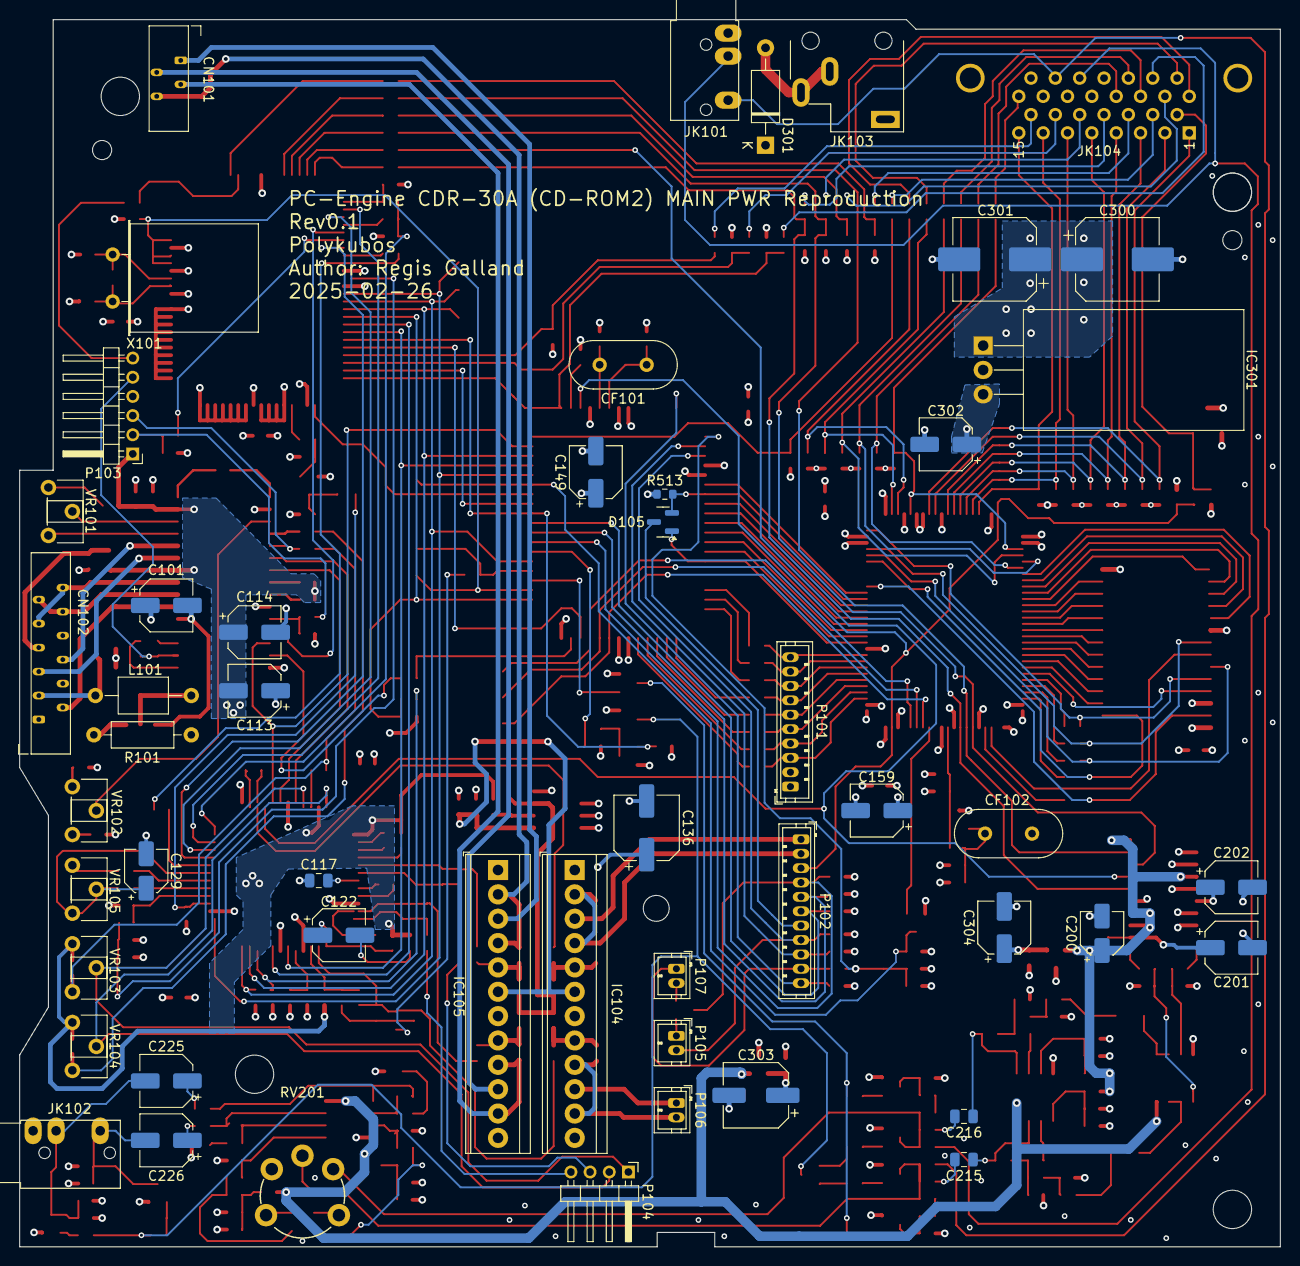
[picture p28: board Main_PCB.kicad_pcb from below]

Board: 4 copper layers, 131.5 x 128.0 mm, 342 parts (51 on the bottom side), 301 nets.

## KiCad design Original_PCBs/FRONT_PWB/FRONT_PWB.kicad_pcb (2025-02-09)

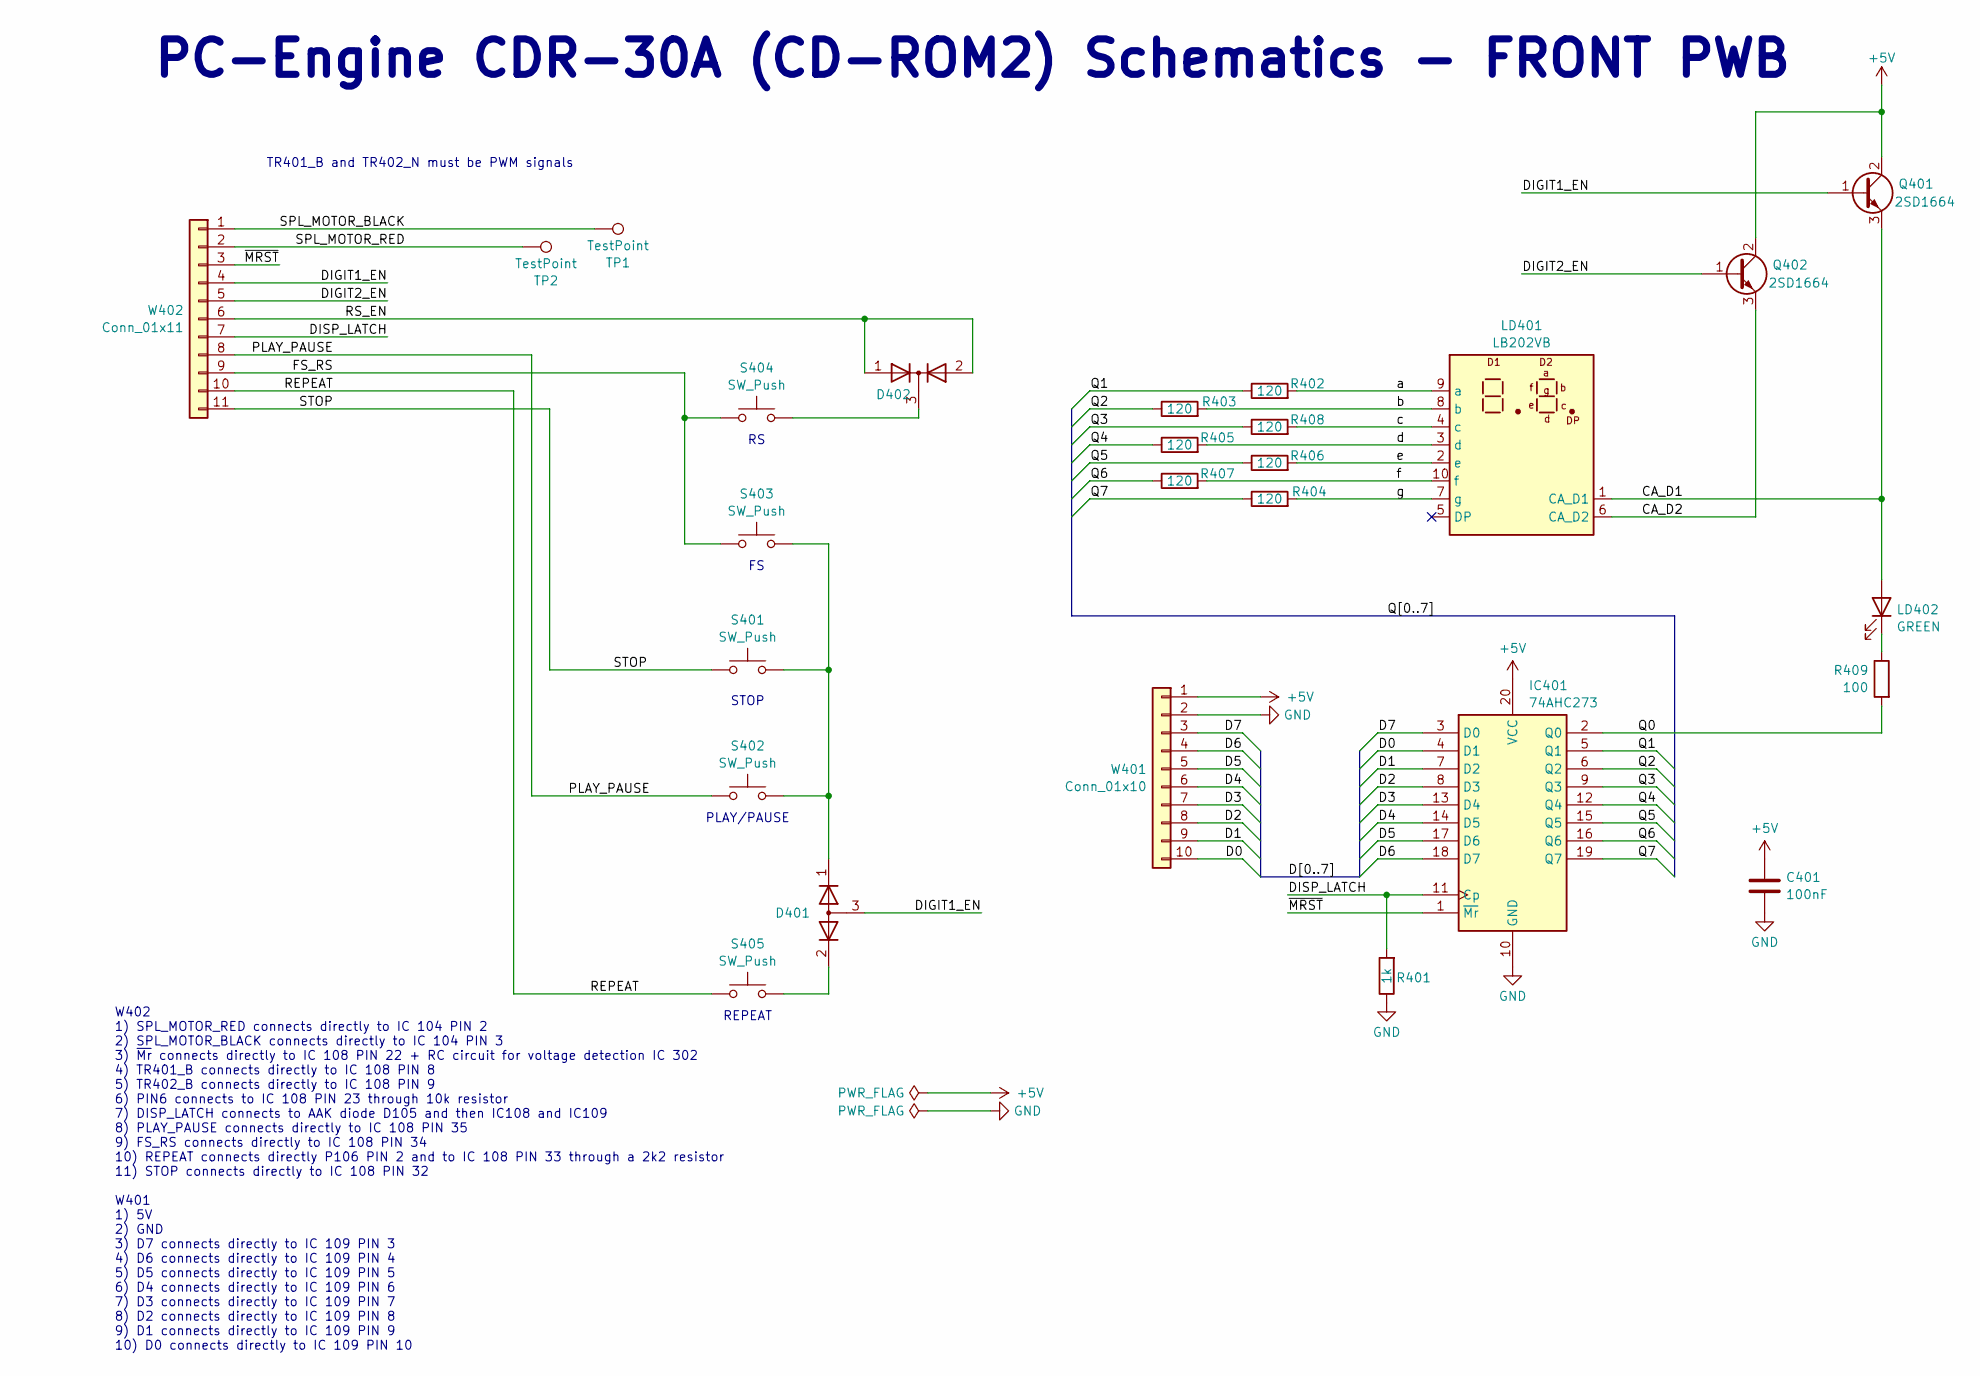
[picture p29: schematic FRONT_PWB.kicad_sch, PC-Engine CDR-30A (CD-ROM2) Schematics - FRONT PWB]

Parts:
C401: 100nF; C_0805_2012Metric
D401: D_Zener_Dual_CommonAnode_KKA; SOT-23
D402: D_Dual_CommonCathode_AAK; SOT-23
IC401: 74AHC273; SOIC-20W_7.5x12.8mm_P1.27mm
LD401: LB202VB; ELD_426XXXX
LD402: GREEN; LED_D3.0mm
Q401, Q402: 2SD1664; SOT-89-3
R401: 1k; R_0805_2012Metric
R402, R403, R404, R405, R406, R407, R408: 120; R_0805_2012Metric
R409: 100; R_0805_2012Metric
S401, S402, S403, S404, S405: SW_Push; SW_PUSH_6mm_H4.3mm
TP1, TP2: TestPoint; TestPoint_Pad_D3.0mm
W401: Conn_01x10; JST_ZE_B10B-ZESK-1D_1x10_P1.50mm_Vertical
W402: Conn_01x11; JST_ZE_B11B-ZESK-1D_1x11_P1.50mm_Vertical

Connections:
+5V: C401.1, IC401.20 (VCC), Q401.2 (C), Q402.2 (C), W401.1
/CA_D1: LD401.1 (CA_D1), LD402.2 (A), Q401.3 (E)
/CA_D2: LD401.6 (CA_D2), Q402.3 (E)
/D0: IC401.4 (D1), W401.10
/D1: IC401.7 (D2), W401.9
/D2: IC401.8 (D3), W401.8
/D3: IC401.13 (D4), W401.7
/D4: IC401.14 (D5), W401.6
/D5: IC401.17 (D6), W401.5
/D6: IC401.18 (D7), W401.4
/D7: IC401.3 (D0), W401.3
/DIGIT1_EN: D401.3 (A), Q401.1 (B), W402.4
/DIGIT2_EN: Q402.1 (B), W402.5
/DISP_LATCH: IC401.11 (Cp), R401.2, W402.7
/FS_RS: S403.2, S404.2, W402.9
/PLAY_PAUSE: S402.1, W402.8
/Q0: IC401.2 (Q0), R409.2
/Q1: IC401.5 (Q1), R402.1
/Q2: IC401.6 (Q2), R403.1
/Q3: IC401.9 (Q3), R408.1
/Q4: IC401.12 (Q4), R405.1
/Q5: IC401.15 (Q5), R406.1
/Q6: IC401.16 (Q6), R407.1
/Q7: IC401.19 (Q7), R404.1
/REPEAT: S405.2, W402.10
/RS_EN: D402.1 (A), D402.2 (A), W402.6
/SPL_MOTOR_BLACK: TP1.1, W402.1
/SPL_MOTOR_RED: TP2.1, W402.2
/STOP: S401.1, W402.11
/a: LD401.9 (a), R402.2
/b: LD401.8 (b), R403.2
/c: LD401.4 (c), R408.2
/d: LD401.3 (d), R405.2
/e: LD401.2 (e), R406.2
/f: LD401.10 (f), R407.2
/g: LD401.7 (g), R404.2
/~MRST: IC401.1 (~Mr), W402.3
GND: C401.2, IC401.10 (GND), R401.1, W401.2
unnamed: D401.1 (K), S401.2, S402.2, S403.1
unnamed: D401.2 (K), S405.1
unnamed: D402.3 (K), S404.1
unnamed: LD402.1 (K), R409.1

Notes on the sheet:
TR401_B and TR402_N must be PWM signals
STOP
W402 1) SPL_MOTOR_RED connects directly to IC 104 PIN 2 2) SPL_MOTOR_BLACK connects directly to IC 104 PIN 3 3) ~{Mr} connects directly to IC 108 PIN 22 + RC circuit for voltage detection IC 302 4) TR401_B connects directly to IC 108 PIN 8 5) TR402_B connects directly to IC 108 PIN 9 6) PIN6 connec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
REPEAT
PLAY/PAUSE
PC-Engine CDR-30A (CD-ROM2) Schematics - FRONT PWB

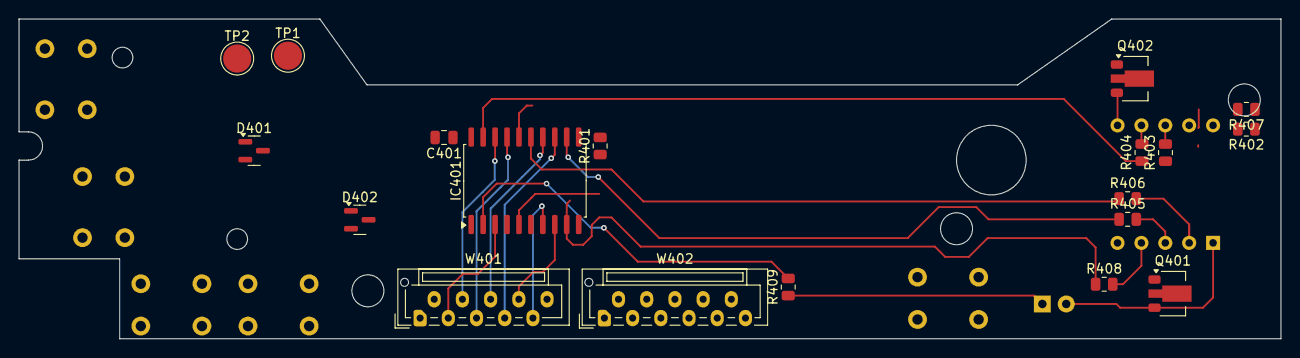
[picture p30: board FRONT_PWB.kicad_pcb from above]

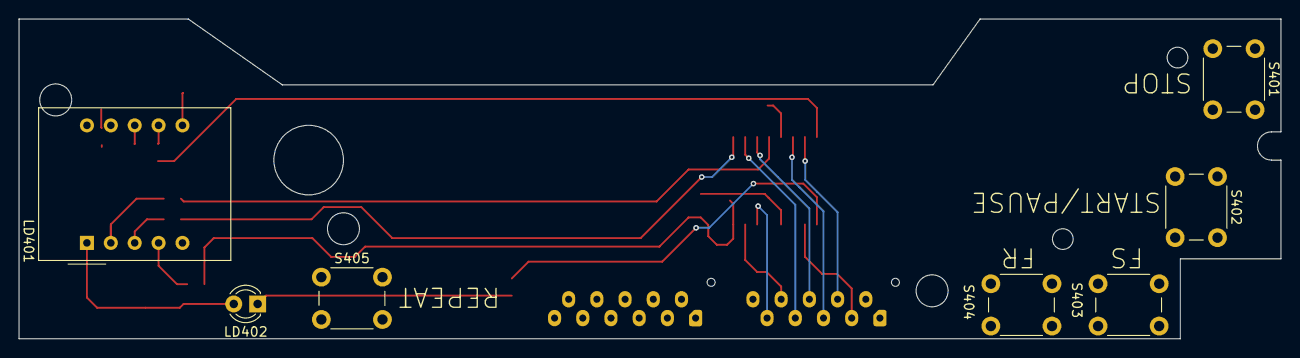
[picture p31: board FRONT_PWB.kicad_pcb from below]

Board: 2 copper layers, 134.2 x 34.0 mm, 26 parts (7 on the bottom side), 42 nets.

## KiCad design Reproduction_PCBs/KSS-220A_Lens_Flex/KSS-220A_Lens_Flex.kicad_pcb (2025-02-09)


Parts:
CN3: Photodetector_Flex_Conn; FLEX_SOIC-LIKE_8_3.9x4.9mm_P1.27mm
CN4: Flex_PCB_Edge_Conn_01x12_P1.25mm; Flexible_PCB_Conn_1x12_P1.25mm
CN5: Laser_Diode_Flex_Conn_3P; Laser_Diode_Pads
D1: Diode_Flex; Diode_Flex_Pads
H1: MountingHole_Flex_Pad_MP; MountingHole_1.6mm_Pad
RV1: R_Potentiometer_Flex; Potentiometer_Flex_Pads

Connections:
/A: CN3.6 (A), CN4.11
/B: CN3.8 (B), CN4.12
/C: CN3.3 (C), CN4.10
/D: CN3.1 (D), CN4.9
/E: CN3.7 (E), CN4.6
/F: CN3.2 (F), CN4.5
/GND1: CN4.8
/GND2: CN4.4, CN5.2 (GND), D1.2 (A), H1.MP
/GND3: CN4.1, RV1.1
/K: CN3.5 (K), CN4.7
/LD: CN4.3, CN5.3 (LD), D1.1 (K)
/PD: CN4.2, CN5.1 (PD), RV1.2, RV1.3

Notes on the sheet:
PHOTODETECTOR
KSM-220 Optical Pick-Up Block (1/2) KSM-162 uses a different Flexible PCB
LASER DIODE
MAIN-PWR CN102
VR and the two Grounds are not actually grounded on the KSS-220 but on the CDR-30 main board. To make things easier, we will ground them on the replacement loom.


Board: 2 copper layers, 61.9 x 82.6 mm, 6 parts (0 on the bottom side), 11 nets.

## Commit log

2024-05-11 Note added about DSP + external RAM also found in some CDR-30As. .gitattributes files added
    [dsp.kicad_sch]
2024-07-19 Small Schematics update to tidy signals attached to SCSI and MCU chips.
    [MAIN_PWR.kicad_pcb, MAIN_PWR.kicad_sch, audio.kicad_sch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]
2024-07-30 Small update, some typo fixes, more comments added to help understanding
    [FRONT_PWB.kicad_sch, MAIN_PWR.kicad_sch, audio.kicad_sch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]
2024-08-16 KSS-220A Flexible PCBs ready and on order for trial.
    [KSS-220A.kicad_pcb, KSS-220A.kicad_sch, MAIN_PWR.kicad_sch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]
2025-02-09 New structure for all PCBs related to NEC CDR-30A (PCE CD-ROM2)
    [FRONT_PWB.kicad_pcb, FRONT_PWB.kicad_sch, Focus_Tracking_Flex.FCStd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]
2025-02-24 Subdirectory added as submodule by mistake.
    [Main_PCB-B_Cu.gbr, Main_PCB-B_Mask.gbr, Main_PCB-B_Paste.gbr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]
2025-02-24 Final fixes to include some ectra mounting holes + GND connection to shield
    [Main_PCB-B_Cu.gbr, Main_PCB-B_Mask.gbr, Main_PCB-B_Paste.gbr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]
2025-02-26 Final commit before ordering
    [Main_PCB-B_Cu.gbr, Main_PCB-B_Mask.gbr, Main_PCB-B_Paste.gbr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]
